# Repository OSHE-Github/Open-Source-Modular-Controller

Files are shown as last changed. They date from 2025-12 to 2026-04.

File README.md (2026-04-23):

# Open Source Modular Controller

Using a modular, reconfigurable hardware architecture to create a customizable USB HID game controller.

## Project Details

The Open Source Modular Controller project is a fully modular and customizable gaming input system. Users can freely rearrange joysticks, buttons, and future input modules on a set of interchangeable receiver boards to build a layout that fits their gameplay style, ergonomic needs, or accessibility requirements.

The controller connects over USB and is recognized as a standard Human Interface Device (HID) with no additional drivers required.

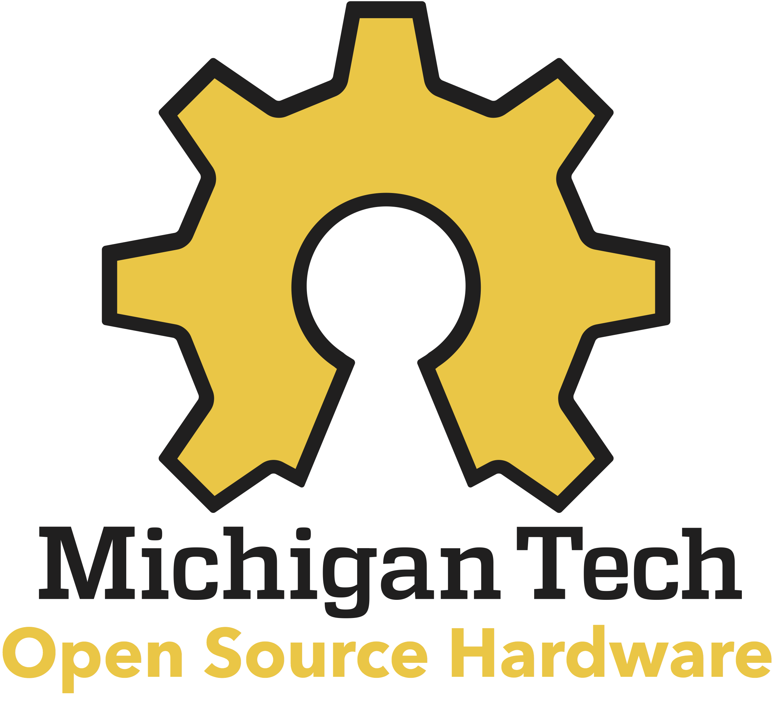
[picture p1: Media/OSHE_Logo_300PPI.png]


## Current State

The current prototype includes:
- A functional ESP32‑S3‑based main controller
- Hot-swappable joystick and button modules
- Receiver boards that can be placed anywhere in the 3D‑printed shell
- USB HID communication via TinyUSB

The system operates as a recognized USB gamepad on Windows. Some hardware issues were identified and corrected in updated revisions.

## Project Structure

The repository is organized as follows:
1. **Firmware** – ESP32‑S3 code handling HID communication and module input processing.  
   *Link: [Firmware](/Controller%20Code/Firmware.md)*
2. **Software** – PC‑side utilities or test scripts (coming soon).  
3. **Hardware** – KiCad project files, schematics, PCBs, and 3D‑printed shell models.  
   *Link: [Hardware](/Hardware/Hardware.md)*
4. **Documentation** – Assembly instructions, diagrams, semester report, and testing notes.  
   *Link: [Documentation](/Documents/Documents.md)*

## Features

- Modular input modules (buttons, joystick, future sensors)
- Repositionable input layout using multiple receiver boards
- ESP32‑S3 native USB HID support
- Open‑source hardware and firmware
- 3D‑printable ergonomic controller shell

## System Architecture

Core system components include:
- **Receiver boards** distributing power, signals, and micro-controller
- **Module boards** for inputs (joystick/button)
- **3D‑printed enclosure** with heat‑set inserts for secure mounting

USB HID enumeration and report handling are implemented using TinyUSB. Modules communicate through standardized connectors to the controller board.

## Bill of Materials
A full BOM including the ESP32‑S3 boards, connector sets, resistors, capacitors, PCBs, wire, and 3D‑printed components is provided in the documentation.  
*[BOM](/Documents/BOM.md)*

## Tools Used
### Software
- Arduino IDE
- KiCad
- OnShape (frame design)
- GitHub Desktop
- Cura slicer

### Hardware
- 3D printer
- Soldering iron
- Hot air station
- Multimeter
- Tweezers

## Assembly Overview
1. Gather materials (refer to BOM).  
2. Order PCBs (Gerber files included).  
3. 3D print shell and module housings.  
4. Clean and prepare boards.  
5. Solder components (headers, ESP32 module, connectors, buttons/joysticks).  
6. Upload firmware via Arduino IDE.  
7. Install modules into the shell.  
8. Test controller.  

[Full assembly guide](/Documents/Assembly%20guide.md)

## What the Project Could Use Next
1. On‑board processing for more advanced input mapping
2. PCB adjustment and testing
3. Wireless mode using Bluetooth HID
4. Additional module types (battery, gyroscope, sliders, touchpads)

## Semester End Report
For the Enterprise Program at Michigan Tech there is a end of semester and project report for the project to summarize the progress of the project. [Link](/Documents/Final%20Report%20Spring%202026.pdf)

## Acknowledgements
This project is supported by the Open Source Hardware Enterprise at Michigan Technological University.

## Helpful Links
- [TinyUSB](https://docs.tinyusb.org/en/latest/)
- [Gamepad tester](https://hardwaretester.com/gamepad)

## References

[GitHub Doc](https://docs.github.com/en/get-started/writing-on-github/getting-started-with-writing-and-formatting-on-github/basic-writing-and-formatting-syntax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)

[Alpakka conroller](https://inputlabs.io/alpakka)

[Proteus ControllerTM kit](https://byowave.com/products/proteus-controller )

[Thrustmaster](https://eshop.thrustmaster.com/en_us/gamepads/pc.html)

[Adafruit ADS1X15 Library](https://github.com/adafruit/Adafruit_ADS1X15)

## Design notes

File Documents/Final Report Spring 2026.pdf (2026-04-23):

# Project Report: Open Source Modular Controller

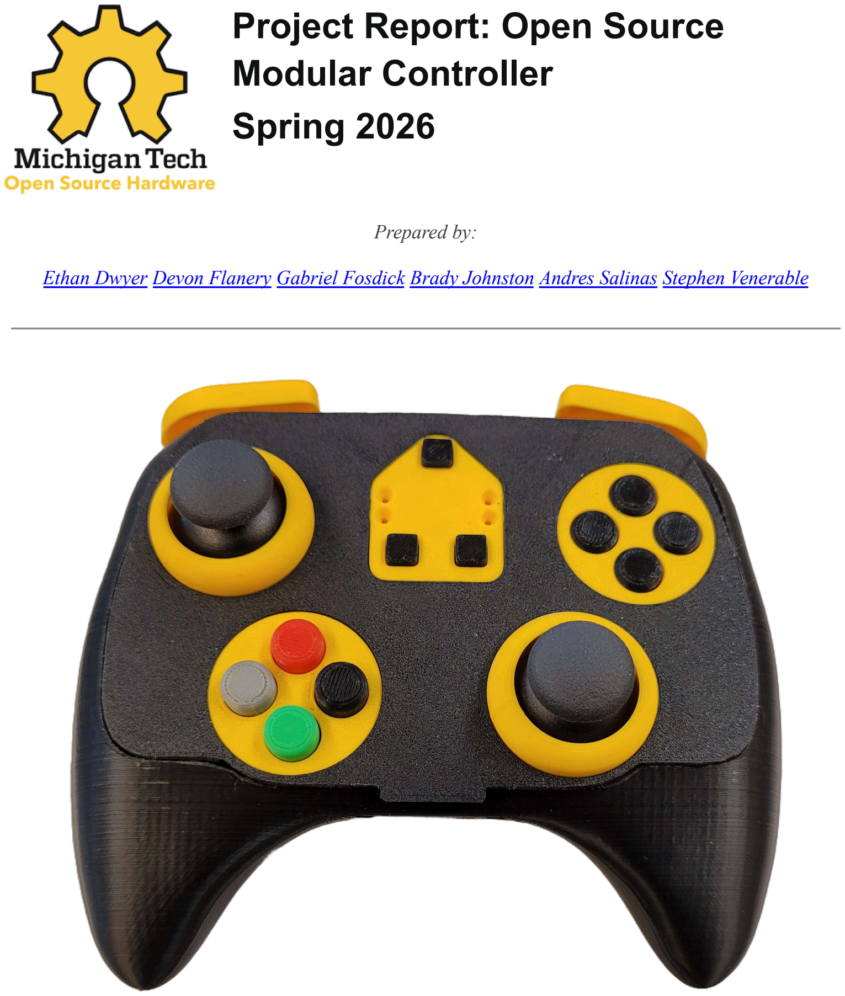
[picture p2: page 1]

# Spring 2026

Prepared by:

Ethan Dwyer Devon Flanery Gabriel Fosdick Brady Johnston Andres Salinas Stephen Venerable

## Table of Contents:

## Executive Summary:

The goal of this project is to design and develop an open-source modular game controller compatible with modern gaming and computing systems. The controller features interchangeable input modules that enable users to customize both the layout and physical placement of controls based on game genre, personal preference, or accessibility needs. By supporting a variety of input types and configurations, the system can be tailored for diverse users and applications, from video games to robotics control. Once assembled, the controller connects directly to standard devices using USB and is recognized as a Human Interface Device (HID) without additional drivers.

Core Technology

At the foundation of the system is the TinyUSB library, which allows communication within the USB HID framework. This approach eliminates the need for dedicated drivers and ensures compatibility across Windows, macOS, and Linux platforms, providing a plug-and-play experience for end users. On top of that is the i2c protocol that communicates between the modules and the Microcontroller, that handles the identification and input data streaming.

Innovation

The project’s defining innovation lies in its fully modular and spatially flexible architecture. Each controller consists of removable button and joystick modules that attach to detachable receiver boards. These receiver boards can be placed anywhere on a custom chassis, giving users the freedom to design their own controller shapes and ergonomics. This allows complete reconfiguration of both the electronic and physical layout, something not possible with commercial controllers. The system is designed to be approachable for those with little to no electronics experience while remaining highly extensible for makers and developers.

Development Highlights

Over the course of the semester, the team refined and developed the second-generation receiver boards and the two modules: a button input and a joystick, with the addition of a bumper/trigger module. The base system successfully interfaced with a Windows PC and functioned in real-world gaming scenarios. Future work will expand on this foundation by adding module identification and refining the communication protocol to support more features.

Impact

This project represents a meaningful advancement in customizable controller design. Its modular and repositionable hardware offers new possibilities for makers, competitive gamers, and individuals with physical disabilities, enabling truly personalized ergonomics and input arrangements. By combining open-source firmware with hardware flexibility, the system empowers users to create, share, and refine their own control interfaces, making high-performance and adaptive hardware accessible to everyone.

## Main Product Image:

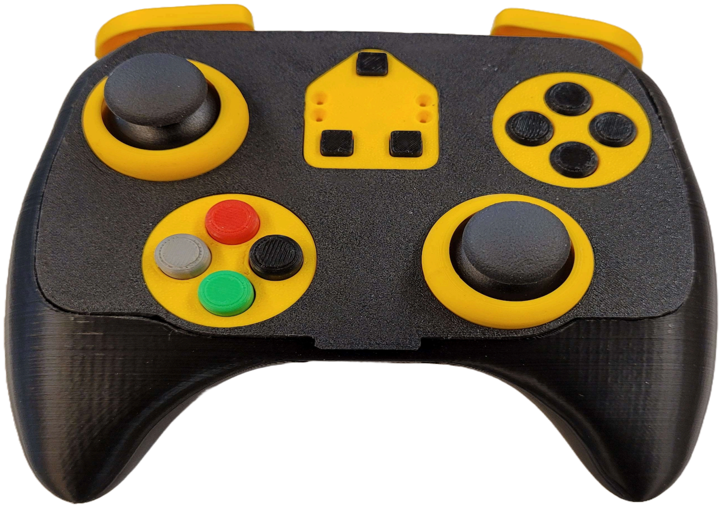
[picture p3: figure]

Figure 1: Main Controller Image

## Project Description:

The project was the design and implementation of a functional prototype for a modular, open-source game controller compatible with modern computing systems. The primary goal was to develop a controller system in which every major input—joysticks, buttons, and future modules—can be physically rearranged or replaced, giving users the freedom to build a controller layout that matches their play style or accessibility needs.

The first semester's development began with a breadboard-based proof of concept used to verify signal routing, input functionality, and USB communication. Once validated, the team progressed to designing custom printed circuit boards (PCBs) for the joystick and button modules, the receiver boards, and an ESP32-based carrier board serving as the main controller.

This second semester’s focused on the modularity and hot-swapability of the different modules and making the enclosure more comfortable for the users . This was done by switching the modules to integrated circuits that have i2c compatibility so all the modules can share the same communication bus.

A 3D-printed enclosure was then modeled and fabricated to house the assembled electronics. Each receiver board connects to the module boards through pogo header pins or JST connectors, allowing the modules to be placed anywhere within a custom chassis. This spatial flexibility is the defining feature of the system, enabling users to create their own controller shapes and layouts to suit personal or accessibility requirements.

The controller’s firmware utilizes the TinyUSB library to manage communication through the USB Human Interface Device (HID) framework, ensuring plug-and-play functionality without custom drivers. The current prototype successfully interfaces with Windows systems and is fully recognized as a standard game controller. Although additional inputs such as bumpers and triggers are planned for future iterations, the completed prototype establishes a robust hardware and software foundation for a fully modular and reconfigurable controller platform.

## Methodology:

System Architecture

The modular controller system was built around the ESP32-S3 microcontroller, chosen for its native support of both USB and Bluetooth HID (Human Interface Device) communication. This capability allows the controller to function as a USB peripheral without the need for custom drivers and provide wireless compatibility for future iterations of this project. The ESP32-S3 communicates the controller’s given inputs from each module to the host system. The transmission between the modules and microcontroller is done through a main receiver board.

The main receive board hosts the controller with standard connector pins and the modules with either pogo pins or JST connectors depending on the controller shell design. Using I2C the controller communicates with each module based on its type and position. Each module has a different I2C address based on which type of module it is (joystick, button, etc.) and an address translator placed at each slot provides a different position to the microcontroller.

USB HID Implementation

Communication between the controller and host system relies on the USB HID standard, which defines how input devices transmit data to computers and consoles. When a device is connected, the host begins a process called enumeration, during which it requests a series of descriptors from the device. These descriptors identify the device type, power requirements, and data structure:

- Device Descriptor: Specifies the vendor ID, product ID, and device class.
- Configuration and Interface Descriptors: Define endpoints, interfaces, and required power.

- HID and Report Descriptors: Describe the logical format of inputs such as buttons and joystick axes.
- String Descriptors (optional): Provide human-readable information, such as product name or manufacturer.

Once the enumeration sequence is complete, the device begins sending HID reports, which contain button states and analog axis values. These reports are continuously exchanged with the host to provide real-time input recognition. Using the TinyUSB library, the ESP32-S3 handles all enumeration, descriptor generation, and report formatting internally, allowing the controller to be recognized as a standard gamepad on Windows without additional drivers.

Component Selection and Design Considerations

Component selection emphasized functionality, modularity, and cost efficiency. The ESP32-S3 was selected for its integrated USB OTG interface, Bluetooth LE support, and sufficient processing resources for handling multiple modular inputs. Standard pin headers were chosen as the initial connection method between modules and receiver boards due to their availability, affordability, and mechanical stability. The current version transitions to magnetic pogo-pin connectors to simplify module swapping and improve durability.

All printed circuit boards (PCBs) were designed in-house and fabricated through a low-cost prototyping service. Careful attention was given to connector orientation, trace routing, and power distribution to ensure reliability and ease of assembly.

I2C Components

To further increase the modularity and functionality of the controller, we wanted to be able to automatically detect module changes while the controller was in use. We decided to implement this using I2C. Using SPI or adding small microcontrollers to each module were early ideas, but were quickly dismissed. We implemented this by adding I2C-capable IO expanders to each button module and I2C-capable ADCs to each joystick module. By scanning for I2C addresses, we were able to detect a module’s presence, as well as determine its type. The original plan was to store each module’s information data on an EEPROM, but we ran into some issues regarding this. Each module has an EEPROM soldered onto it, but our firmware does not utilize them. Input data from the buttons/joysticks is read by the IO Expander or ADC and then transmitted to the MCU through I2C.

Mechanical and Ergonomic Design

The physical design of the controller is built to house the main receiver board. The consistent shape and sizing enable the modularity of the controller. Each module, Joystick, Buttons, and Bumper, all have the same footprint for both ease of manufacturing and symmetry. The 3D-printed enclosure provides sufficient internal space for all modules. Extended side grips were added to improve handling during gameplay without compromising the modular placement of receivers.

Summary

This methodology established a repeatable framework for modular hardware development: from microcontroller selection and USB communication setup to enclosure design and fabrication. The resulting prototype demonstrates reliable USB HID communication, functional modular inputs, and a flexible architecture ready for continued expansion and refinement.

## Bill of Materials:

The current design uses a single, updated controller configuration built around the Seeed Studio XIAO ESP32-S3 Plus as the main microcontroller. This approach simplifies the overall system by standardizing the hardware across all modules and reducing assembly complexity. The design is divided into several functional boards including the receiver, button, joystick, bumper, and navigation boards each with its own supporting components such as EEPROMs, I/O expanders, resistors, and capacitors. Custom PCBs are used for each subsystem, along with pogo pin connections and JST connectors to enable modularity and easier assembly. This structure allows for a flexible and scalable controller design while keeping the total cost and component count manageable.

Table 1: Bill of materials

Part name | Desc | Qty. | Total | Link
Receiver Board | | Total
LTC4317 | Address Translator | 4 | $20.72 | Digikey.com (https://www.digikey.com/en/products/detail/analog-devices-inc/LTC4317CDHC-PBF/5297623)
24LC02BT-I/OT | 2 kbit EEPROM | 1 | $0.31 | Digikey.com (https://www.digikey.com/en/products/detail/microchip-technology/24LC02BT-I-OT/443519)
PCF8574DWR | 8 bit io expander | 1 | $1.99 | Digikey.com (https://www.digikey.com/en/products/detail/texas-instruments/PCF8574DWR/484579)
603_1208 metric | 10 uF capacitor | 3 | $0.03 | Digikey.com (https://www.digikey.com/en/products/detail/samsung-electro-mechanics/CL21A106KOQNNNE/3886754)
603_1208 metric | .1 uF capacitor | 4 | $0.24 | Digikey.com (https://www.digikey.com/en/products/detail/yageo/CC0603KRX7R7BB104/302822)
603_1208 metric | 10 kΩ resistors | 27 | $0.24 | Digikey.com (https://www.digikey.com/en/products/detail/yageo/RC0603FR-0710KL/726880)
XIAO ESP32-S3 Plus | Seeed Studio XIAO ESP32-S3 Plus | 1 | $7.90 | Seeedstudio.com (https://www.seeedstudio.com/Seeed-Studio-XIAO-ESP32S3-Plus-p-6361.html)
PCB | Main Receiver Board | 1 | $29.00
603_1208 metric | 0 kΩ resistors | 1 | $0.10 | Digikey.com (https://www.digikey.com/en/products/detail/yageo/RC0603JR-070RL/726675)
603_1208 metric | 102 kΩ resistors | 1 | $0.10 | Digikey.com (https://www.digikey.com/en/products/detail/yageo/RC0603FR-07102KL/726891)
603_1208 metric | 182 kΩ resistors | 1 | $0.10 | Digikey.com (https://www.digikey.com/en/products/detail/stackpole-electronics-inc/RMCF0603FT182K/1760990)
603_1208 metric | 280 kΩ resistors | 1 | $0.10 | Digikey.com (https://www.digikey.com/en/products/detail/yageo/RC0603FR-07280KL/727112)
603_1208 metric | 392 kΩ resistors | 1 | $0.10 | Digikey.com (https://www.digikey.com/en/products/detail/yageo/RC0603FR-07392KL/727201)
603_1208 metric | 523 kΩ resistors | 1 | $0.10 | Digikey.com (https://www.digikey.com/en/products/detail/yageo/RC0603FR-07523KL/727292)
603_1208 metric | 681 kΩ resistors | 1 | $0.10 | Digikey.com (https://www.digikey.com/en/products/detail/yageo/RT0603FRE07681KL/5929212)
603_1208 metric | 887 kΩ resistors | 1 | $0.10 | Digikey.com (https://www.digikey.com/en/products/detail/yageo/RC0603FR-07887KL/727417)
603_1208 metric | 976 kΩ resistors | 1 | $0.10 | Digikey.com (https://www.digikey.com/en/products/detail/yageo/RC0603FR-07976KL/727442)
603_1208 metric | 1 MΩ resistors | 5 | $0.40 | Digikey.com (https://www.digikey.com/en/products/detail/yageo/RC0603FR-071ML/726844)
1x8 smd pogo pins | Pogo pin connection | 8 | $42.48 | Digikey.com (https://www.digikey.com/en/products/detail/digikey-va/811-22-008-30-000101/682276)
JST SH 4-pin Connector | JST SH 4-pin Right Angle Connector (10-pack) - Qwiic Compatible | 1 | $3.95 | Adafruit.com (https://www.adafruit.com/product/4208)
Subtotal: | | 65 | $108.16

Part name | Desc | Qty. | Total | Link
Button Board
24LC02BT-I/OT | 2 kbit EEPROM | 1 | $0.31 | Digikey.com (https://www.digikey.com/en/products/detail/microchip-technology/24LC02BT-I-OT/443519)
PCF8574DWR | 8 bit io expander | 1 | $1.99 | Digikey.com (https://www.digikey.com/en/products/detail/texas-instruments/PCF8574DWR/484579)
SKQGABE010 | Button | 4 | $1.24 | Digikey.com (https://www.digikey.com/en/products/detail/alps-alpine/SKQGABE010/19529161)
PCB | Button Board | 1 | $7.00
Subtotal: | | 7 | $10.54
Joystick
24LC02BT-I/OT | 2 kbit EEPROM | 1 | $0.31 | Digikey.com (https://www.digikey.com/en/products/detail/microchip-technology/24LC02BT-I-OT/443519)
ADS1115IDGST | ADC | 1 | $6.29 | Digikey.com (https://www.digikey.com/en/products/detail/texas-instruments/ADS1115IDGST/2123298)
603_1208 metric | 10 kΩ resistors | 1 | $0.10 | Digikey.com (https://www.digikey.com/en/products/detail/yageo/RC0603FR-0710KL/726880)
9032 | Joysticks | 1 | $5.25 | Digikey.com (https://www.digikey.com/en/products/detail/sparkfun-electronics/09032/6823623)
PCB | Joysticks Board | 1 | $7.00
Subtotal: | | 5 | $18.95
Bumper Board
24LC02BT-I/OT | 2 kbit EEPROM | 1 | $0.31 | Digikey.com (https://www.digikey.com/en/products/detail/microchip-technology/24LC02BT-I-OT/443519)
PCF8574DWR | 8 bit io expander | 1 | $1.99 | Digikey.com (https://www.digikey.com/en/products/detail/texas-instruments/PCF8574DWR/484579)
PCB | Bumper Board | 1 | $7.00
Key switches | Switches for bumpers and triggers | 1 | $4.49 | Amazon.com (https://www.amazon.com/BlingKingdom-Replacement-Mechanical-Keyboard-Dustproof/dp/B0DSHTPSL3)
Subtotal: | | 4 | $13.79
Nav/master Board
24LC02BT-I/OT | 2 kbit EEPROM | 1 | $0.31 | Digikey.com (https://www.digikey.com/en/products/detail/microchip-technology/24LC02BT-I-OT/443519)
PCF8574DWR | 8 bit io expander | 1 | $1.99 | Digikey.com (https://www.digikey.com/en/products/detail/texas-instruments/PCF8574DWR/484579)
LTST-C193TBKT-5A | Blue LED | 4 | $0.72 | Digikey.com (https://www.digikey.com/en/products/detail/liteon/LTST-C193TBKT-5A/2053656)
B3F-1000 | Button | 4 | $0.96 | Digikey.com (https://www.digikey.com/en/products/detail/omron-electronics-inc-emc-div/B3F-1000/33150)
PCB | Nav Board | 1 | $7.00
319-10-104-00-006000 | pogo pin strikers | 3 | $8.94 | Digikey.com (https://www.digikey.com/en/products/detail/mill-max-manufacturing-corp/319-10-104-00-006000/5176105)
Subtotal: | | 14 | $19.92
Total: | | 95 | $171.36

## Tools Used:

Software

Table 2: Software used

Name | Description | Price | Link
GitHub Desktop | Used to share updates and
versions.
Free | GitHub.com (https://desktop.github.com/download/)
Arduino IDE | Used as the programming platform. | Free | Arduino.cc (https://docs.arduino.cc/software/ide/)
KiCAD | The program was used for creating
the PCB.
Free | KiCAD.com (https://www.kicad.org/)
OnShape | Used for the frame design. | Free | OnShape.com (https://www.onshape.com/en/)
Ultimaker Cura | Used as a slicer for the 3-D printed
glasses frame.
Free | Ultimaker.com (https://ultimaker.com/software/ultimaker-cura/)

Total Price

Hardware

Table 3: Hardware used

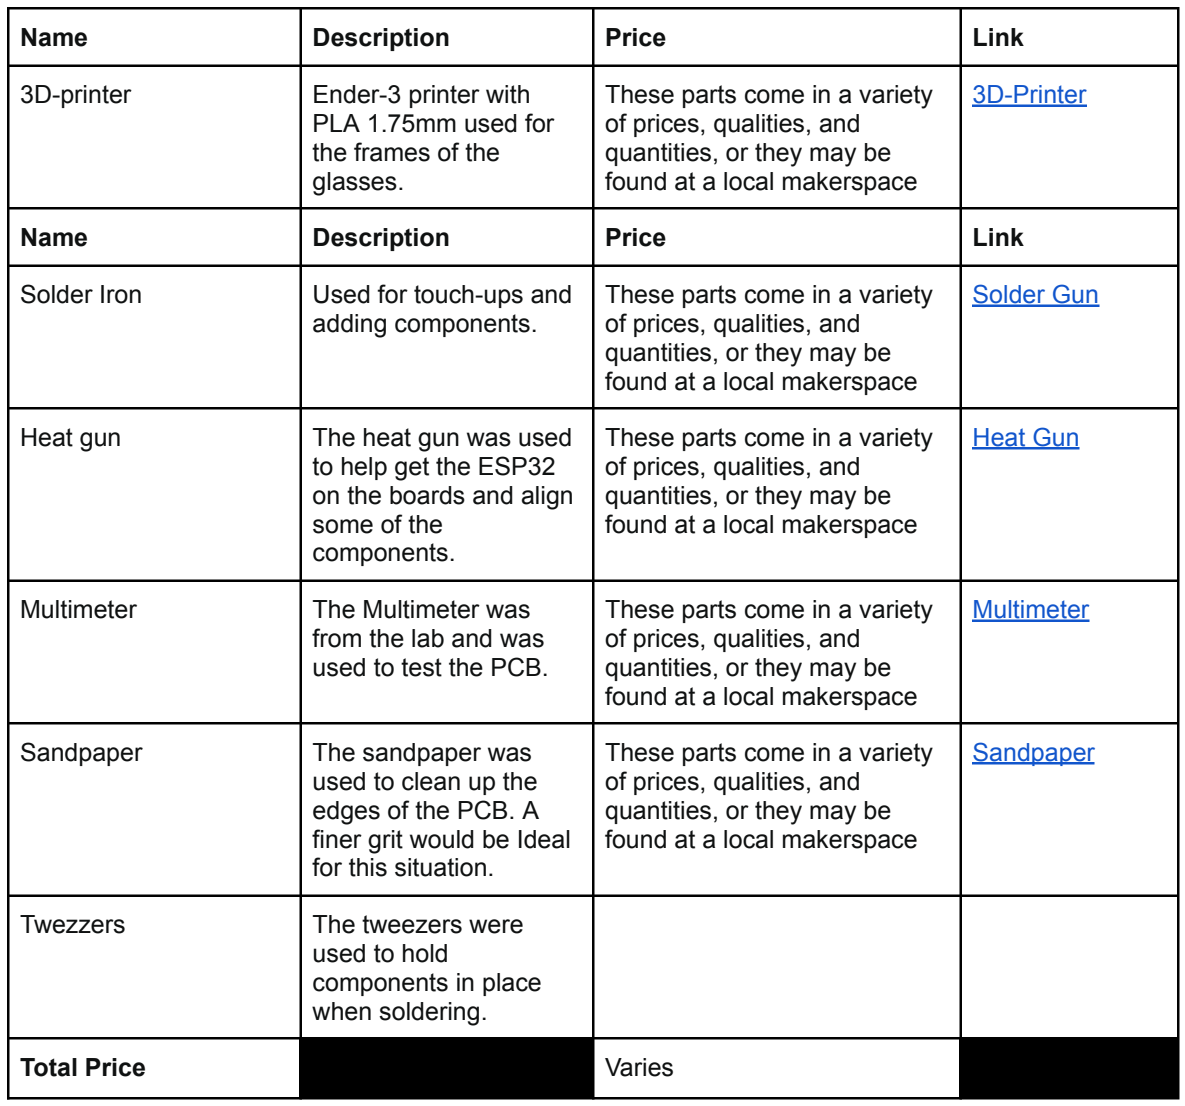
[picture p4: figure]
Name; Description; Price; Link; 3D-printer; Ender-3 printer with; PLA 1.75mm used for the frames of the glasses.; These parts come in a variety of prices, qualities, and quantities, or they may be found at a local makerspace; 3D-Printer; Solder Iron; Used for touch-ups and; adding components.; Solder Gun; Heat gun; The heat gun was used; to help get the ESP32 on the boards and align some of the components.; Heat Gun; Multimeter; The Multimeter was; from the lab and was used to test the PCB.; Sandpaper; The sandpaper was; used to clean up the edges of the PCB. A finer grit would be Ideal for this situation.; Twezzers; The tweezers were; used to hold components in place when soldering.; Total Price; Varies

## Assembly

### 1. Gather Materials

a. Refer to the BOM
b. Download the main GitHub repo branch (link) (https://github.com/OSHE-Github/Open-Source-Modular-Controller)

### 2. Order PCBs

a. Use our PCB manufacturer; the Gerber files are provided in the GitHub repository.

### 3. Print the Shells

a. The shells for the modules are located in the Github directory under Hardware/Module STLs
b. The standard configuration uses seven modules and each module requires the specified parts
i. 1 Master: 1 Master top casing, 1 Master bottom casing, 3 Master buttons
ii. | 2 Bumpers: 1 Joystick top casing, 1 Joystick bottom casing
iii. | 2 Joysticks: 1 Bumper body casing and 2 Bumper caps
iv. | 2 Buttons: 1 Button top casing, 1 Button Bottom casing, 4 non-Master buttons
c. The shell for the main body is located in the Github directory under
| Hardware/Shell/OSMC
i. The full casing can be printed from the .step file
ii. Individual parts can be printed from the .stl files

### 4. Prep the PCB

a. Lightly sand away any edge defects from manufacturing making sure not to
b. Lightly wipe with isopropyl alcohol

### 5. Solder Components

– In this production, blank boards were ordered, and most components were hand-soldered with a soldering iron, solder paste, and hot air soldering station.

a. Receiver Board
i. Start by soldering on all the SMD components such as the capacitors, resistors, and
| address translators. This is done easiest using a reflow oven or a hot pate.
ii. | Next, solder all of the pogo pins/pin headers and through hole components.
iii. | Finally, solder on the JST connectors if you want to have any off board modules.

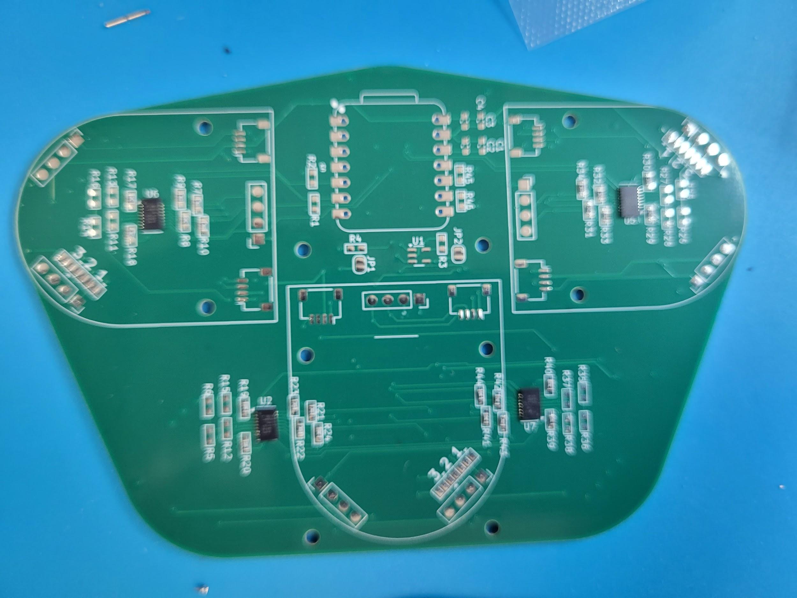
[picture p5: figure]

Figure 4: Receiver Board Module

b. Joystick Modules
i. Solder the joystick into the designated positions on the PCB, keeping each button flat against the board.
ii. | Inspect all joints to confirm solid solder connections and verify that the buttons click freely without obstruction.
iii. | Place the module in the joystick module shell, and mark the shell with where the up arrow is pointing.

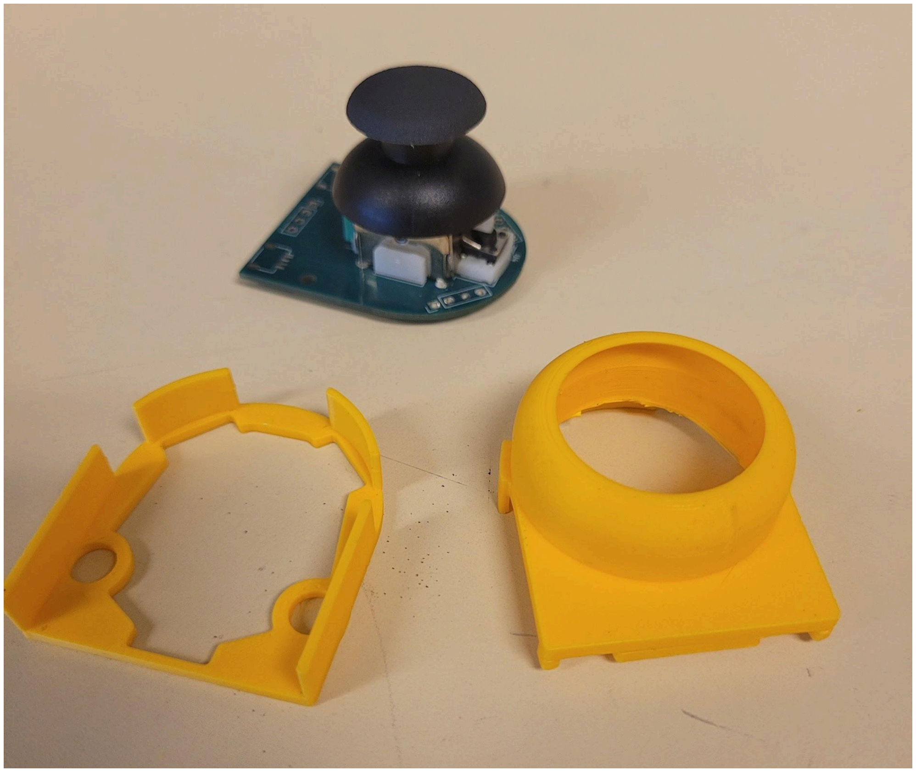
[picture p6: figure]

Figure 6: Joystick Module (soldered, apart)

c. Button Modules

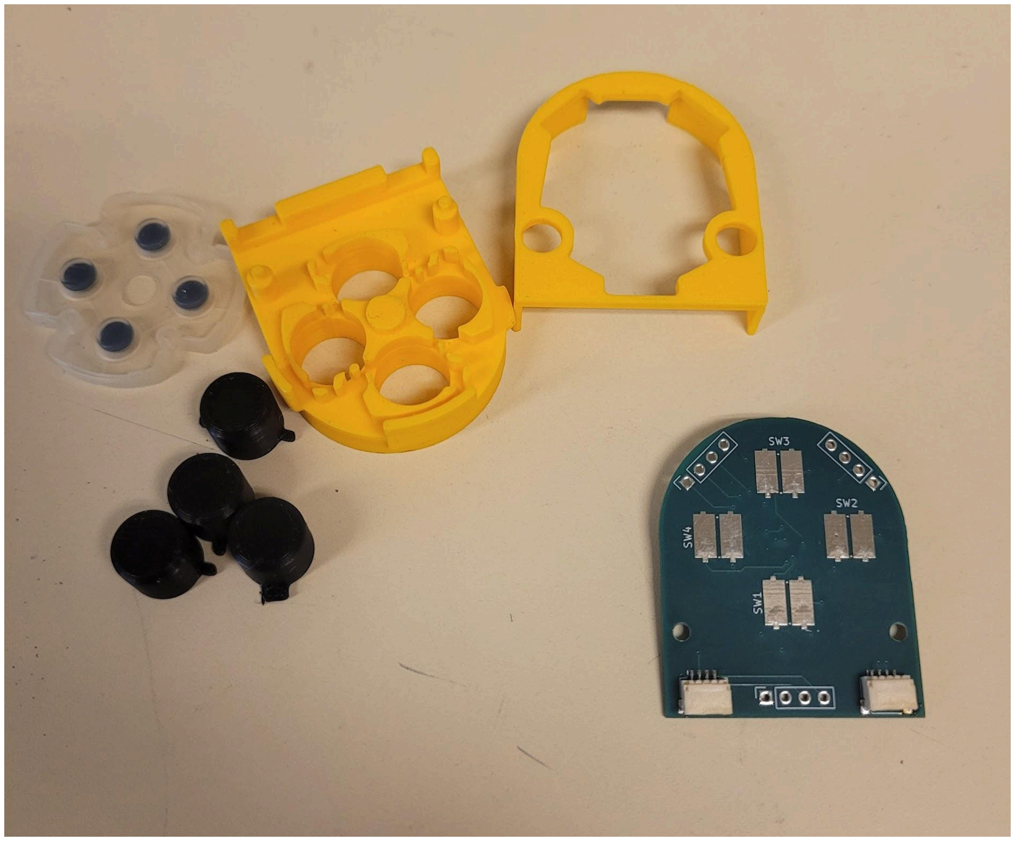
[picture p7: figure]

Figure 7: Button Module (membrance, apart)

– The button modules can be assembled in two different ways. This depends on if you want to use traditional membrane buttons or solder on mechanical buttons.

i. If you would like to use mechanical buttons, solder the four push buttons into their designated labeled positions on the PCB, keeping each button flat against the board.

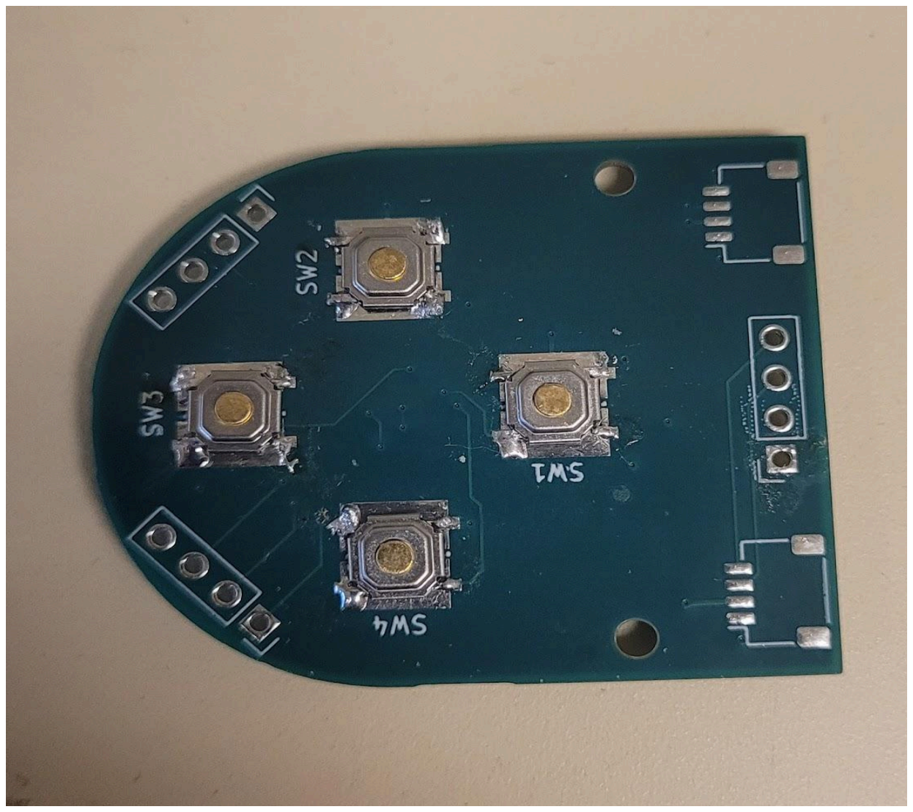
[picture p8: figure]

Figure 8: Button Module (mechanical, soldered)

ii. | Solder EEPROM and IO expanders to the back of the board. This is done easiest with a reflow oven or a hot plate.
iii. | If you don’t use conventional connector pins, you can solder in the JST connectors at this point.

iv. (Optional) Glue the top plate onto the module.

d. Master/Navigation module
i. Solder EEPROM and IO expanders to the back of the board. This is done easiest
| with a reflow oven or a hot plate.
ii. | Solder the mechanical buttons onto the board.
iii. | Solder on the spacer pogo striker headers.

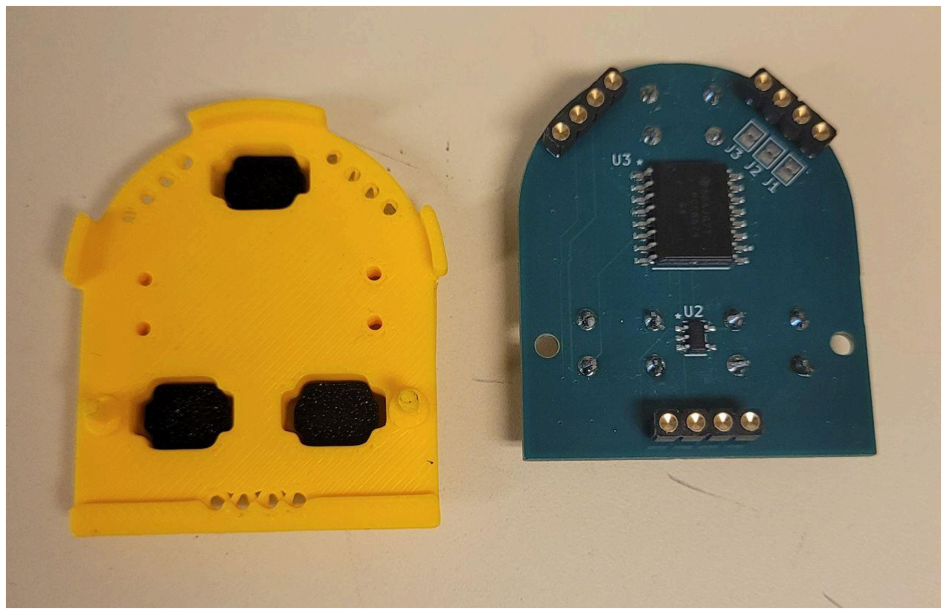
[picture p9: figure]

Figure 9: Master/Navigation Module (soldered, apart)

iv. (Optional) Glue the top plate onto the module.

e. Bumper/Trigger module
i. Solder EEPROM and IO expanders to the back of the board. This is done easiest
| with a reflow oven or a hot plate.
ii. | Solder the through hole key switches onto the board.

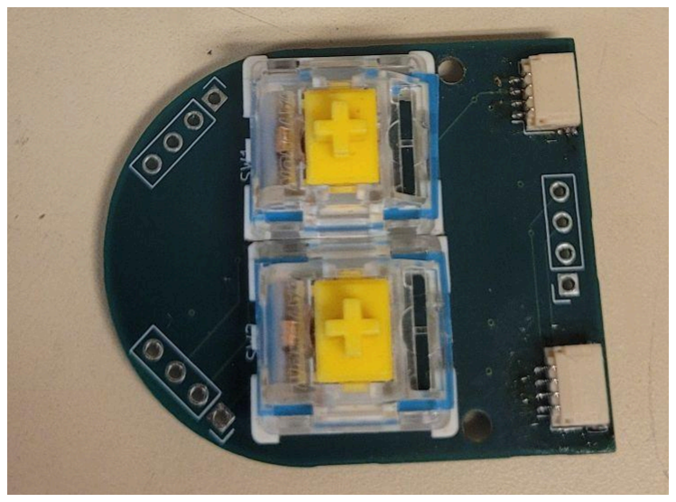
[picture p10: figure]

Figure 10: Bumper/Trigger Module(soldered)

iii. | Solder the JST connectors
iv. | Optional) Glue the top plate onto the module.

### 6. Uploading code

a. Install Arduino IDE.
b. Add ESP32 boards manager URL:
i. In Arduino IDE, select File -> Preferences. Paste this URL in the additional boards
| manager URL box: “https://espressif.github.io/arduino-esp32/package_esp32_index.json”.
c. Install the ESP32 board package.
i. Next, select “Tools” -> “Board: (whatever)” -> “Boards Manager”. Search for ESP32
| and install the board package from Espressif Systems.
d. Install the Adafruit ADS1115 library
i. Next, select “Tools” -> “Manage Libraries…”. Search Adafruit_ADS11X5 and install
| the library by Adafruit .
e. Import project files into Arduino IDE.
f. Connect via USB.

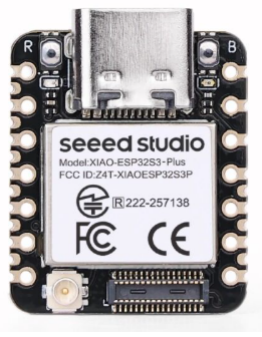
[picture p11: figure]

Figure 11: Seeed Studio XIAO ESP32-S3 Plus

g. Select the ESP32-S3 Dev Module and the correct COM port.
i. The COM port could be different depending on your computer.

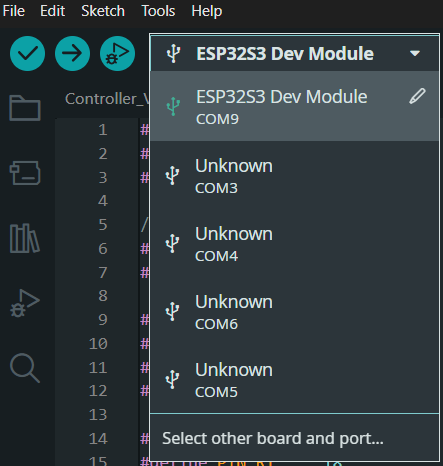
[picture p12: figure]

Figure 12: Arduino IDE COM Selection

h. Select “Tools”, then change to the match following settings.

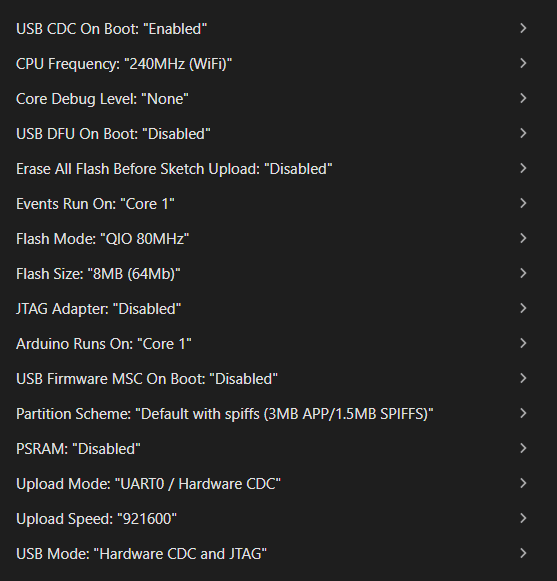
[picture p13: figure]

Figure 13: Board Configuration

i. Compile and upload the sketch onto the ESP32 via USB-C.

### 7. Assemble in-shell

a. Place receiver board in shell and mark screw hole locations
b. Remove the receiver board and embed the M3 heat set inserts where you just marked, making sure the inserts are level with the surface.
c. Repeat steps a and b for the two bumper/trigger modules
d. Wire the JST connectors from the bumper/trigger modules, through the slots, connecting to the JST connectors on the backside of the receiver board e. Screw the receiver board and bumper/trigger modules in their respective slots with M3 screws through the PCBs and into the placed heat set inserts
f. Place the master module resting on the center module pogo pins.
g. Place the joystick/button modules, in the configuration chosen, resting on the outer pogo pin sets.
h. Push the top plate into place, making sure all inputs align with their respective holes.
i. Push the bottom plate into the main shell
j. To move top modules, push up on the bottom tab of the top plate, and repeat steps g. - i. with the new configuration

### 8. Testing

a. Use a program such as Steam Input or gamepad-tester.
b. Verify that every button and joystick direction registers properly.

## Characterization Data:

Input Testing

Testing the inputs was straightforward. First was testing all the buttons and joysticks. This was tested within the gamepad tester website. The website shows a picture of a controller on the website and highlights the input that it thinks it is receiving from our controller. From this test, we found that the top left module on the controller face doesn’t work; this is explained more in the hardware continuity section.

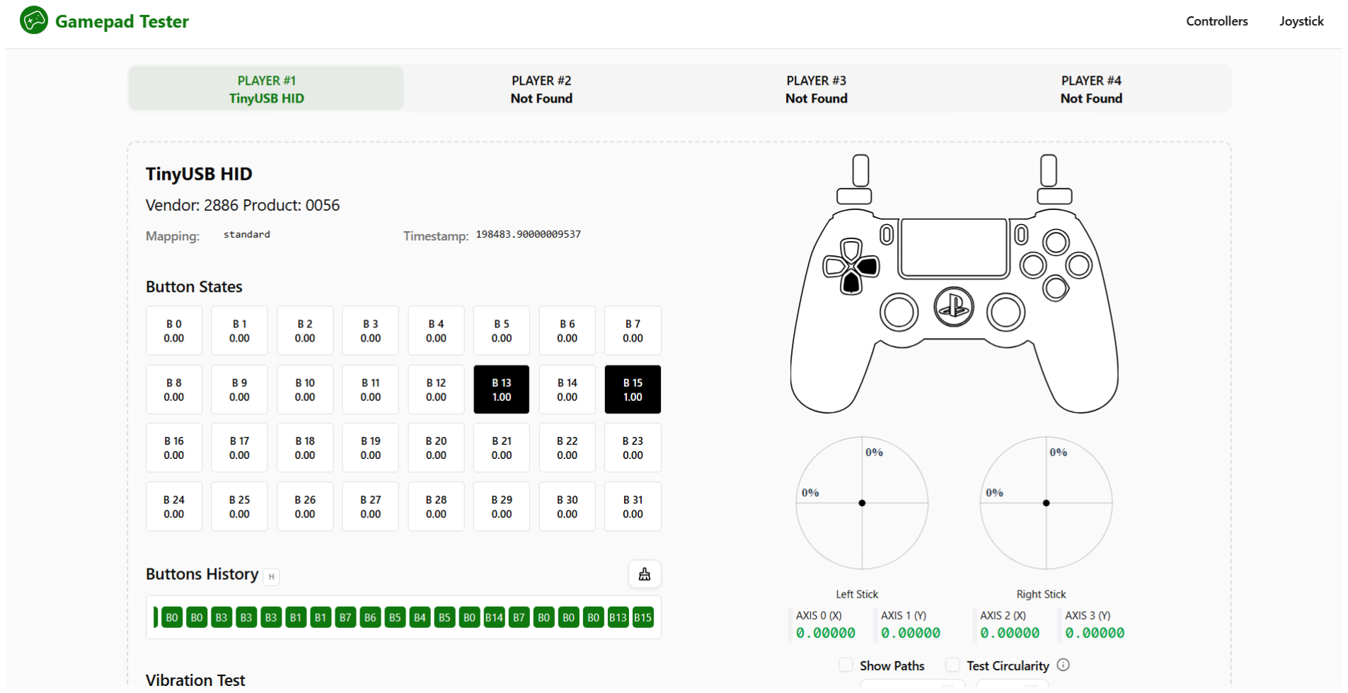
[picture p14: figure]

Figure 13: Gamepad Tester Example

Ergonomic Design

To see how the controller’s ergonomics felt to others, we asked random people at Michigan Tech to hold the controller and write down their thoughts. The responses were mostly positive, with the main comments being that the size was too big, specifically relating to the triggers.

Table 4: Ergonomics Feedback

Name of Reviewer | Comments
Matt | I like the modularity
Kyle | Cool idea!
Daniel | Fits my hand great, triggers are a bit big.
Kegan | Works fine, dislike the back and how my fingers fit on it
Gabriel | Joysticks are far from buttons
Brandan | Great fit!
Madison | A little big for smaller hands
Austin | No place to rest my fingers, would be accidentally pressing triggers.
Jonathan | Bolstering by middle + ring finger is a bit thin
Patrick | Top controllers too far.

Hardware Continuity

When designing the board, there was a misplace on the i2c lines on the left module slots. This stopped the communication with the two modules on that side that prevented the addressing of the modules. To fix this problem wires were routed from the i2c lines off the microcontroller to reach over to that side to the i2c lines and the address translator of that side was removed. In the current pcb revision, this has been fixed by reducing the number of components that the signal passes by to get to the address translator.

The other problem was that the data and clock line of the module upper left module were swapped. This caused the module to not be detected and go down the rabbit hole of why that module does not work. This module slot was not able to get working but was fixed on the pcb revision.

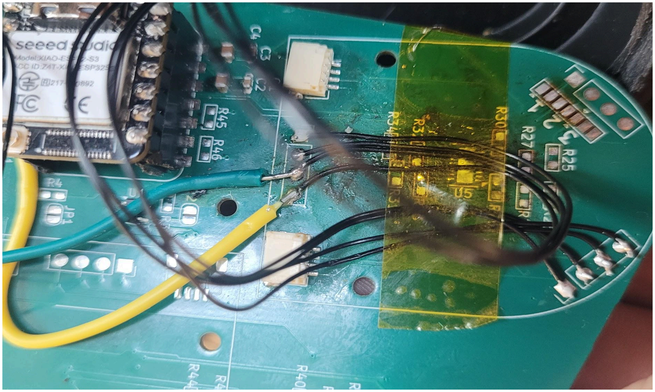
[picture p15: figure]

Figure 15: I2C fix

## Standards:

Open Source Hardware Standards [1]:

1. Documentation
2. Scope
3. Necessary Software
4. Derived Works
5. Free Redistribution
6. Attribution
7. No Discrimination Against Persons or Groups
8. No Discrimination Against Fields of Endeavor
9. Distribution of License
10. License Must Not Be Specific to a Product
11. License Must Not Restrict Other Hardware or Software
12. License Must Be Technology-Neutral

## Recommendations for Future Work:

Some recommendations for future additions to this project should focus on improving both manufacturability and functionality of the system. One key area is the use of more hand-solderable components, which would simplify assembly, reduce reliance on specialized equipment, and make iterative prototyping more accessible. Changing the IC on the joystick modules to use a larger chip would allow more addresses without the use of the address translators and be more hand solderable. Expanding the code to enable more advanced input mapping, allowing the device to support customizable controls and more complex interaction schemes without external computation. Further PCB refinement and testing will be important to enhance reliability, signal integrity, and overall performance. Integrating a wireless mode using Bluetooth HID would significantly increase usability and portability by removing the need for physical connections. Finally, exploring additional module types—such as battery integration, gyroscopes, sliders, and touchpads—would broaden the system’s versatility and open up new application possibilities.

# Sponsors/Acknowledgements:

This project was self-sponsored by the Open Source Hardware Enterprise at Michigan Technological University.

# References:

[1] “OSHW - Definition of Free Cultural Works,” Freedomdefined.org, 2023. https://freedomdefined.org/OSHW
[2] “Alpakka Controller,” Input Labs, https://inputlabs.io/alpakka (accessed Dec. 5, 2025).
[3] “ESWAP x 2 pro controller,” ESWAP X2 PRO CONTROLLER | Thrustmaster USA,
https://eshop.thrustmaster.com/en_us/eswap-x2-pro-controller.html (accessed Dec. 5, 2025).
[4] “Gamepad Tester,” Hardware Tester, https://hardwaretester.com/gamepad (accessed Dec. 5, 2025).
[5] “HID Usage Tables FOR Universal Serial Bus (USB).” Available: https://usb.org/sites/default/files/hut1_6.pdf (accessed Sep. 20 2025)
[6] “Proteus ControllerTM kit,” ByoWave Proteus Controller, https://byowave.com/products/proteus-controller (accessed Dec. 5, 2025).
[7] “TinyUSB Library,” GitHub, https://github.com/chegewara/EspTinyUSB (accessed Dec. 5, 2025).

# Appendix:

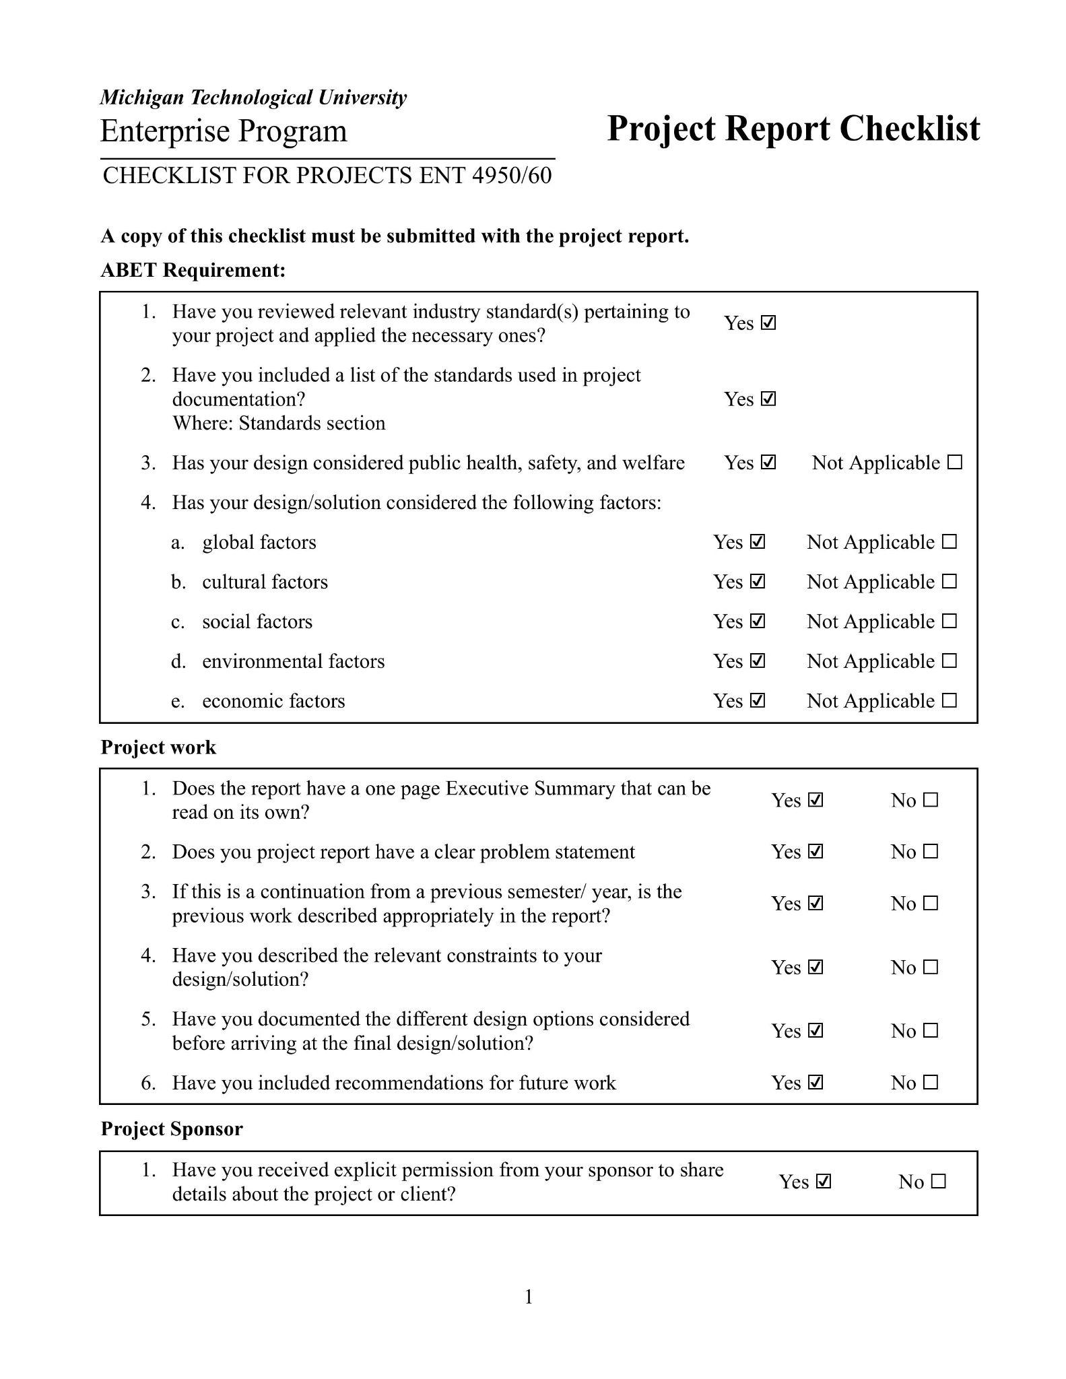
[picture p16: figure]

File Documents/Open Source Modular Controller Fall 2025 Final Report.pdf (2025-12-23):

# Project Report: Open Source Modular Controller

## Fall 2025

Prepared by:

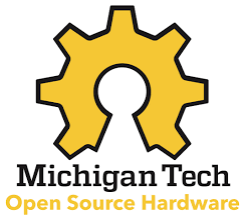
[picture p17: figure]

Ethan Dwyer Devon Flanery Gabriel Fosdick Brady Johnston Andres Salinas Stephen Venerable

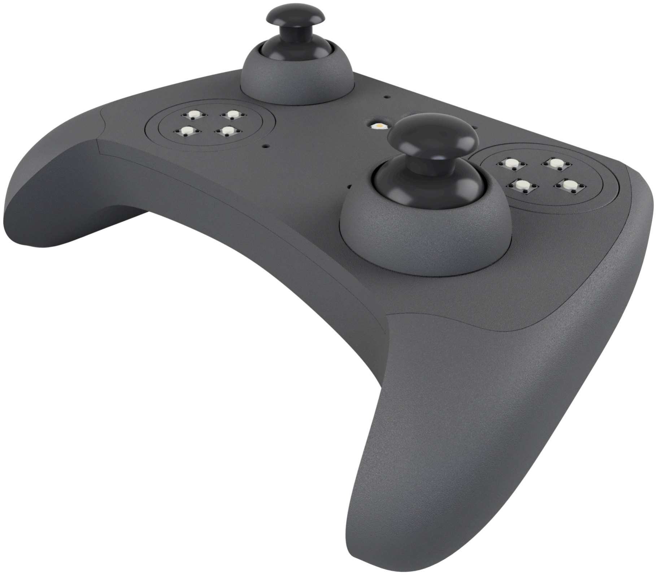
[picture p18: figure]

## Table of Contents:

## Executive Summary:

The goal of this project is to design and develop an open-source modular game controller compatible with modern gaming and computing systems. The controller features interchangeable input modules that enable users to customize both the layout and physical placement of controls based on game genre, personal preference, or accessibility needs. By supporting a variety of input types and configurations, the system can be tailored for diverse users and applications, from video games to robotics control. Once assembled, the controller connects directly to standard devices using USB and is recognized as a Human Interface Device (HID) without additional drivers.

Core Technology
At the foundation of the system is the TinyUSB library, which allows communication within the USB HID framework. This approach eliminates the need for dedicated drivers and ensures compatibility across Windows, macOS, and Linux platforms, providing a plug-and-play experience for end users.

Innovation
The project’s defining innovation lies in its fully modular and spatially flexible architecture. Each controller consists of removable button and joystick modules that attach to detachable receiver boards. These receiver boards can be placed anywhere on a custom chassis, giving users the freedom to design their own controller shapes and ergonomics. This allows complete reconfiguration of both the electronic and physical layout, something not possible with commercial controllers. The system is designed to be approachable for those with little to no electronics experience while remaining highly extensible for makers and developers.

Development Highlights
Over the course of the semester, the team developed the first-generation receiver boards and two initial modules: a button input and a joystick. The base system successfully interfaced with a Windows PC and functioned in real-world gaming scenarios. Future work will expand on this foundation by adding module identification, improving the mechanical design, and refining the inter-module communication protocol to support more advanced features.

Impact
This project represents a meaningful advancement in customizable controller design. Its modular and repositionable hardware offers new possibilities for makers, competitive gamers, and individuals with physical disabilities, enabling truly personalized ergonomics and input arrangements. By combining open-source firmware with hardware flexibility, the system empowers users to create, share, and refine their own control interfaces, making high-performance and adaptive hardware accessible to everyone.

## Main Product Image:

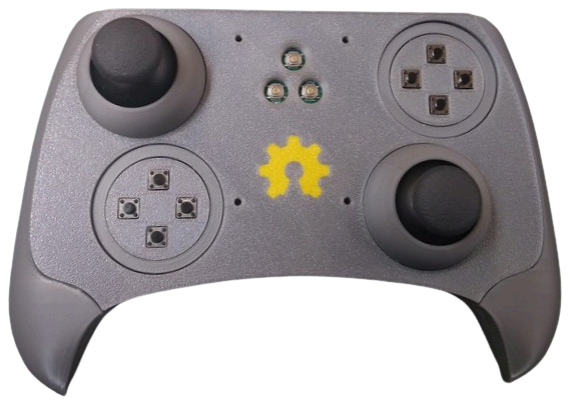
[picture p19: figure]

Figure 1: Main Controller Image

## Project Description:

This semester’s focus was the design and implementation of a functional prototype for a modular, open-source game controller compatible with modern computing systems. The primary goal was to develop a controller system in which every major input—joysticks, buttons, and future modules—can be physically rearranged or replaced, giving users the freedom to build a controller layout that matches their play style or accessibility needs.

Development began with a breadboard-based proof of concept used to verify signal routing, input functionality, and USB communication. Once validated, the team progressed to designing custom printed circuit boards (PCBs) for the joystick and button modules, the receiver boards, and an ESP32-based carrier board serving as the main controller.

A 3D-printed enclosure was then modeled and fabricated to house the assembled electronics. Each receiver board connects to the module boards through standardized headers, allowing the modules to be placed anywhere within a custom chassis. This spatial flexibility is the defining feature of the system, enabling users to create their own controller shapes and layouts to suit personal or accessibility requirements.

The controller’s firmware utilizes the TinyUSB library to manage communication through the USB Human Interface Device (HID) framework, ensuring plug-and-play functionality without custom drivers. The current prototype successfully interfaces with Windows systems and is fully recognized as a standard game controller. Although additional inputs such as bumpers and triggers are planned for future iterations, the completed prototype establishes a robust hardware and software foundation for a fully modular and reconfigurable controller platform.

## Methodology:

System Architecture

The modular controller system was built around the ESP32-S3 microcontroller, chosen for its native support of both USB and Bluetooth HID (Human Interface Device) communication. This capability allows the controller to function as a USB peripheral without requiring custom drivers while also providing wireless compatibility for future iterations.

The system consists of a main controller board, several receiver boards, and interchangeable input modules such as joysticks and buttons. Each receiver board connects to the controller board via standardized pin headers that carry both power and data. Because the receivers can be placed anywhere within a custom chassis, users can define their own controller layout and ergonomics. This modular, spatially flexible design is the foundation of the project’s innovation and enables complete customization of control configurations.

USB HID Implementation

Communication between the controller and host system relies on the USB HID standard, which defines how input devices transmit data to computers and consoles. When a device is connected, the host begins a process called enumeration, during which it requests a series of descriptors from the device. These descriptors identify the device type, power requirements, and data structure:

- Device Descriptor: Specifies the vendor ID, product ID, and device class.
- Configuration and Interface Descriptors: Define endpoints, interfaces, and required power.
- HID and Report Descriptors: Describe the logical format of inputs such as buttons and joystick axes.
- String Descriptors (optional): Provide human-readable information, such as product name or manufacturer.

Once the enumeration sequence is complete, the device begins sending HID reports, which contain button states and analog axis values. These reports are continuously exchanged with the host to provide real-time input recognition. Using the TinyUSB library, the ESP32-S3 handles all enumeration, descriptor generation, and report formatting internally, allowing the controller to be recognized as a standard gamepad on Windows without additional drivers.

Component Selection and Design Considerations

Component selection emphasized functionality, modularity, and cost efficiency. The ESP32-S3 was selected for its integrated USB OTG interface, Bluetooth LE support, and sufficient processing resources for handling multiple modular inputs. Standard pin headers were chosen as the initial connection method between modules and receiver boards due to their availability, affordability, and mechanical stability. Future versions may transition to magnetic pogo-pin connectors to simplify module swapping and improve durability.

All printed circuit boards (PCBs) were designed in-house and fabricated through a low-cost prototyping service. Careful attention was given to connector orientation, trace routing, and power distribution to ensure reliability and ease of assembly.

Mechanical and Ergonomic Design

The physical design was driven by a goal of consistent module sizing and ergonomic balance. The joystick module established the baseline diameter, which the button module matched for symmetry and ease of manufacturing. The 3D-printed enclosure was designed to house the main carrier board and four input modules, providing sufficient internal space for wiring while maintaining a compact, comfortable form factor. Extended side grips were added to improve handling during gameplay without compromising the modular placement of receivers.

Summary

This methodology established a repeatable framework for modular hardware development: from microcontroller selection and USB communication setup to enclosure design and fabrication. The resulting prototype demonstrates reliable USB HID communication, functional modular inputs, and a flexible architecture ready for continued expansion and refinement.

## Bill of Materials:

Currently, there are a few different controllers that can be made. The main difference is the amount and difficulty of soldering you have to do. The first is a custom ESP32 carrier board for the ESP32-S3-WROOM-1U module with a custom mounting method. The second is the one using the ESP32-S3-DevKitC-1, which was used for the shell design. This reduces the complex soldering down to only headers, buttons, capacitors, and resistors.

Table 1: Bill of materials
Part name | Desc | Qty. | Total | Link
MCU Carrier Board
ESP32-S3-WROOM-1U-N4 | ESP32-S3 module | 1 | $5.06 | Digikey.com (https://www.digikey.com/en/products/detail/espressif-systems/ESP32-S3-WROOM-1U-N4/16162640)
1N5819WS | Reverse-current protection diode | 1 | $0.10 | Digikey.com (https://www.digikey.com/en/products/detail/shenzhen-slkormicro-semicon-co-ltd/1N5819WS/26112850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)
AZ1117CH-3.3TRG1 | LDO regulator | 1 | $0.16 | Digikey.com (https://www.digikey.com/en/products/detail/diodes-incorporated/AZ1117CH-3-3TRG1/4470985)
PRTR5V0U2X,215 | ESD protection | 1 | $0.47 | Digikey.com (https://www.digikey.com/en/products/detail/nexperia-usa-inc/prtr5v0u2x-215/1163690)
USB-CB16HTBTR | USB connector | 1 | $1.05 | Digikey.com (https://www.digikey.com/en/products/detail/on-shore-technology-inc/USB-CB16HTBTR/18649611)
603_1208 metric | 10 uF capacitor | 3 | $0.30 | Digikey.com (https://www.digikey.com/en/products/detail/samsung-electro-mechanics/CL21A106KOQNNNE/3886754)
603_1208 metric | .1 uF capacitor | 4 | $0.32 | Digikey.com (https://www.digikey.com/en/products/detail/yageo/CC0603KRX7R7BB104/302822)
SML-D12U1WT86 | Red LED | 1 | $0.12 | Digikey.com (https://www.digikey.com/en/products/detail/rohm-semiconductor/SML-D12U1WT86/5843853)
SKQGABE010 | Button | 1 | $0.31 | Digikey.com (https://www.digikey.com/en/products/detail/alps-alpine/SKQGABE010/19529161)
603_1208 metric | 5.1 kΩ resistors | 2 | $0.32 | Digikey.com (https://www.digikey.com/en/products/detail/panasonic-electronic-components/ERJ-PB3B5101V/6212835)
603_1208 metric | 1 kΩ resistors | 1 | $0.10 | Digikey.com (https://www.digikey.com/en/products/detail/yageo/RC0603JR-7W1KL/12698826)
603_1208 metric | 10 kΩ resistors | 1 | $0.10 | Digikey.com (https://www.digikey.com/en/products/detail/yageo/RC0603FR-0710KL/726880)
DF40C-20DP-0.4V(51) | Plug | 2 | $1.38 | Digikey.com (https://www.digikey.com/en/products/detail/hirose-electric-co-ltd/DF40C-20DP-0-4V-51/1969479)
| Subtotal: | 20 | $9.79
MCU interposer
DF40C-20DS-0.4V(51) | Receptical | 2 | $1.16 | Digikey.com (https://www.digikey.com/en/products/detail/hirose-electric-co-ltd/DF40C-20DS-0-4V-51/1969480)
603_1208 metric | 10 uF capacitors | 2 | $0.20 | Digikey.com (https://www.digikey.com/en/products/detail/samsung-electro-mechanics/CL21A106KOQNNNE/3886754)
603_1208 metric | .1 uF capacitors | 2 | $0.16 | Digikey.com (https://www.digikey.com/en/products/detail/yageo/CC0603KRX7R7BB104/302822)
SKQGABE010 | Button | 3 | $0.93 | Digikey.com (https://www.digikey.com/en/products/detail/alps-alpine/SKQGABE010/19529161)
LTST-C193TBKT-5A | Blue LED | 4 | $0.72 | Digikey.com (https://www.digikey.com/en/products/detail/liteon/LTST-C193TBKT-5A/2053656)
603_1208 metric | 1 kΩ resistors | 4 | $0.40 | Digikey.com (https://www.digikey.com/en/products/detail/yageo/RC0603JR-7W1KL/12698826)
| Subtotal: | 17 | $3.57
Dev board interposer
ESP32-S3-DevKitC-1-N8R 8 Development Board | ESP32-S3 dev board | 1 | $15.00 | Amazon.com (https://www.amazon.com/Espressif-ESP32-S3-DevKitC-1-N8R8-Development-Board/dp/B09MHP42LY)

Part name | Desc | Qty. | Total | Link
603_1208 metric | 10 uF capacitors | 2 | $0.20 | Digikey.com (https://www.digikey.com/en/products/detail/samsung-electro-mechanics/CL21A106KOQNNNE/3886754)
603_1208 metric | .1 uF capacitors | 2 | $0.16 | Digikey.com (https://www.digikey.com/en/products/detail/yageo/CC0603KRX7R7BB104/302822)
SKQGABE010 | Button | 3 | $0.93 | Digikey.com (https://www.digikey.com/en/products/detail/alps-alpine/SKQGABE010/19529161)
LTST-C193TBKT-5A | Blue LED | 4 | $0.72 | Digikey.com (https://www.digikey.com/en/products/detail/liteon/LTST-C193TBKT-5A/2053656)
603_1208 metric | 1 kΩ resistors | 4 | $0.40 | Digikey.com (https://www.digikey.com/en/products/detail/yageo/RC0603JR-7W1KL/12698826)
PPTC221LFBN-RC | 01x22 female pin headers | 2 | $2.40 | Digikey.com (https://www.digikey.com/en/products/detail/sullins-connector-solutions/PPTC221LFBN-RC/810160)
| Subtotal: | 18 | $19.81
Input Boards
CC0603KRX5R8BB105 | 1 uF capacitors | 4 | $0.40 | Digikey.com (https://www.digikey.com/en/products/detail/yageo/CC0603KRX5R8BB105/2833610)
9032 | Joysticks | 2 | $10.50 | Digikey.com (https://www.digikey.com/en/products/detail/sparkfun-electronics/09032/6823623)
B3F-1000 | Button | 12 | $2.88 | Digikey.com (https://www.digikey.com/en/products/detail/omron-electronics-inc-emc-div/B3F-1000/33150)
PRPC040SACN-RC | header pins 1x40 pin set | 2 | $1.68 | Digikey.com (https://www.digikey.com/en/products/detail/sullins-connector-solutions/PRPC040SACN-RC/2776066)
| Subtotal: | 20 | $15.46
Receiver Boards
PPPC041LFBN-RC | 1x4 pin header sockets | 16 | $6.08 | Digikey.com (https://www.digikey.com/en/products/detail/sullins-connector-solutions/PPPC041LFBN-RC/810176)
PRPC040SBAN-M71RC | header pin right angle 1x40 pins | 0 | $0.00 | Digikey.com (https://www.digikey.com/en/products/detail/sullins-connector-solutions/PRPC040SBAN-M71RC/2775294)
26 AWG Wire,26 AWG Silicone Electrical Wire -SCHDRA 26 Gauge Tinned Copper Wires | 26 AWG stranded wire | 1 | $9.99 | Amazon.com (https://www.amazon.com/Electrical-SCHDRA-UL1007-26Gauge-Tinned/dp/B0C9MB4DTY)
| Subtotal: | 17 | $16.07
PCBs
Custom MC Board | JLC makes 5 # in qty. is # used | 1 | $5.00 | Link to Gerber files (https://github.com/Koalaven/Open-Source-Modular-Controller/blob/Semester_1/Hardware/gerber%20files/Custom%20MC%20Board.zip)
MC carrier board | JLC makes 5 # in qty. is # used | 1 | $5.00 | Link to Gerber files (https://github.com/Koalaven/Open-Source-Modular-Controller/blob/Semester_1/Hardware/gerber%20files/Dev%20Board%20Interposer.zip)
MC dev board carrier | JLC makes 5 # in qty. is # used | 1 | $5.00 | Link to Gerber files (https://github.com/Koalaven/Open-Source-Modular-Controller/blob/Semester_1/Hardware/gerber%20files/MCU_interposer_V1.1.zip)
Button Board | JLC makes 5 # in qty. is # used | 2 | $5.00 | Link to Gerber files (https://github.com/Koalaven/Open-Source-Modular-Controller/blob/Semester_1/Hardware/gerber%20files/OSMC_Module_Buttons.zip)
Joystick Board | JLC makes 5 # in qty. is # used | 2 | $5.00 | Link to Gerber files (https://github.com/Koalaven/Open-Source-Modular-Controller/blob/Semester_1/Hardware/gerber%20files/OSMC_Module_Joystick.zip)
Receiver Board | JLC makes 5 # in qty. is # used | 4 | $5.00 | Link to Gerber files (https://github.com/Koalaven/Open-Source-Modular-Controller/blob/Semester_1/Hardware/gerber%20files/OSMC_Module_Receiver.zip)
| Sutotal: | 11 | $30.00

Part name | Desc | Qty. | Total | Link
Shell
3D Printer Filament | PLA | 1 | $2.50 | link to step file (https://github.com/Koalaven/Open-Source-Modular-Controller/blob/V1/Hardware/Shell/OSMC%20Assembly.step)
Heat-set inserts | 150 PCS M3 Brass Inserts | 12 | $5.69 | amazon.com (https://www.amazon.com/Threaded-Inserts-Soldering-Printing-Components/dp/B0FJ1T989N?s=hi)
M3 skews | Taiss 620 PCS M3 Screw Kit | 12 | $6.99 | amazon.com (https://www.amazon.com/Taiss-620PCS-Assortment-Washers-Printing/dp/B0CWXRG6VL?s=hi)
| Subtotal: | 25 | $15.18
Total | 103 | $109.88

## Tools Used:

Software
Table 2: Software used
Name | Description | Price | Link
GitHub Desktop | Used to share updates and versions. | Free | GitHub.com (https://desktop.github.com/download/)
Arduino IDE | Used as the programming platform. | Free | Arduino.cc (https://docs.arduino.cc/software/ide/)
KiCAD | The program was used for creating the PCB. | Free | KiCAD.com (https://www.kicad.org/)
OnShape | Used for the frame design. | Free | OnShape.com (https://www.onshape.com/en/)
Ultimaker Cura | Used as a slicer for the 3-D printed glasses frame. | Free | Ultimaker.com (https://ultimaker.com/software/ultimaker-cura/)

Total Price

Hardware
Table 3: Hardware used
Name | Description | Price | Link
3D-printer | Ender-3 printer with PLA 1.75mm used for the frames of the glasses. | These parts come in a variety of prices, qualities, and quantities, or they may be found at a local makerspace | 3D-Printer (https://store.creality.com/products/ender-3-v3-se-3d-printer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)

Name | Description | Price | Link
Solder Iron | Used for touch-ups and adding components. | These parts come in a variety of prices, qualities, and quantities, or they may be found at a local makerspace | Solder Gun (https://www.google.com/search?q=solder+gun&oq=solder+gu&sourceid=chrome)
Heat gun | The heat gun was used to help get the ESP32 on the boards and align some of the components. | These parts come in a variety of prices, qualities, and quantities, or they may be found at a local makerspace | Heat Gun (https://www.homedepot.com/p/Genesis-12-5-Amp-Dual-Temperature-Heat-Gun-with-High-Low-Settings-and-Air-Reduction-Reflector-and-2-Deflector-Nozzles-GHG1500A/203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)
Multimeter | The Multimeter was from the lab and was used to test the PCB. | These parts come in a variety of prices, qualities, and quantities, or they may be found at a local makerspace | Multimeter (https://www.amazon.com/Fluke-Applications-Measurements-Capacitance-Capabilities/dp/B01IH41CUW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)
Sandpaper | The sandpaper was used to clean up the edges of the PCB. A finer grit would be Ideal for this situation. | These parts come in a variety of prices, qualities, and quantities, or they may be found at a local makerspace | Sandpaper (https://www.amazon.com/3M-9005NA-Aluminum-Sandpaper-Assorted/dp/B00004Z48U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)
Twezzers | The tweezers were used to hold components in place when soldering.
Total Price | | Varies

## Assembly:

1. Gather Materials
a. Refer to the BOM
b. Download the main GitHub repo branch (link) (https://github.com/OSHE-Github/Open-Source-Modular-Controller)
2. Order PCBs
a. Use our PCB manufacturer; the Gerber files are provided in the GitHub repository.
b. You can get the board preassembled in this iteration. There are two different board sets available for order.
This version uses the version that uses the DevKitC module, not the custom ESP32 board.
3. 3D Print the shell and module pieces.
4. Prep the PCB
a. Sand edges
b. Clean with isopropyl alcohol
5. Solder components (if necessary)
In this production, blank boards were ordered, and most components were hand-soldered with only a soldering iron.
a. Custom ESP board

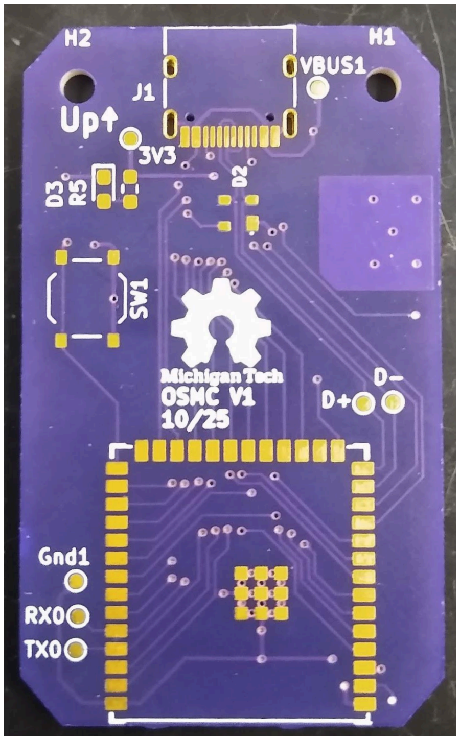
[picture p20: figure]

Figure 2: Custom ESP32-S3 Board

i. Solder the headers to the bottom of the board
Take your time; use flux and solder wick.
ii. | Solder on the rest of the components on the bottom of the board, working
| up from the smallest/lowest profile component up. This will give you room
| to work on the various components.
iii. | Solder on the USB port with the same method as the headers

iv. Solder the ESP32-S3 module
1. Pre-tin the module pads and PCB pads by placing a little solder on
| the pads.
2. Heat using hot air above and below until the module self-aligns
| and settles. May need to hold the module down with tweezers
| while it aligns.
b. Receiver modules
i. Solder the female header pins into areas J1-4 with the opening and
| boards facing up.
ii. | Solder the 26 AWG stranded wire into area J5 following the color pattern
| Black-Red-Blue-Green-White-Yellow, bottom to top. Repeat for all
| receiver boards.

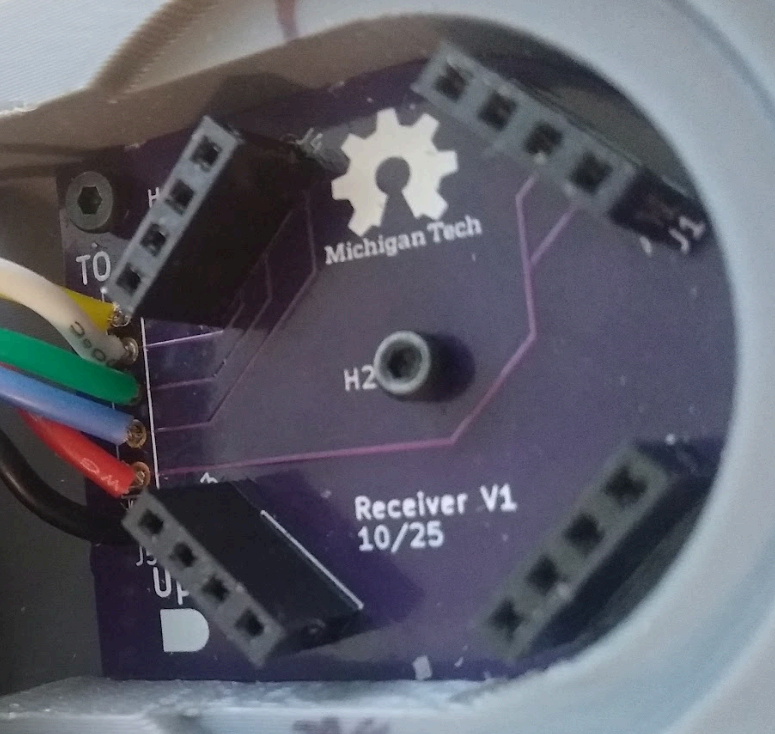
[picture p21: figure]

Figure 3: Receiver Module
iii. Repeat for all receiver boards.
c. Dev board carrier
i. Insert headers onto the ESP32 DevKit, place the carrier board on top, and
| solder.
ii. | Solder on the buttons.
iii. | Solder on the wires. If the wires were attached to the reserves above, the
| order is top (where the buttons are) -> bottom
| red->blue->yellow->white->green->black

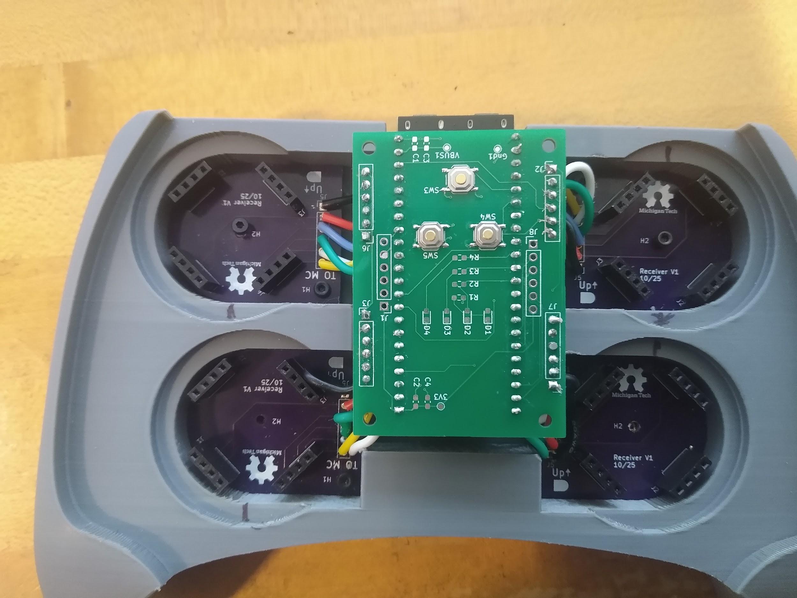
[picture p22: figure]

Figure 4: Dev Board Receiver Module

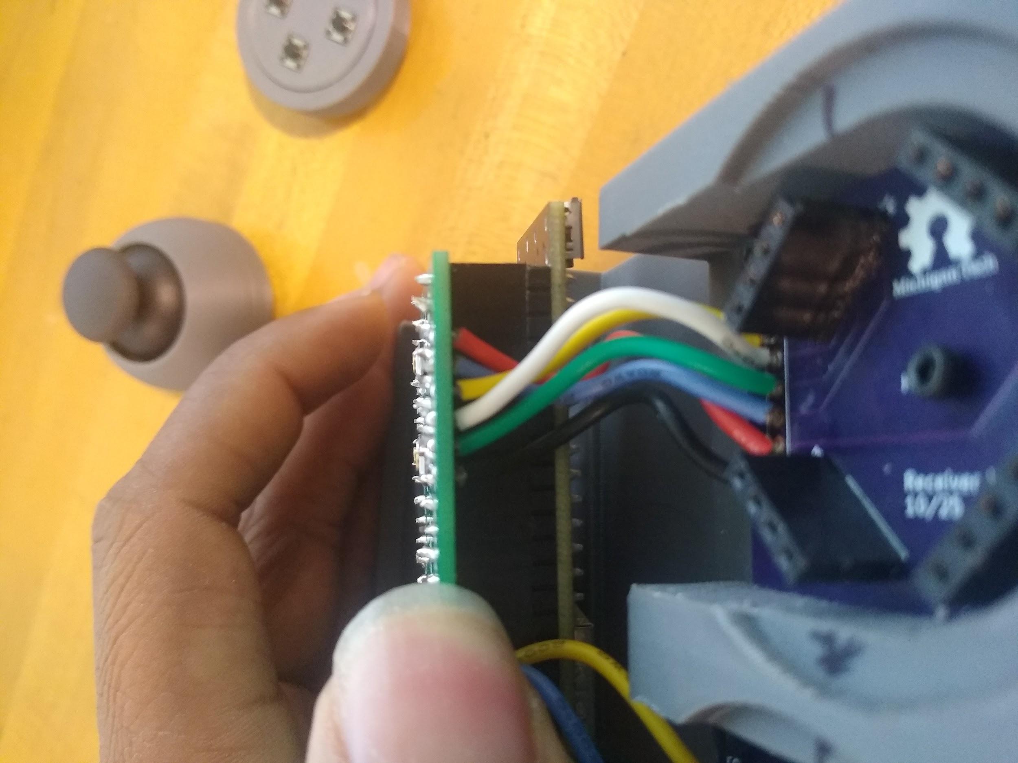
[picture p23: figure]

Figure 5: Connection Between Receiver Modules

d. Custom ESP interposer
i. Solder the header socket to the board.
ii. Solder the rest of the components on the board. The LED and accompaniment resistors are optional in this version and have no function in the code.

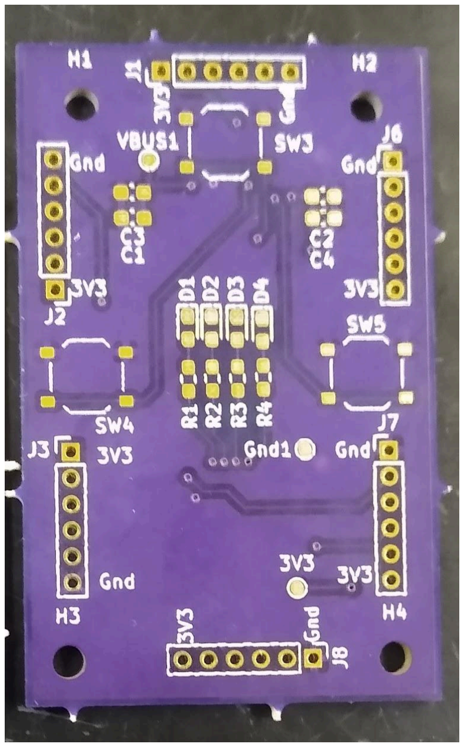
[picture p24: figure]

Figure 6: Receiver Module for Custom ESP32 Board

e. Joystick modules
i. Solder the joystick into the designated positions on the PCB, keeping each button flat against the board.

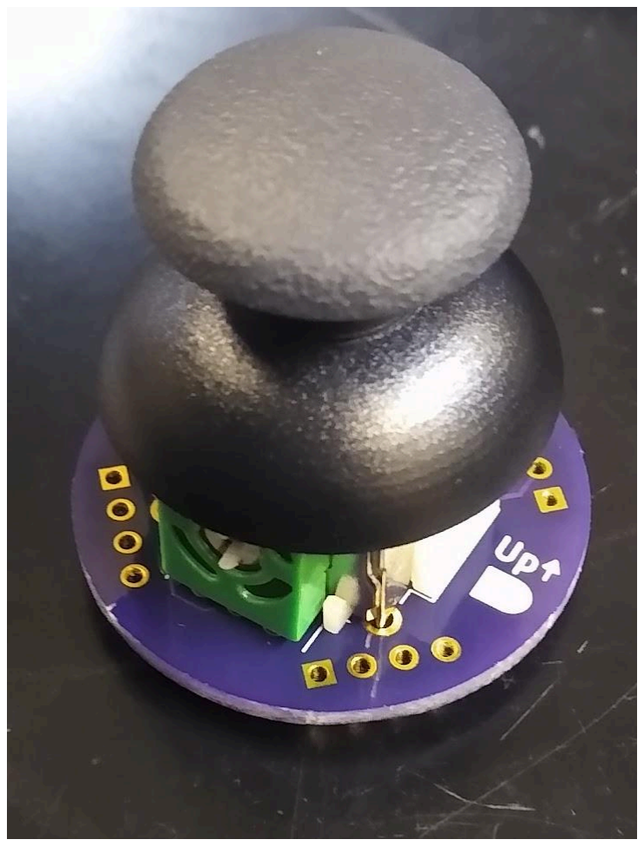
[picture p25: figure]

Figure 7: Joystick Module (No Shell)

ii. | Insert and solder the male pin headers so that the long ends extend from
| the side opposite the buttons, ensuring the headers stay straight and
| perpendicular to the PCB.
iii. | Inspect all joints to confirm solid solder connections and verify that the
| buttons click freely without obstruction.
iv. | Place the module in the joystick module shell, and mark the shell with
| where the up arrow is pointing.
v. Glue the top cover onto the bottom shell.


Figure 8: Joystick Module (Shell)

f. Button modules
i. Solder the four push buttons into their designated labeled positions on the PCB, keeping each button flat against the board.


Figure 9: Button Module (No Shell)

ii. | Insert and solder the male pin headers so that the long ends extend from
| the side opposite the buttons, ensuring the headers stay straight and
| perpendicular to the PCB.
iii. | Inspect all joints to confirm solid solder connections and verify that the
| buttons click freely without obstruction.
iv. | Place the module in the button module shell, mark the shell with where
| the up arrow is pointing.

v. Glue the top plate onto the module.


Figure 10: Button Module (Shell)

6. Uploading code
a. Install Arduino IDE.
b. Add ESP32 boards manager URL: In Arduino IDE, select File -> Preferences. Paste this URL in the additional boards manager URL box: “https://espressif.github.io/arduino-esp32/package_esp32_index.json”.
c. Install the ESP32 board package.
Next, select “Tools” -> “Board: (whatever)” -> “Boards Manager”. Search for ESP32 and install the board package from Espressif Systems.
d. Install the ESP32TinyUSB library by Dariusz. Next, select “Tools” -> “Manage Libraries…”. Search ESP32TinyUSB and install the library by Dariusz.
e. Import project files into Arduino IDE.
f. Connect via USB (UART port).


Figure 11: ESP32-S3 Dev Board

g. Select the ESP32-S3 Dev Module and the correct COM port. The COM port could be different depending on your computer.


Figure 12: Arduino IDE COM Selection

h. Select “Tools”, then change to the match following settings.


Figure 13: Board Configuration

i. Compile and upload the sketch onto the ESP32.
i. Use the UART for programming.
ii. Use the USB port for controller operation
7. Assemble in-shell
a. Place receiver boards and mark screw holes on the bottom shell.
b. Remove the receiver boards and embed the M3 heat set inserts where you marked the bottom shell, making sure they are level with the top surface.
c. Replace the receiver boards and secure them with M3 screws.
d. Place the joystick/button modules onto the receiver boards.
e. Place the carrier board in the center of the bottom shell.

f. Push the top cover into place, making sure all inputs align with their respective holes.
8. Testing
a. Use a program such as Steam Input or gamepad-tester.
b. Verify that every button and joystick direction registers properly.

## Characterization Data:

Input Testing
Testing the inputs was straightforward. First was testing all the buttons. This was tested within the gamepad tester website, where the buttons were B0-B10 and the d-pad was axis9. The joysticks were tested in the same manner and were axes 0, 1, 3, and 5. From this test, the buttons were found to be shorted together and explained more in the hardware continuity section. This test also has a continuity error between the assembled controller and the code that defines which pins are to which buttons.


Figure 14: Gamepad Tester Example

Ergonomic Design
To see how the controller’s ergonomics felt to others, we asked members of the Open Source Hardware Enterprise at Michigan Tech to hold the controller and write down their thoughts. The responses were mostly positive, with the main comment being that the size was a little large and wide for some of the button configurations. Some of the other comments were about the finish, but this will vary depending on the 3D printer and the settings used.

Table 4: Ergonomics Feedback

Name of Reviewer | Rating from (1 low-10 high) | Comments
Evan | 7 | A little wide.
Ian | 10 | Good for big hands.
Riley | 4 | Too big, for small hands but hands. Holds are really nice :)
Owen | 7 | Really nice, maybe too big for my hands.
Garrett | 7 | Slightly big, otherwise very nice and comfortable
Alycia | 8 | Really big for my hands. But it feels nice to hold.
Joshua | 8 | Comfortable if not a bit big.
Emily | 10 | Comfortable
Katelyn | 10 | Comfortable, nice feel and cool design. (Maybe big but not a problem)
James | 8 | Comfortable. Move the lower stick buttons in.
Anonymous | 6 | My hands small, I like a smaller controller because I play claw

Hardware Continuity

During hardware testing, a previously undetected short was discovered on the custom ESP interposer board. The fault occurred between the 3.3 V rail and ground, creating a low-resistance path that prevented the ESP32 from booting. The short was subtle enough that most laptops’ internal current protection systems did not trigger, making the issue less obvious during early debugging.


Figure 15: Custom Board Short

The problem was identified, corrected in the updated board revision, and manually repaired on the already manufactured boards. However, due to additional issues and time constraints with the custom interposer design, these original boards were ultimately scrapped for this assembly cycle. The corrected design ensures proper power isolation and restores full functionality for future revisions.

A second issue identified during continuity testing involved accidental bridging caused by stray strands in the wiring. Some of the stranded wires used during assembly had individual filaments that separated and made unintended contact with adjacent pads or traces. This was partially a workmanship issue, but was also influenced by the selected wire gauge.

To reduce the likelihood of frayed strands causing shorts, the Bill of Materials (BOM) was updated to replace the original 24 AWG wire with 26 AWG stranded wire. The smaller gauge provides better flexibility and is easier to manage during soldering, significantly lowering the risk of strand bridging in future builds.

Lastly, there is a small possibility of the joystick module shorting the 3v3 and ground rail. This was mitigated by having circular indents in the shell that prevented the module from being plugged in with this offset. But testing without the shell, this possibility was discovered.

# Sponsors/Acknowledgements:

This project was currently self-sponsored by the Open Source Hardware Enterprise at Michigan Technological University.

# References:

“TinyUSB Library,” GitHub, https://github.com/chegewara/EspTinyUSB (accessed Dec. 5, 2025). “Alpakka Controller,” Input Labs, https://inputlabs.io/alpakka (accessed Dec. 5, 2025).
“Gamepad Tester,” Hardware Tester, https://hardwaretester.com/gamepad (accessed Dec. 5, 2025).

“Proteus ControllerTM kit,” ByoWave Proteus Controller, https://byowave.com/products/proteus-controller (accessed Dec. 5, 2025).
“ESWAP x 2 pro controller,” ESWAP X2 PRO CONTROLLER | Thrustmaster USA,
https://eshop.thrustmaster.com/en_us/eswap-x2-pro-controller.html (accessed Dec. 5, 2025).

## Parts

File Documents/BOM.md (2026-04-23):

# Bill of Materials (BOM)

This Bill of Materials summarizes all components required to assemble the Open Source Modular Controller V2.

--

## Receiver Board

| Part Name | Desc | Qty. | Total | Link |
|---|---|---|---|---|
| LTC4317 | Address Translator | 4 | $20.72 | [Digikey.com](https://www.digikey.com/en/products/detail/analog-devices-inc/LTC4317CDHC-PBF/5297623) |
| 24LC02BT-I/OT | 2 kbit EEPROM | 1 | $0.31 | [Digikey.com](https://www.digikey.com/en/products/detail/microchip-technology/24LC02BT-I-OT/443519) |
| PCF8574DWR | 8 bit io expander | 1 | $1.99 | [Digikey.com](https://www.digikey.com/en/products/detail/texas-instruments/PCF8574DWR/484579) |
| 603_1208 metric | 10 µF capacitor | 3 | $0.03 | [Digikey.com](https://www.digikey.com/en/products/detail/samsung-electro-mechanics/CL21A106KOQNNNE/3886754) |
| 603_1208 metric | 0.1 µF capacitor | 4 | $0.24 | [Digikey.com](https://www.digikey.com/en/products/detail/yageo/CC0603KRX7R7BB104/302822) |
| 603_1208 metric | 10 kΩ resistors | 27 | $0.24 | [Digikey.com](https://www.digikey.com/en/products/detail/yageo/RC0603FR-0710KL/726880) |
| XIAO ESP32-S3 Plus | Seeed Studio XIAO ESP32-S3 Plus | 1 | $7.90 | [Seeedstudio.com](https://www.seeedstudio.com/Seeed-Studio-XIAO-ESP32S3-Plus-p-6361.html) |
| PCB | Main Receiver Board | 1 | $29.00 | — |
| 603_1208 metric | 0 kΩ resistors | 1 | $0.10 | [Digikey.com](https://www.digikey.com/en/products/detail/yageo/RC0603JR-070RL/726675) |
| 603_1208 metric | 102 kΩ resistors | 1 | $0.10 | [Digikey.com](https://www.digikey.com/en/products/detail/yageo/RC0603FR-07102KL/726891) |
| 603_1208 metric | 182 kΩ resistors | 1 | $0.10 | [Digikey.com](https://www.digikey.com/en/products/detail/stackpole-electronics-inc/RMCF0603FT182K/1760990) |
| 603_1208 metric | 280 kΩ resistors | 1 | $0.10 | [Digikey.com](https://www.digikey.com/en/products/detail/yageo/RC0603FR-07280KL/727112) |
| 603_1208 metric | 392 kΩ resistors | 1 | $0.10 | [Digikey.com](https://www.digikey.com/en/products/detail/yageo/RC0603FR-07392KL/727201) |
| 603_1208 metric | 523 kΩ resistors | 1 | $0.10 | [Digikey.com](https://www.digikey.com/en/products/detail/yageo/RC0603FR-07523KL/727292) |
| 603_1208 metric | 681 kΩ resistors | 1 | $0.10 | [Digikey.com](https://www.digikey.com/en/products/detail/yageo/RT0603FRE07681KL/5929212) |
| 603_1208 metric | 887 kΩ resistors | 1 | $0.10 | [Digikey.com](https://www.digikey.com/en/products/detail/yageo/RC0603FR-07887KL/727417) |
| 603_1208 metric | 976 kΩ resistors | 1 | $0.10 | [Digikey.com](https://www.digikey.com/en/products/detail/yageo/RC0603FR-07976KL/727442) |
| 603_1208 metric | 1 MΩ resistors | 5 | $0.40 | [Digikey.com](https://www.digikey.com/en/products/detail/yageo/RC0603FR-071ML/726844) |
| 1x8 smd pogo pins | Pogo pin connection | 8 | $42.48 | [Digikey.com](https://www.digikey.com/en/products/detail/digikey-va/811-22-008-30-000101/682276) |
| JST SH 4-pin Connector | Qwiic compatible connector | 1 | $3.95 | [Adafruit.com](https://www.adafruit.com/product/4208) |

**Subtotal:** 65 parts — **$108.16**

---
### Module Boards
 Following is the Module boards. These boards are parted out into each with the components cost for 1 of that type. most of the cost cna go down by ordering in larger qualities and the pcb do not need to be ordered multiple times as they come in packs of 5.

---

## Button Board

| Part Name | Desc | Qty. | Total | Link |
|---|---|---|---|---|
| 24LC02BT-I/OT | 2 kbit EEPROM | 1 | $0.31 | [Digikey.com](https://www.digikey.com/en/products/detail/microchip-technology/24LC02BT-I-OT/443519) |
| PCF8574DWR | 8 bit io expander | 1 | $1.99 | [Digikey.com](https://www.digikey.com/en/products/detail/texas-instruments/PCF8574DWR/484579) |
| SKQGABE010 | Button | 4 | $1.24 | [Digikey.com](https://www.digikey.com/en/products/detail/alps-alpine/SKQGABE010/19529161) |
| PCB | Button Board | 1 | $7.00 | — |

**Subtotal:** 7 parts — **$10.54**

---

## Joystick Board

| Part Name | Desc | Qty. | Total | Link |
|---|---|---|---|---|
| 24LC02BT-I/OT | 2 kbit EEPROM | 1 | $0.31 | [Digikey.com](https://www.digikey.com/en/products/detail/microchip-technology/24LC02BT-I-OT/443519) |
| ADS1115IDGST | ADC | 1 | $6.29 | [Digikey.com](https://www.digikey.com/en/products/detail/texas-instruments/ADS1115IDGST/2123298) |
| 603_1208 metric | 10 kΩ resistors | 1 | $0.10 | [Digikey.com](https://www.digikey.com/en/products/detail/yageo/RC0603FR-0710KL/726880) |
| 9032 | Joysticks | 1 | $5.25 | [Digikey.com](https://www.digikey.com/en/products/detail/sparkfun-electronics/09032/6823623) |
| PCB | Joysticks Board | 1 | $7.00 | — |

**Subtotal:** 5 parts — **$18.95**

---

## Bumper Board

| Part Name | Desc | Qty. | Total | Link |
|---|---|---|---|---|
| 24LC02BT-I/OT | 2 kbit EEPROM | 1 | $0.31 | [Digikey.com](https://www.digikey.com/en/products/detail/microchip-technology/24LC02BT-I-OT/443519) |
| PCF8574DWR | 8 bit io expander | 1 | $1.99 | [Digikey.com](https://www.digikey.com/en/products/detail/texas-instruments/PCF8574DWR/484579) |
| PCB | Bumper Board | 1 | $7.00 | — |
| Key switches | Switches for bumpers and triggers | 1 | $4.49 | [Amazon.com](https://www.amazon.com/BlingKingdom-Replacement-Mechanical-Keyboard-Dustproof/dp/B0DSHTPSL3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) |

**Subtotal:** 4 parts — **$13.79**

---

## Nav / Master Board

| Part Name | Desc | Qty. | Total | Link |
|---|---|---|---|---|
| 24LC02BT-I/OT | 2 kbit EEPROM | 1 | $0.31 | [Digikey.com](https://www.digikey.com/en/products/detail/microchip-technology/24LC02BT-I-OT/443519) |
| PCF8574DWR | 8 bit io expander | 1 | $1.99 | [Digikey.com](https://www.digikey.com/en/products/detail/texas-instruments/PCF8574DWR/484579) |
| LTST-C193TBKT-5A | Blue LED | 4 | $0.72 | [Digikey.com](https://www.digikey.com/en/products/detail/liteon/LTST-C193TBKT-5A/2053656) |
| B3F-1000 | Button | 4 | $0.96 | [Digikey.com](https://www.digikey.com/en/products/detail/omron-electronics-inc-emc-div/B3F-1000/33150) |
| PCB | Nav Board | 1 | $7.00 | — |
| 319-10-104-00-006000 | Pogo pin strikers | 3 | $8.94 | [Digikey.com](https://www.digikey.com/en/products/detail/mill-max-manufacturing-corp/319-10-104-00-006000/5176105) |

**Subtotal:** 14 parts — **$19.92**

---

## Overall Total

- **Total Parts:** 95  
- **Total Cost:** **$171.36**

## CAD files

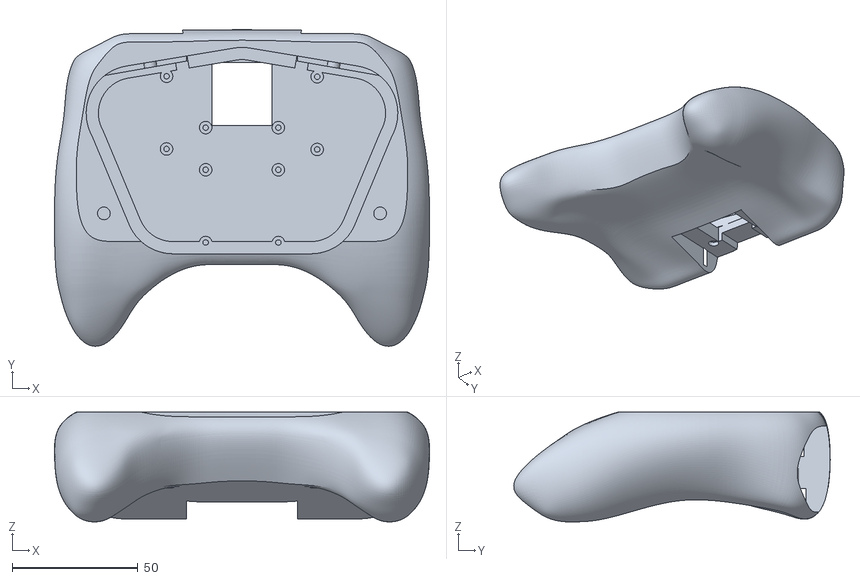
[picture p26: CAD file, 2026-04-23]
Hardware/Shell/OSMC/OSMC_Body_MainBody.stl
149.3 x 126.0 x 43.7

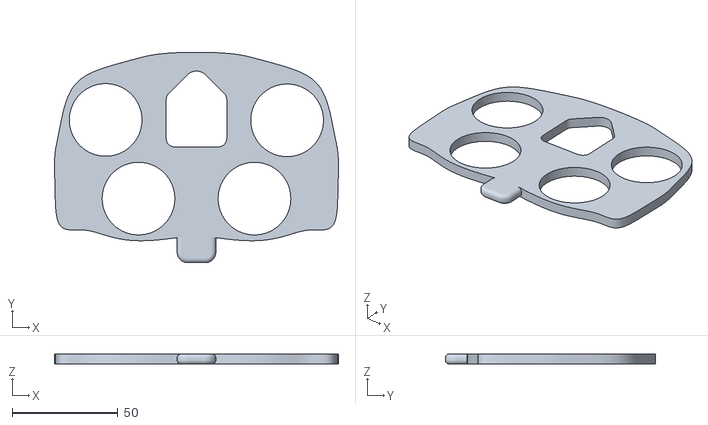
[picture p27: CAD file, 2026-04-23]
Hardware/Alternate Shell STLs/OSMC_Lid.stl
134.5 x 99.7 x 4.90

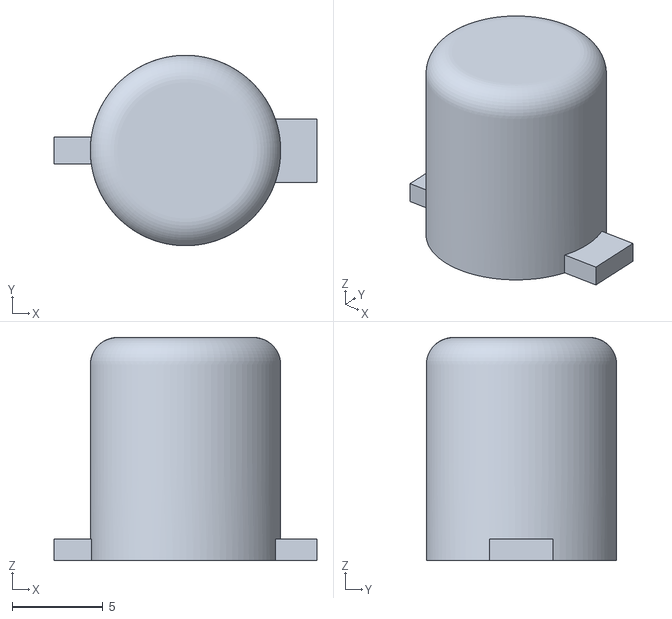
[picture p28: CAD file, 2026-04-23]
Hardware/Module STLs/Button Cap Taller.stl
14.5 x 10.5 x 12.3

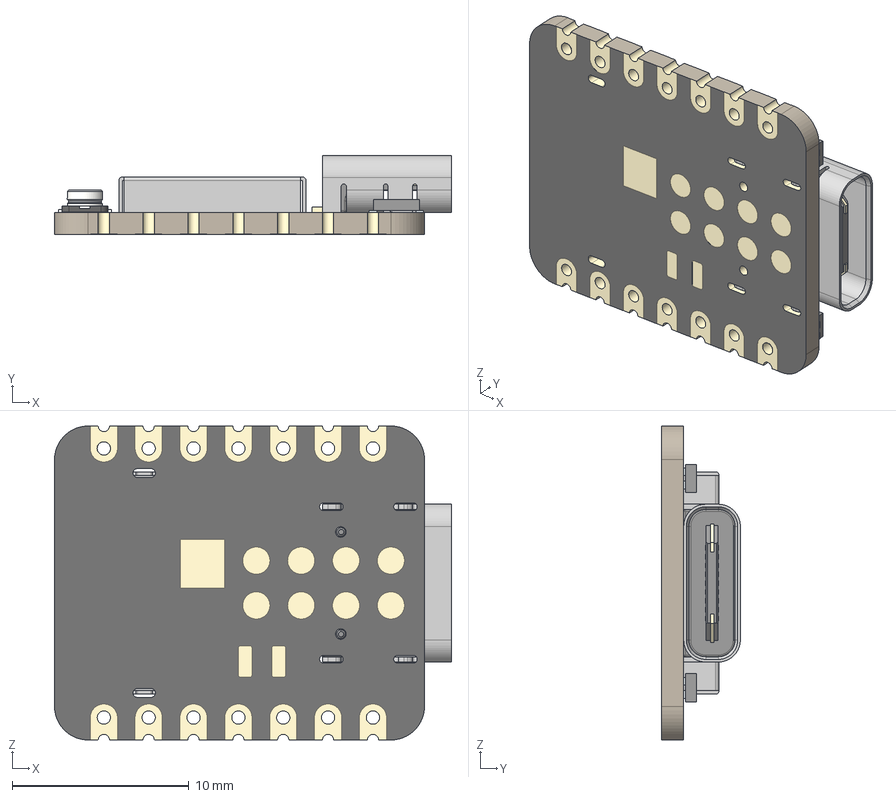
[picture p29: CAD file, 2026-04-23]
Hardware/PCBs/module/OSMC_Module_Lib/Xiao boards/XIAO-ESP32S3 v2.step
22.5 x 4.46 x 17.8 mm
BOSS-EXTRUDE14_8_
BOSS-EXTRUDE7_4_
BOSS-EXTRUDE7_3_
BOSS-EXTRUDE14_4_
BOSS-EXTRUDE14_2_
BOSS-EXTRUDE14_11_
BOSS-EXTRUDE7_7_
BOSS-EXTRUDE14_9_
BOSS-EXTRUDE14_3_
BOSS-EXTRUDE14_7_
MIRROR2
BOSS-EXTRUDE14_5_
BOSS-EXTRUDE14_12_
BOSS-EXTRUDE7_8_
BOSS-EXTRUDE7_1_
BOSS-EXTRUDE14_10_
BOSS-EXTRUDE7_9_
BOSS-EXTRUDE14_6_
BOSS-EXTRUDE14_1_
BOSS-EXTRUDE7_6_
BOSS-EXTRUDE7_2_
CUT-EXTRUDE5
BOSS-EXTRUDE7_5_
Shield
Pins x 2
U.FL-R-SMT-1_10_ v1

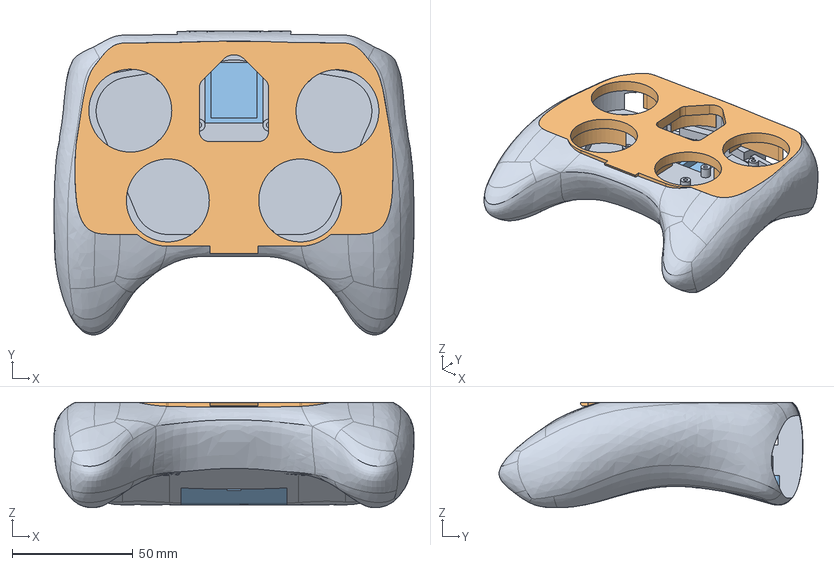
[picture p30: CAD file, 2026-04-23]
Hardware/Shell/OSMC/OSMC_Body.step
149.3 x 126.0 x 43.7 mm

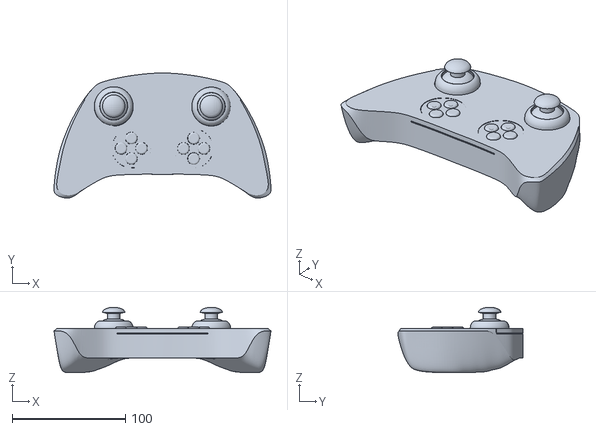
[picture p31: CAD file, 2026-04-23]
Hardware/Shell/OSMC_Shell2.stl
191.3 x 110.3 x 57.7

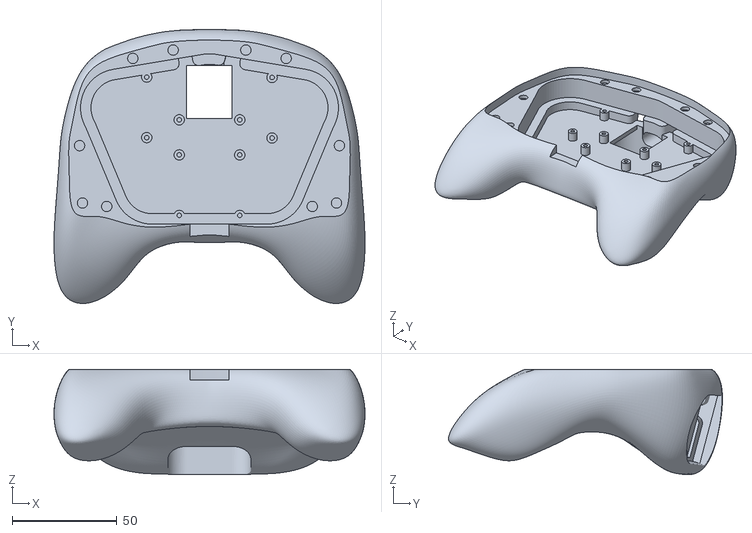
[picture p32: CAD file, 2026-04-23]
Hardware/Alternate Shell STLs/OSMC_Body.stl
148.7 x 131.0 x 50.4

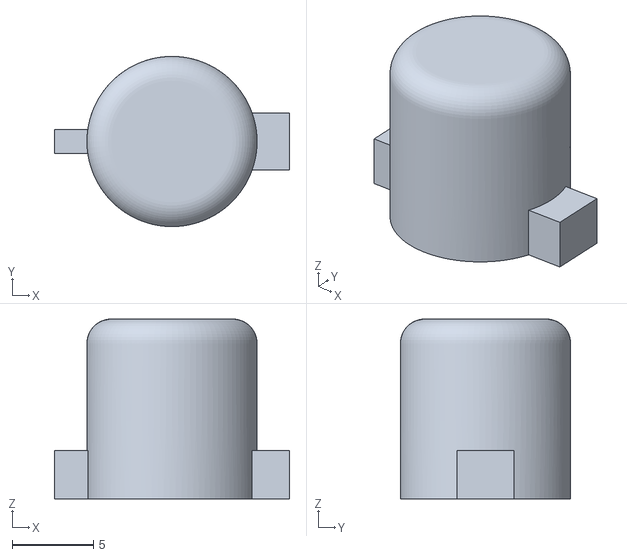
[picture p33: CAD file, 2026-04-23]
Hardware/Module STLs/Button Cap SMD.stl
14.5 x 10.5 x 11.1

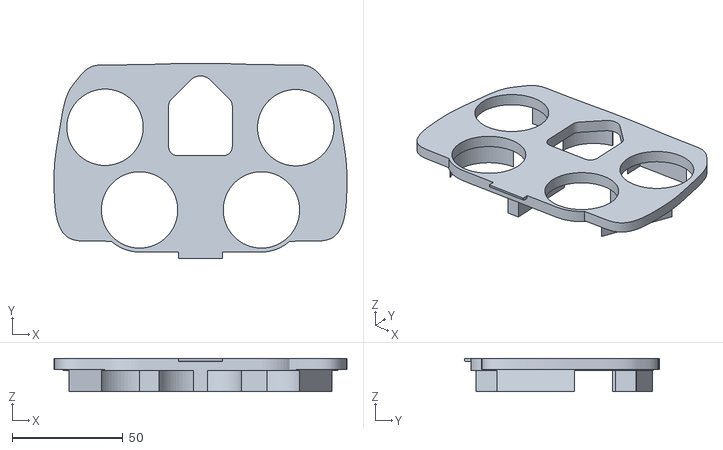
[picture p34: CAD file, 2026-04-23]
Hardware/Shell/OSMC/OSMC_Shell_TopPlate.stl
132.0 x 88.0 x 15.0

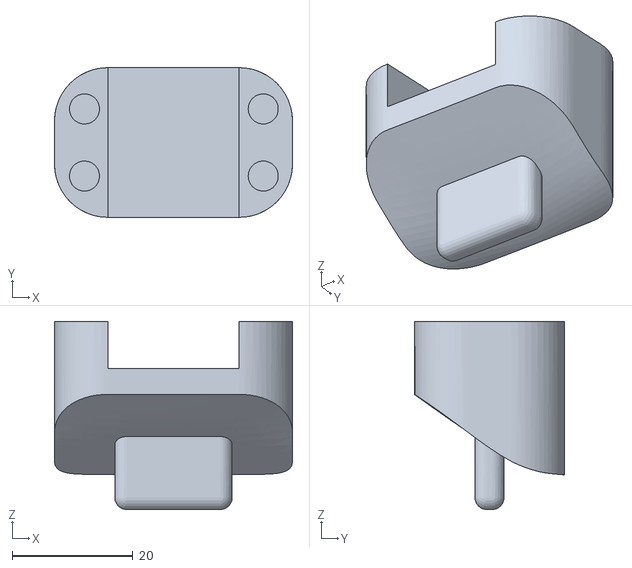
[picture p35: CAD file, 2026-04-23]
Hardware/Alternate Shell STLs/OSMC_MSU_Lid.stl
39.5 x 24.8 x 31.2

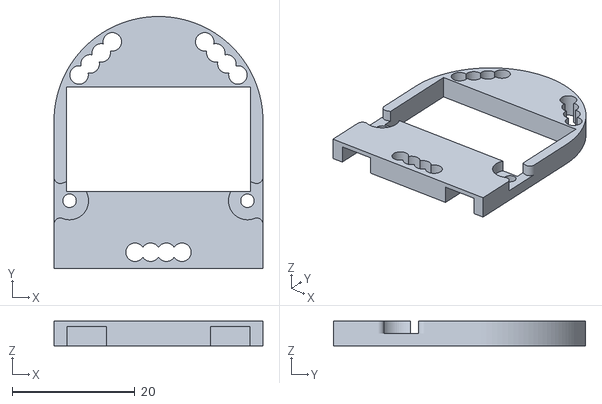
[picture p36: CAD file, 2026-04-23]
Hardware/Module STLs/OSMC_Module_Bumpers_Body.stl
34.0 x 41.0 x 3.99

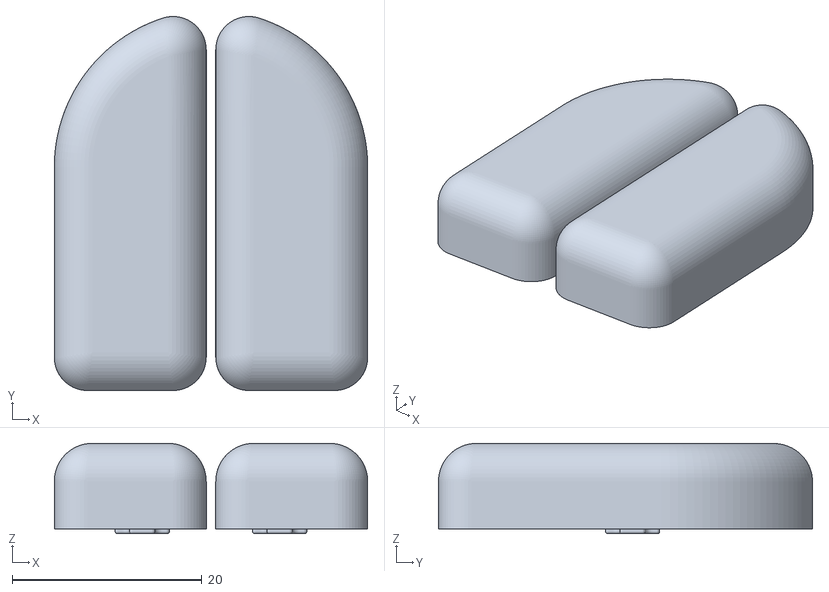
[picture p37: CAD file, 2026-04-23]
Hardware/Module STLs/OSMC_Module_Bumpers_Caps.stl
33.0 x 39.4 x 9.50

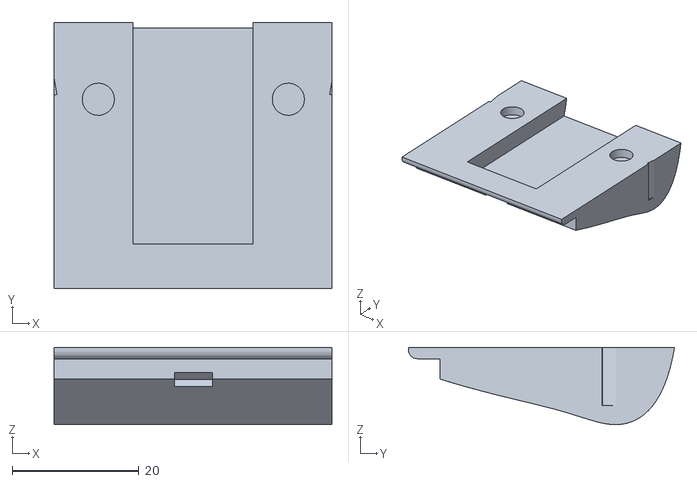
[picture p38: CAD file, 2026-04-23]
Hardware/Shell/OSMC/OSMC_Body_BottomPlate.stl
43.9 x 42.0 x 12.2

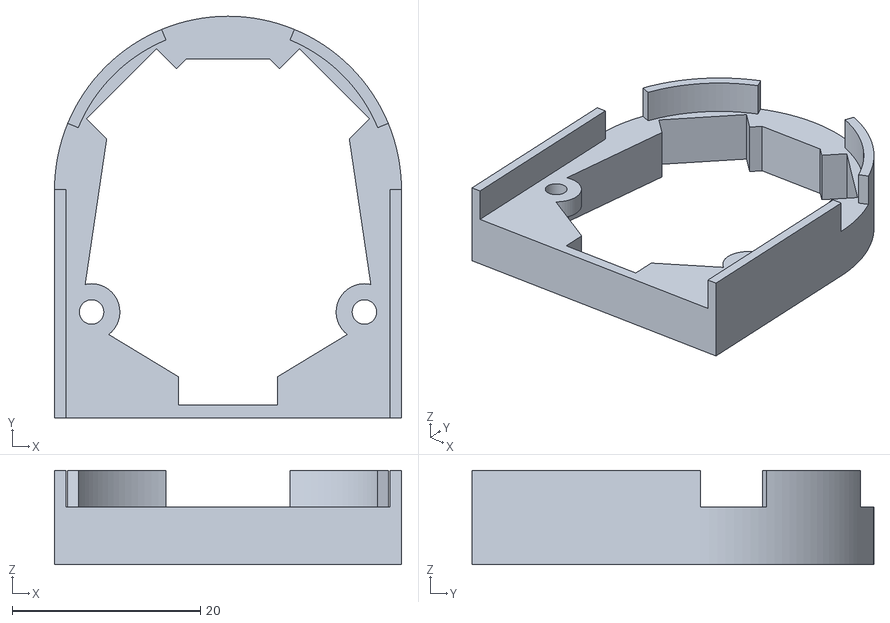
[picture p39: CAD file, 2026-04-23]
Hardware/Module STLs/OSMC_Module_Master_Bottom.stl
36.8 x 42.6 x 10.00

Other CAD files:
Hardware/Module STLs/OSMC_Module_Joystick_Bottom.stl
Hardware/Module STLs/OSMC_Module_Buttons_Top.stl
Hardware/Module STLs/OSMC_Module_Buttons_ Bottom.stl
Hardware/Module STLs/OSMC_Module_Master_Button.stl
Hardware/Module STLs/OSMC_Module_Buttons_Button.stl
Hardware/Module STLs/OSMC_Module_Joystick_Top.stl
Hardware/Module STLs/OSMC_Module_Master_Top.stl

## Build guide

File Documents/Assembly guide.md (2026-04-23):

# Assembly Instructions

## 1. Gather Materials

* Refer to the **Bill of Materials (BOM)**.
* Download the main GitHub repository branch: [link](https://github.com/OSHE-Github/Open-Source-Modular-Controller/tree/main).

---

## 2. Order PCBs

1. Use a PCB manufacturer of your choice.
2. Gerber files are provided in the GitHub repository: [link](/Hardware/PCBs/gerber%20files/).
3. Boards can be ordered fully assembled or as bare PCBs.
4. Two versions exist:

   * **Custom ESP32 carrier board**
   * **ESP32-S3 DevKitC-based interposer board** (used in the shell design)

---

## 3. 3D Print the Shell

For Our Shells:
1. Body shells: [link](/Hardware/Shell/OSMC)
    - The full casing can be printed from the .step file
    - Individual case sections can be printed from the .stl files
2. Module shells: [link](/Hardware/Module%STLs)
    - Standard configurations require **7** modules: 1 Master, 2 Bumpers, 2 Joysticks, 2 Buttons
    - Each **Master** modules requires: 1 Master top casing, 1 Master bottom casing, 3 Master buttons
    - Each **Joystick** module requires: 1 Joystick top casing, 1 Joystick bottom casing
    - Each **Bumper** module requires 1 Bumper body casing and 2 Bumper caps
    - Each **Button** module requires: 1 Button top casing, 1 Button Bottom casing, 4 non-Master buttons
        - For push buttons, options include the normal button caps (**OSMC_Module_Buttons_Button.stl**) and the taller button caps (**Button Cap Taller.stl**)
        - For membrane buttons, print the SMD caps (**Button Cap SMD.stl**)
    
For **Custom** shell designs we recommend following this design process: [link](/Documents/Custom%Shell%Recommendations.md)

---

## 4. Prep the PCBs

1. **Sand** the edges to clean rough PCB cuts.
2. **Clean** with isopropyl alcohol to remove oils and residue.

---

## 5. Solder Components

Most boards in this build were hand-soldered.

### 5a. Custom ESP32-S3 Board

1. Solder **headers** on the bottom side.
2. Add remaining bottom-side components from lowest profile upward.
3. Solder the **USB port** using flux and wick.
4. Attach the **ESP32-S3 module**:

   * Pre-tin both board pads and module pads.
   * Heat with hot air until alignment occurs.
   * Hold lightly with tweezers if needed.

---

### 5b. Receiver Modules

1. Solder **female headers** at J1–J4.
2. Solder **26 AWG stranded wires** at J5 in this order (bottom → top):
   **Black – Red – Blue – Green – White – Yellow**.
3. Repeat wiring for all receiver boards.

---

### 5c. Dev Board Carrier

1. Insert headers into the ESP32 DevKit board and solder the carrier board on top.
2. Add push **buttons**.
3. Solder module wires in this order (top → bottom):
   **Red – Blue – Yellow – White – Green – Black**.

---

### 5d. Custom ESP Interposer

1. Solder header sockets.
2. Add remaining components.
   *(LEDs and their resistors are optional in this version.)*

---

### 5e. Joystick Modules

1. Solder joystick into labeled pads.
2. Insert and solder **male pin headers** on the opposite side.
3. Verify solder joints and joystick button clearance.
4. Place PCB into joystick shell and mark **up direction**.
5. Glue the top cover to the shell.

---

### 5f. Button Modules

1. Solder four push-buttons into labeled positions.
2. Insert and solder **male pin headers** on the opposite side.
3. Confirm button movement is unobstructed.
4. Place module in shell and mark **up direction**.
5. Glue the top plate onto the shell.

---

## 6. Upload Firmware

1. Install **Arduino IDE**.
2. Add ESP32 board manager URL in Preferences:
   `https://espressif.github.io/arduino-esp32/package_esp32_index.json`
3. Install the **ESP32 board package**.
4. Install **ESP32TinyUSB** library.
5. Import project files.
6. Connect via USB (UART port).
7. Select:
   * **ESP32-S3 Dev Module**
   * Proper **COM port**
8. Adjust other board settings as documented.
9. Compile and upload firmware.
10. Use **UART** for programming and **USB** for HID operation.

---

## 7. Assemble the Controller Shell

1. Place Receiver boards in the main shell.
2. Mark screw hole locations.
4. Install **M3 heat-set inserts** at marked points.
5. Repeat steps **1-3** instead with the Bumper modules
6. Connect the Bumper modules to the back of the Receiver board using the **JST** connectors
7. Screw Receiver board and Bumper modules into place.
8. Insert the **ESP-32** into the pin connectors on the bottom of the Receiver board
9. Set Button, Joystick, and Master modules on their respective pogo pins following the screenprint's outline
10. Place the shell's top plate over the modules, while verifying their alignment
11. Slide the shell's bottom plate into place

Note: To rearrange the top modules, carefully push up on the tab of the top plate, and repeat steps 8-9 with the new configuration

---

## 8. Testing

1. Plug the controller with the USB port
2. Use an online tester such as [Gamepad tester](https://hardwaretester.com/gamepad).
3. Verify:

   * All buttons register
   * Joystick axes update smoothly
   * No shorts or missed inputs

If issues occur, check soldering, wiring order, and continuity.

---

**Your controller is now fully assembled and ready for use!**

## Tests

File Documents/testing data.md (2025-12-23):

## Characterization & Testing
### Input Testing
Buttons and joysticks were tested using online gamepad testing tools. Several wiring issues and continuity problems were identified, including:
- Short on custom interposer board (corrected in revision)
- Stray wire strands causing unintended bridging → mitigated by moving to **26 AWG** wire

### Ergonomics
Feedback from Open Source Hardware Enterprise members indicated the controller is comfortable but slightly large for smaller hands.

### Hardware Continuity
Minor shorting issues were corrected and accounted for in later board versions. Shell design includes alignment features preventing mis‑insertion of modules.

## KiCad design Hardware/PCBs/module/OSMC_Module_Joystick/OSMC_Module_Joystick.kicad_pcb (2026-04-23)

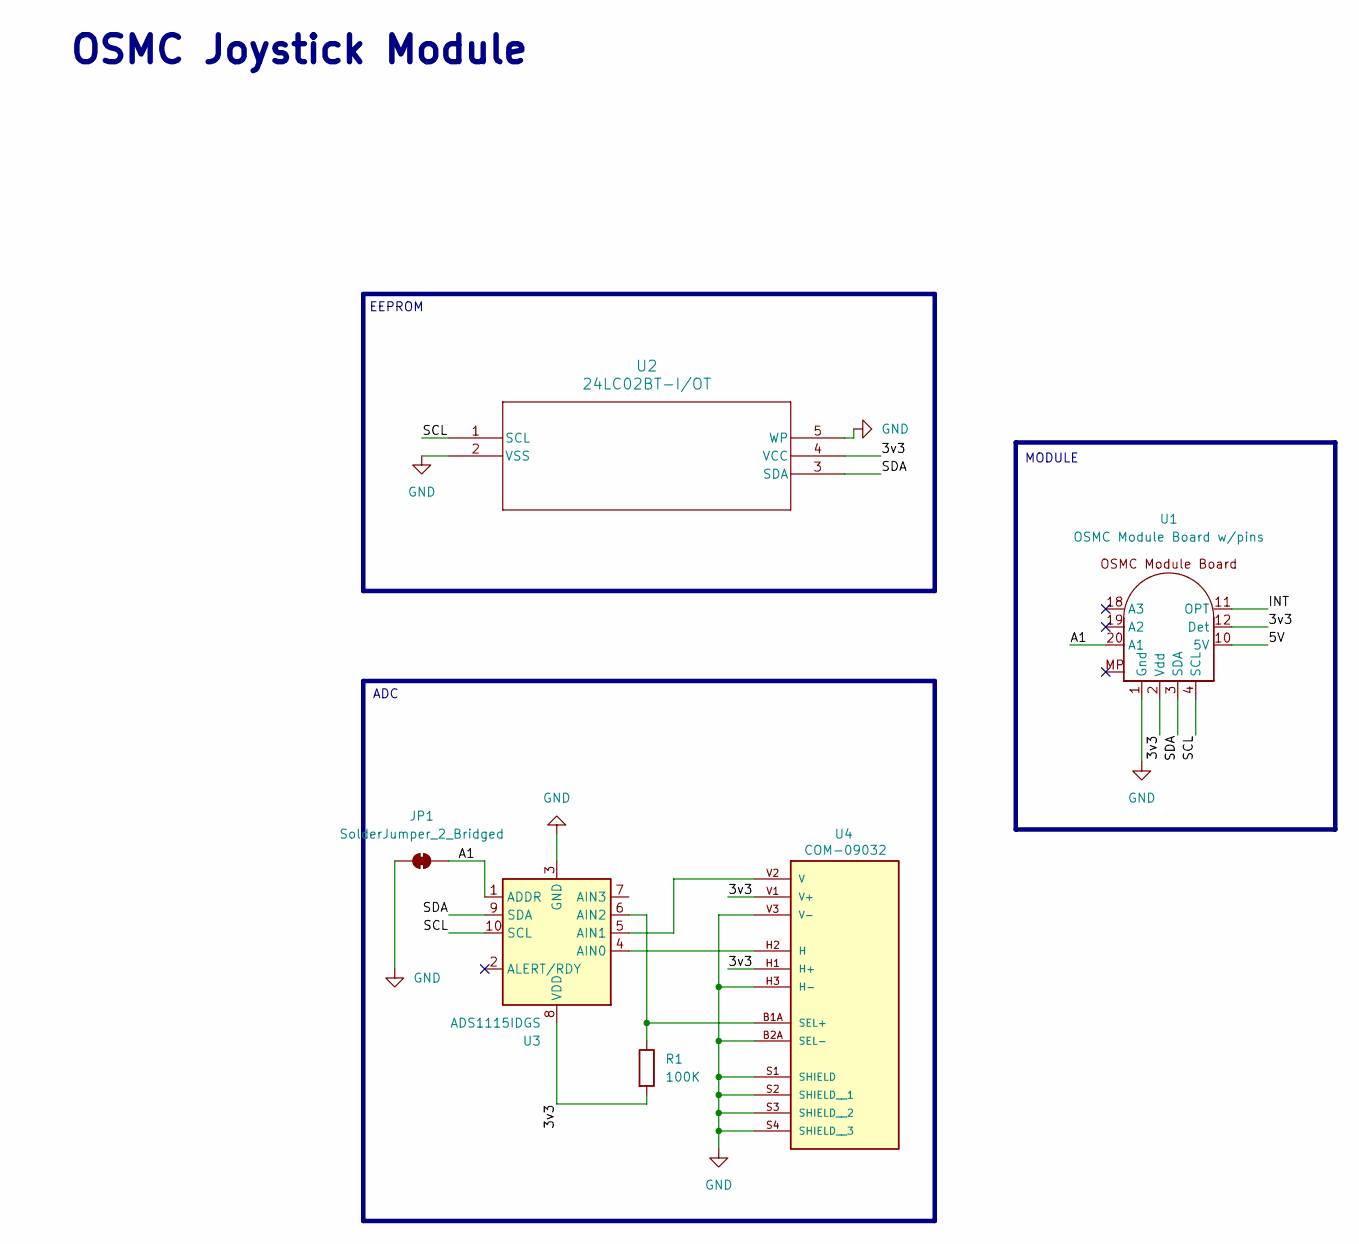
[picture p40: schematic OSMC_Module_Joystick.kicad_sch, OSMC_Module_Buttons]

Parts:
JP1: SolderJumper_2_Bridged; SolderJumper-2_P1.3mm_Bridged2Bar_RoundedPad1.0x1.5mm
R1: 100K; R_0603_1608Metric_Pad0.98x0.95mm_HandSolder
U1: OSMC Module Board w/pins; Module standard pin large
U2: 24LC02BT-I/OT; SOT-23-5_MC_MCH
U3: ADS1115IDGS; TSSOP-10_3x3mm_P0.5mm
U4: COM-09032; XDCR_COM-09032; PARTREV N/A

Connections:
/3v3: R1.2, U1.2 (Vdd), U1.6 (Vdd), U1.12 (Det), U1.13 (Int), U2.4 (VCC), U3.8 (VDD), U4.H1 (H+), U4.V1 (V+)
/5V: U1.10 (5V), U1.15 (5V)
/A1: JP1.2 (B), U1.20 (A1), U3.1 (ADDR)
/INT: U1.11 (OPT), U1.14 (OPT)
/SCL: U1.4 (SCL), U1.8 (SCL), U2.1 (SCL), U3.10 (SCL)
/SDA: U1.3 (SDA), U1.7 (SDA), U2.3 (SDA), U3.9 (SDA)
GND: JP1.1 (A), U1.1 (Gnd), U1.5 (Gnd), U1.9 (Gnd), U1.16 (GND), U2.2 (VSS), U2.5 (WP), U3.3 (GND), U4.B2A (SEL-), U4.B2B (SEL-), U4.H3 (H-), U4.S1 (SHIELD), U4.S2 (SHIELD__1), U4.S3 (SHIELD__2), U4.S4 (SHIELD__3), U4.V3 (V-)
unnamed: U3.4 (AIN0), U4.H2 (H)
unnamed: U3.5 (AIN1), U4.V2 (V)
unnamed: R1.1, U3.6 (AIN2), U4.B1A (SEL+), U4.B1B (SEL+)

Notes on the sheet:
EEPROM
ADC
OSMC Joystick Module
MODULE

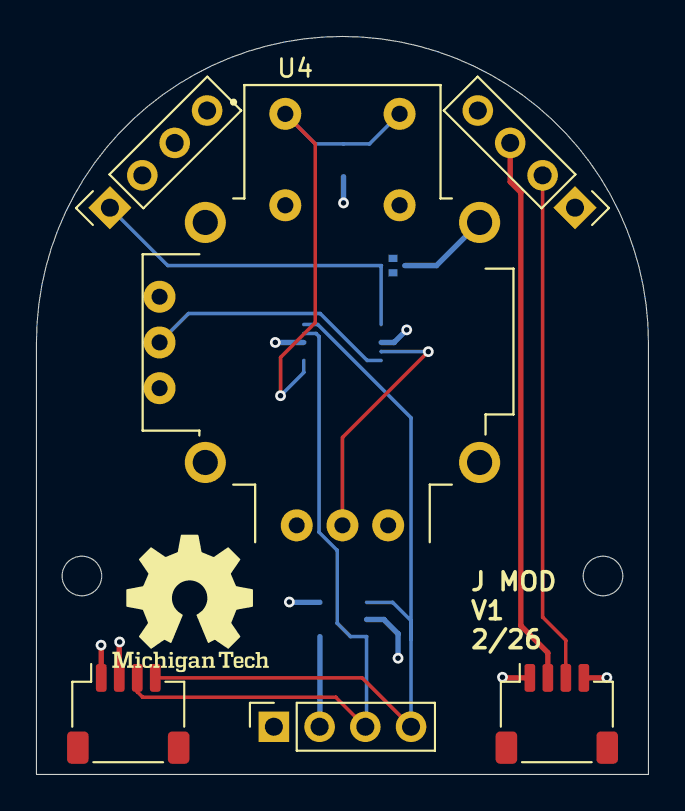
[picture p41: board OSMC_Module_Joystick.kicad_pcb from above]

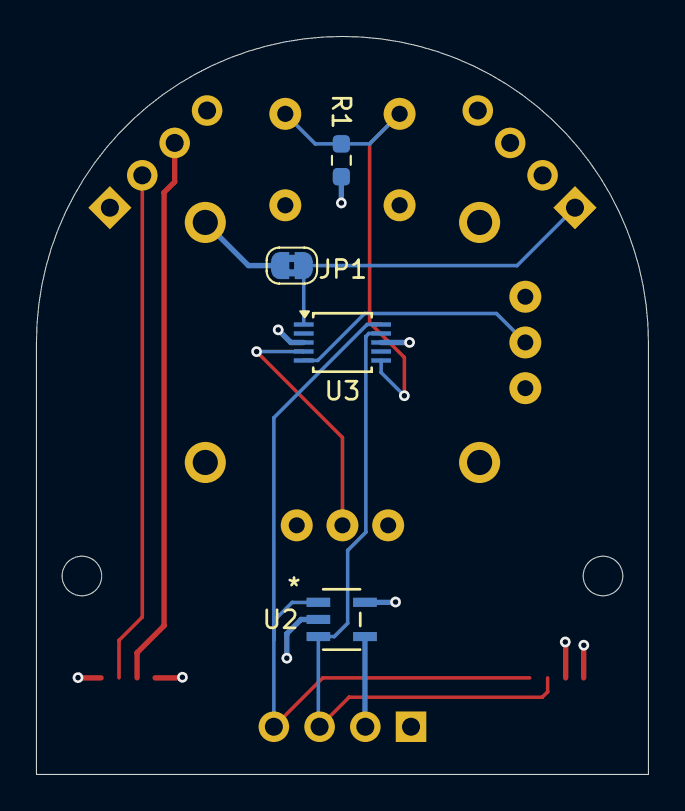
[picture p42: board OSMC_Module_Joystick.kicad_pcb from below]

Board: 4 copper layers, 34.0 x 41.0 mm, 6 parts (4 on the bottom side), 10 nets.

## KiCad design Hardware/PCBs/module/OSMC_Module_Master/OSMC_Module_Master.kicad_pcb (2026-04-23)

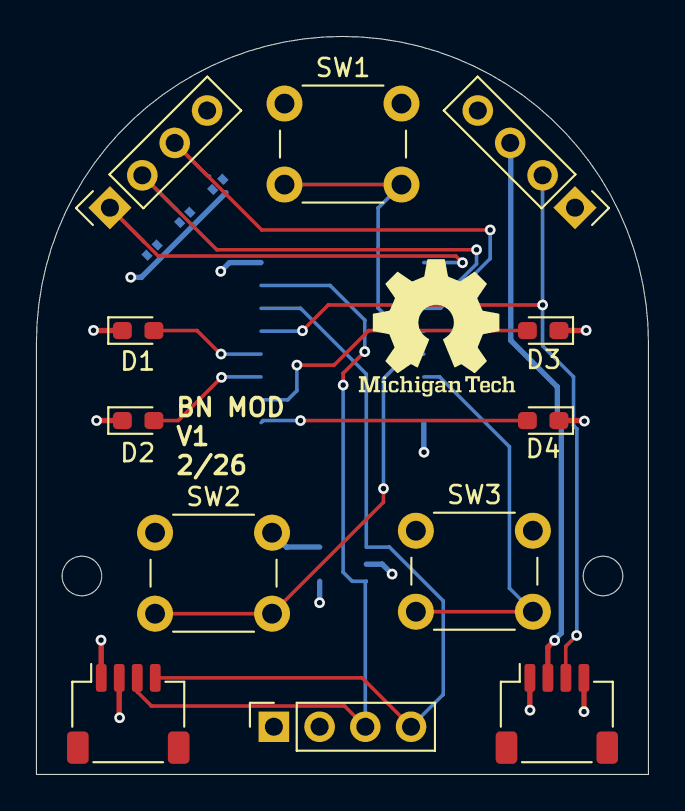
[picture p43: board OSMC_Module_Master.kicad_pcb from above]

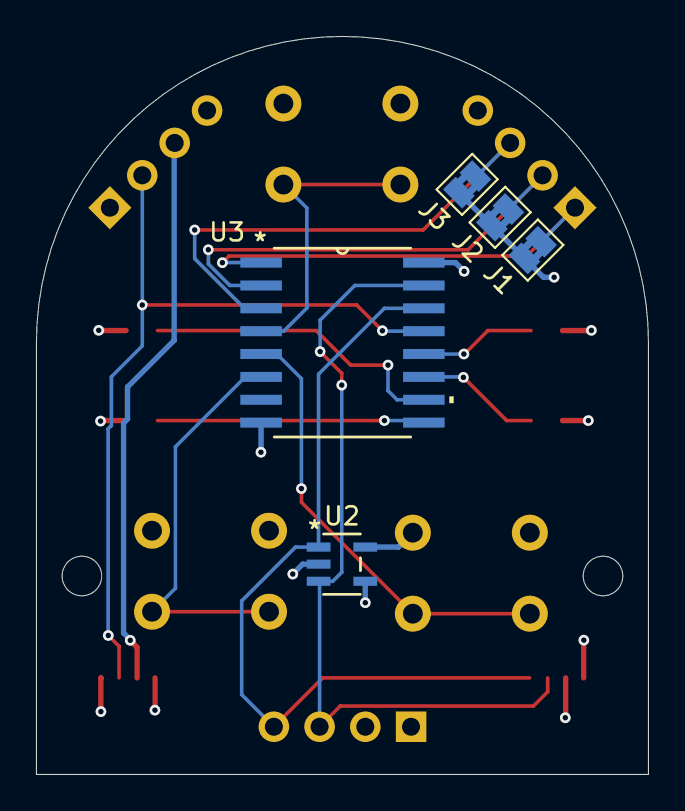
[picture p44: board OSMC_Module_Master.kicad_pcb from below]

Board: 4 copper layers, 34.0 x 41.0 mm, 13 parts (5 on the bottom side), 16 nets.

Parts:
D1, D2, D3, D4: LED; LED_0603_1608Metric_Pad1.05x0.95mm_HandSolder
J1, J2, J3: SolderJumper_2_Bridged; SolderJumper-2_P1.3mm_Bridged2Bar_Pad1.0x1.5mm
SW1, SW2, SW3: SW_Push; SW_PUSH_6mm
U1: OSMC Module Board w/pins; Module standard pin large
U2: 24LC02BT-I/OT; SOT-23-5_MC_MCH
U3: PCF8574DWR; DW16

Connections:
/3v3: D1.1 (K), D2.1 (K), D3.1 (K), D4.1 (K), U1.2 (Vdd), U1.6 (Vdd), U1.12 (Det), U1.13 (Int), U2.4 (VCC), U3.16 (VCC)
/5V: U1.10 (5V), U1.15 (5V)
/A0: J1.1 (A), U1.20 (A1), U3.1 (A0)
/A1: J2.1 (A), U1.19 (A2), U3.2 (A1)
/A2: J3.1 (A), U1.18 (A3), U3.3 (A2)
/B1: SW1.2, U3.4 (P0)
/B2: SW2.2, U3.5 (P1)
/B3: SW3.2, U3.6 (P2)
/D1: D1.2 (A), U3.12 (P7)
/D2: D2.2 (A), U3.11 (P6)
/D3: D3.2 (A), U3.10 (P5)
/D4: D4.2 (A), U3.9 (P4)
/INT: U1.11 (OPT), U1.14 (OPT), U3.13 (*INT)
/SCL: U1.4 (SCL), U1.8 (SCL), U2.1 (SCL), U3.14 (SCL)
/SDA: U1.3 (SDA), U1.7 (SDA), U2.3 (SDA), U3.15 (SDA)
GND: J1.2 (B), J2.2 (B), J3.2 (B), SW1.1, SW2.1, SW3.1, U1.1 (Gnd), U1.5 (Gnd), U1.9 (Gnd), U1.16 (GND), U2.2 (VSS), U2.5 (WP), U3.8 (GND)

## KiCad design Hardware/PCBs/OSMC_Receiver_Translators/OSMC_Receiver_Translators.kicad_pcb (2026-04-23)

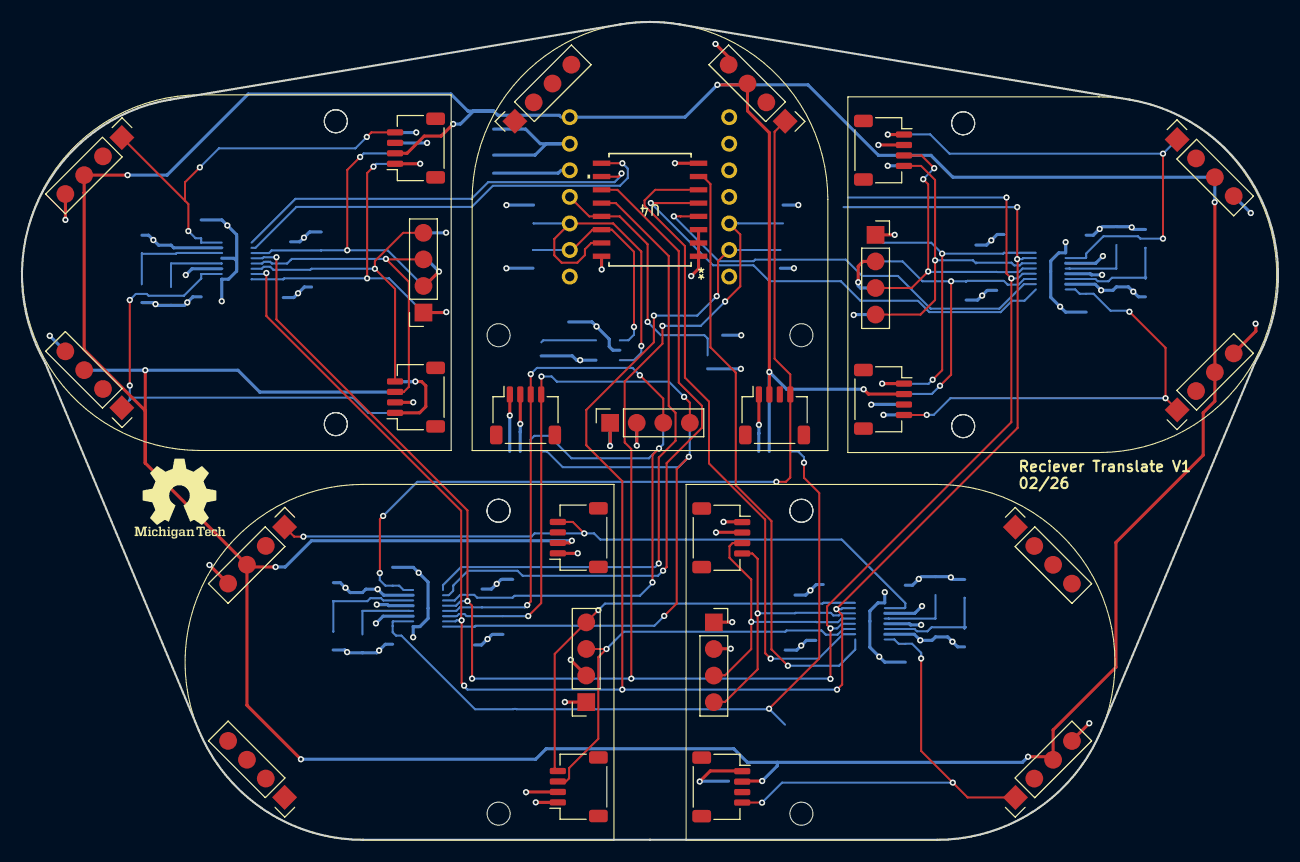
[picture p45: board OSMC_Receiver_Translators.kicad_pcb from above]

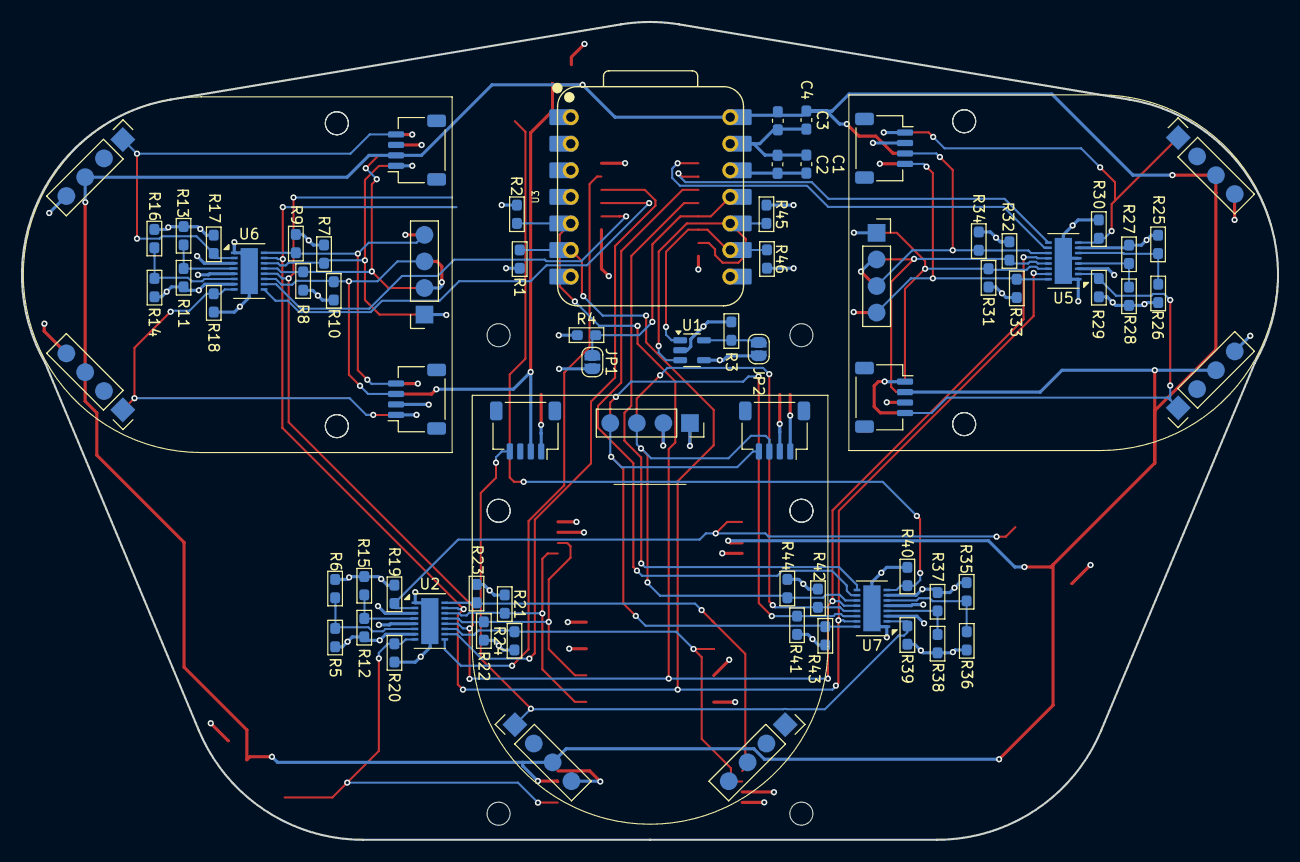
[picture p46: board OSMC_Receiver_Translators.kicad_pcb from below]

Board: 4 copper layers, 120.1 x 78.2 mm, 67 parts (61 on the bottom side), 49 nets.

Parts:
C1, C2: .1 u; C_0603_1608Metric_Pad1.08x0.95mm_HandSolder
C3, C4: C; C_0603_1608Metric_Pad1.08x0.95mm_HandSolder
JP1: int; SolderJumper-2_P1.3mm_Open_RoundedPad1.0x1.5mm
JP2: WP; SolderJumper-2_P1.3mm_Open_RoundedPad1.0x1.5mm
R1, R2, R7, R8, R9, R10, R17, R18, R19, R20, R21, R22, R23, R24, R29, R30, R31, R32, R33, R34, R39, R40, R41, R42, R43, R44, R45, R46: 10k; R_0603_1608Metric_Pad1.05x0.95mm_HandSolder
R3, R4: 100k; R_0603_1608Metric_Pad1.05x0.95mm_HandSolder
R5, R11: 976k; R_0603_1608Metric_Pad1.05x0.95mm_HandSolder
R6, R12: 182k; R_0603_1608Metric_Pad1.05x0.95mm_HandSolder
R13: 102k; R_0603_1608Metric_Pad1.05x0.95mm_HandSolder
R14: R; R_0603_1608Metric_Pad1.05x0.95mm_HandSolder
R15: 280k; R_0603_1608Metric_Pad1.05x0.95mm_HandSolder
R16: 0; R_0603_1608Metric_Pad1.05x0.95mm_HandSolder
R25, R27, R35, R37: 1000k; R_0603_1608Metric_Pad1.05x0.95mm_HandSolder
R26: 392k; R_0603_1608Metric_Pad1.05x0.95mm_HandSolder
R28: 523k; R_0603_1608Metric_Pad1.05x0.95mm_HandSolder
R36: 681k; R_0603_1608Metric_Pad1.05x0.95mm_HandSolder
R38: 887k; R_0603_1608Metric_Pad1.05x0.95mm_HandSolder
U1: 24AA02-OT; SOT-23-5
U2, U5, U6, U7: LTC4317; DFN-16-1EP_3x5mm_P0.5mm_EP1.66x4.4mm
U3: XIAO-ESP32-S3-DIP
U4: PCF8574DWR; DW16-L
U13, U14, U15, U16, U17, U18, U19, U20: OSMC Module Board; Module standard pin large outline

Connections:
+5V: C3.1, C4.1, U3.14 (5V), U13.10 (5V), U13.15 (5V), U14.10 (5V), U14.15 (5V), U15.10 (5V), U15.15 (5V), U16.10 (5V), U16.15 (5V), U17.10 (5V), U17.15 (5V), U18.10 (5V), U18.15 (5V), U19.10 (5V), U19.15 (5V), U20.10 (5V), U20.15 (5V)
/INT: JP1.1 (A), R4.2, U3.11 (PA6_A10_D10_MOSI), U4.13 (~INT)
/Modules/EN0: R18.2, U6.8 (ENABLE1), U13.12 (Det), U13.13 (Det)
/Modules/EN1: R17.2, U6.2 (ENABLE2), U15.12 (Det), U15.13 (Det)
/Modules/EN2: R20.2, U2.8 (ENABLE1), U16.12 (Det), U16.13 (Det)
/Modules/EN3: R19.2, U2.2 (ENABLE2), U18.12 (Det), U18.13 (Det)
/Modules/EN4: R30.2, U5.8 (ENABLE1), U17.12 (Det), U17.13 (Det)
/Modules/EN5: R29.2, U5.2 (ENABLE2), U20.12 (Det), U20.13 (Det)
/Modules/EN6: R40.2, U7.8 (ENABLE1), U14.12 (Det), U14.13 (Det)
/Modules/EN7: R39.2, U7.2 (ENABLE2), U19.12 (Det), U19.13 (Det)
/Modules/P0: U4.4 (P0), U6.10 (READY1)
/Modules/P1: U4.5 (P1), U6.9 (READY2)
/Modules/P2: U2.10 (READY1), U4.6 (P2)
/Modules/P3: U2.9 (READY2), U4.7 (P3)
/Modules/P4: U4.9 (P4), U5.10 (READY1)
/Modules/P5: U4.10 (P5), U5.9 (READY2)
/Modules/P6: U4.11 (P6), U7.10 (READY1)
/Modules/P7: U4.12 (P7), U7.9 (READY2)
/Modules/SCL0: R7.2, U6.14 (SCLOUT1), U13.4 (SCL), U13.8 (SCL)
/Modules/SCL1: R9.2, U6.16 (SCLOUT2), U15.4 (SCL), U15.8 (SCL)
/Modules/SCL2: R21.2, U2.14 (SCLOUT1), U16.4 (SCL), U16.8 (SCL)
/Modules/SCL3: R23.2, U2.16 (SCLOUT2), U18.4 (SCL), U18.8 (SCL)
/Modules/SCL4: R31.2, U5.14 (SCLOUT1), U17.4 (SCL), U17.8 (SCL)
/Modules/SCL5: R33.2, U5.16 (SCLOUT2), U20.4 (SCL), U20.8 (SCL)
/Modules/SCL6: R41.2, U7.14 (SCLOUT1), U14.4 (SCL), U14.8 (SCL)
/Modules/SCL7: R43.2, U7.16 (SCLOUT2), U19.4 (SCL), U19.8 (SCL)
/Modules/SDA0: R8.2, U6.13 (SDAOUT1), U13.3 (SDA), U13.7 (SDA)
/Modules/SDA1: R10.2, U6.11 (SDAOUT2), U15.3 (SDA), U15.7 (SDA)
/Modules/SDA2: R22.2, U2.13 (SDAOUT1), U16.3 (SDA), U16.7 (SDA)
/Modules/SDA3: R24.2, U2.11 (SDAOUT2), U18.3 (SDA), U18.7 (SDA)
/Modules/SDA4: R32.2, U5.13 (SDAOUT1), U17.3 (SDA), U17.7 (SDA)
/Modules/SDA5: R34.2, U5.11 (SDAOUT2), U20.3 (SDA), U20.7 (SDA)
/Modules/SDA6: R42.2, U7.13 (SDAOUT1), U14.3 (SDA), U14.7 (SDA)
/Modules/SDA7: R44.2, U7.11 (SDAOUT2), U19.3 (SDA), U19.7 (SDA)
/SCL: R1.2, U2.15 (SCLIN), U3.6 (PA9_A5_D5_SCL), U5.15 (SCLIN), U6.15 (SCLIN), U7.15 (SCLIN)
/SCL1: R46.2, U1.1 (SCL), U3.9 (PA7_A8_D8_SCK), U4.14 (SCL)
/SDA: R2.2, U2.12 (SDAIN), U3.5 (PA8_A4_D4_SDA), U5.12 (SDAIN), U6.12 (SDAIN), U7.12 (SDAIN)
/SDA1: R45.2, U1.3 (SDA), U3.10 (PA5_A9_D9_MISO), U4.15 (SDA)
/wp: JP2.1 (A), R3.2, U1.5 (WP)
GND: C1.2, C2.2, C3.2, C4.2, R3.1, R4.1, R6.2, R13.2, R15.2, R16.2, R17.1, R18.1, R19.1, R20.1, R26.2, R28.2, R29.1, R30.1, R36.2, R38.2, R39.1, R40.1, U1.2 (V_{SS}), U2.1 (GND), U2.3 (XORH2), U2.5 (XORH1), U2.17 (EP), U3.13 (GND), U4.1 (A0), U4.2 (A1), U4.3 (A2), U4.8 (GND), U5.1 (GND), U5.3 (XORH2), U5.5 (XORH1), U5.17 (EP), U6.1 (GND), U6.3 (XORH2), U6.5 (XORH1), U6.17 (EP), U7.1 (GND), U7.3 (XORH2), U7.5 (XORH1), U7.17 (EP), U13.1 (Gnd), U13.5 (Gnd), U13.9 (Gnd), U13.16 (GND), U14.1 (Gnd), U14.5 (Gnd), U14.9 (Gnd), U14.16 (GND), U15.1 (Gnd), U15.5 (Gnd), U15.9 (Gnd), U15.16 (GND), U16.1 (Gnd), U16.5 (Gnd), U16.9 (Gnd), U16.16 (GND), U17.1 (Gnd), U17.5 (Gnd), U17.9 (Gnd), U17.16 (GND), U18.1 (Gnd), U18.5 (Gnd), U18.9 (Gnd), U18.16 (GND), U19.1 (Gnd), U19.5 (Gnd), U19.9 (Gnd), U19.16 (GND), U20.1 (Gnd), U20.5 (Gnd), U20.9 (Gnd), U20.16 (GND)
unnamed: R5.2, R6.1, U2.6 (XORL1)
unnamed: R12.2, R15.1, U2.4 (XORL2)
unnamed: R25.2, R26.1, U5.6 (XORL1)
unnamed: R27.2, R28.1, U5.4 (XORL2)
unnamed: R14.2, R16.1, U6.6 (XORL1)
unnamed: R11.2, R13.1, U6.4 (XORL2)
unnamed: R35.2, R36.1, U7.6 (XORL1)
unnamed: R37.2, R38.1, U7.4 (XORL2)
VDD: C1.1, C2.1, JP1.2 (B), JP2.2 (B), R1.1, R2.1, R5.1, R7.1, R8.1, R9.1, R10.1, R11.1, R12.1, R14.1, R21.1, R22.1, R23.1, R24.1, R25.1, R27.1, R31.1, R32.1, R33.1, R34.1, R35.1, R37.1, R41.1, R42.1, R43.1, R44.1, R45.1, R46.1, U1.4 (V_{CC}), U2.7 (VCC), U3.12 (3V3), U4.16 (VDD), U5.7 (VCC), U6.7 (VCC), U7.7 (VCC), U13.2 (Vdd), U13.6 (Vdd), U14.2 (Vdd), U14.6 (Vdd), U15.2 (Vdd), U15.6 (Vdd), U16.2 (Vdd), U16.6 (Vdd), U17.2 (Vdd), U17.6 (Vdd), U18.2 (Vdd), U18.6 (Vdd), U19.2 (Vdd), U19.6 (Vdd), U20.2 (Vdd), U20.6 (Vdd)

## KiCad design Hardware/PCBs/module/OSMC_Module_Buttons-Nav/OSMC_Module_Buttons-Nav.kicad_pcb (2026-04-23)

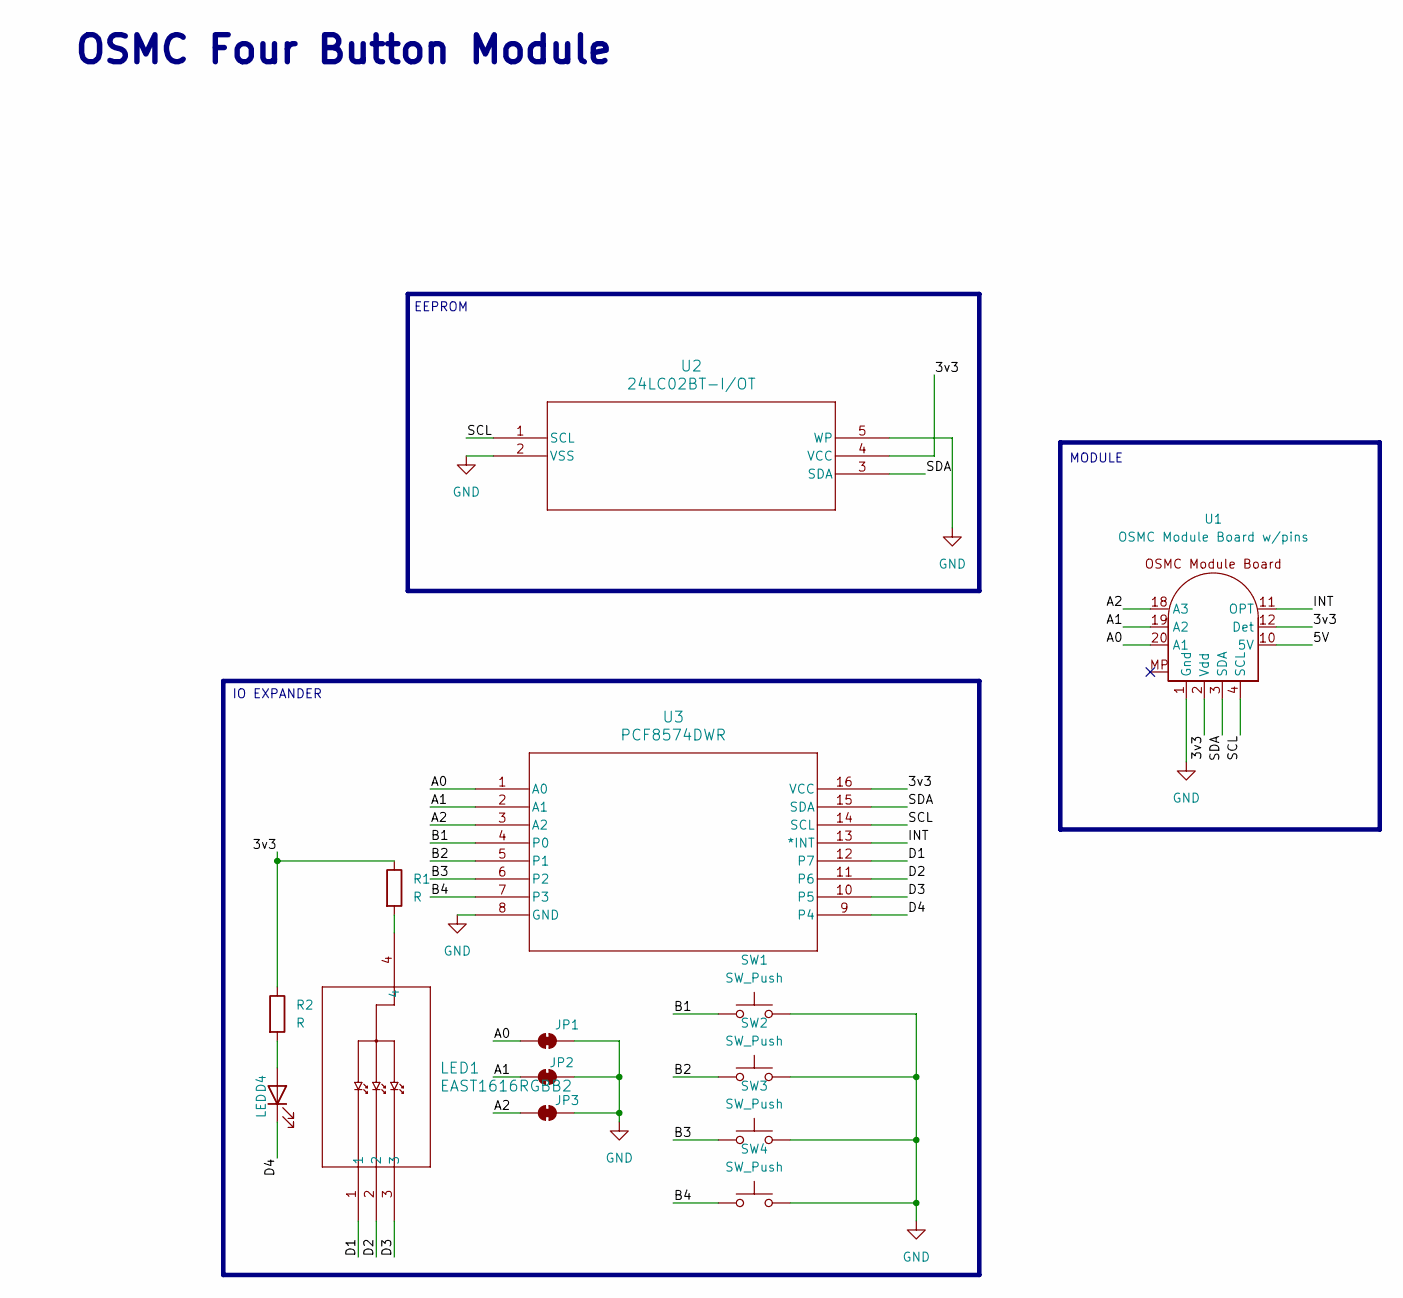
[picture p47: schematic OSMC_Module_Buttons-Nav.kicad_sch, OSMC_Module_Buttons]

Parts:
D4: LED; LED_0603_1608Metric_Pad1.05x0.95mm_HandSolder
JP1, JP2, JP3: SolderJumper_2_Bridged; SolderJumper-2_P1.3mm_Bridged2Bar_Pad1.0x1.5mm
LED1: EAST1616RGBB2; EAST1616RGBB2_EVE
R1, R2: R; R_0603_1608Metric_Pad0.98x0.95mm
SW1, SW2, SW3, SW4: SW_Push; SW_Push_1P1T_XKB_TS-1187A
U1: OSMC Module Board w/pins; Module standard pin large
U2: 24LC02BT-I/OT; SOT-23-5_MC_MCH
U3: PCF8574DWR; DW16

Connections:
/3v3: R1.1, R2.1, U1.2 (Vdd), U1.6 (Vdd), U1.12 (Det), U1.13 (Int), U2.4 (VCC), U3.16 (VCC)
/5V: U1.10 (5V), U1.15 (5V)
/A0: JP1.1 (A), U1.20 (A1), U3.1 (A0)
/A1: JP2.1 (A), U1.19 (A2), U3.2 (A1)
/A2: JP3.1 (A), U1.18 (A3), U3.3 (A2)
/B1: SW1.1, U3.4 (P0); also elsewhere on the board
/B2: SW2.1, U3.5 (P1); also elsewhere on the board
/B3: SW3.1, U3.6 (P2); also elsewhere on the board
/B4: SW4.1, U3.7 (P3); also elsewhere on the board
/D1: LED1.1, U3.12 (P7)
/D2: LED1.2, U3.11 (P6)
/D3: LED1.3, U3.10 (P5)
/D4: D4.1 (K), U3.9 (P4)
/INT: U1.11 (OPT), U1.14 (OPT), U3.13 (*INT)
/SCL: U1.4 (SCL), U1.8 (SCL), U2.1 (SCL), U3.14 (SCL)
/SDA: U1.3 (SDA), U1.7 (SDA), U2.3 (SDA), U3.15 (SDA)
GND: JP1.2 (B), JP2.2 (B), JP3.2 (B), SW1.2, SW2.2, SW3.2, SW4.2, U1.1 (Gnd), U1.5 (Gnd), U1.9 (Gnd), U1.16 (GND), U2.2 (VSS), U2.5 (WP), U3.8 (GND); also elsewhere on the board
unnamed: D4.2 (A), R2.2
unnamed: LED1.4, R1.2

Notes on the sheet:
EEPROM
IO EXPANDER
OSMC Four Button Module
MODULE

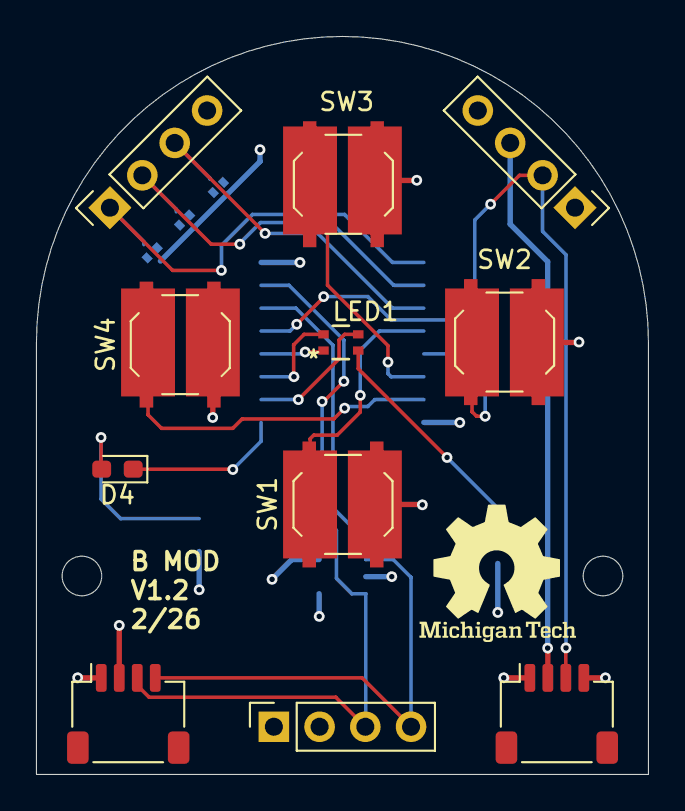
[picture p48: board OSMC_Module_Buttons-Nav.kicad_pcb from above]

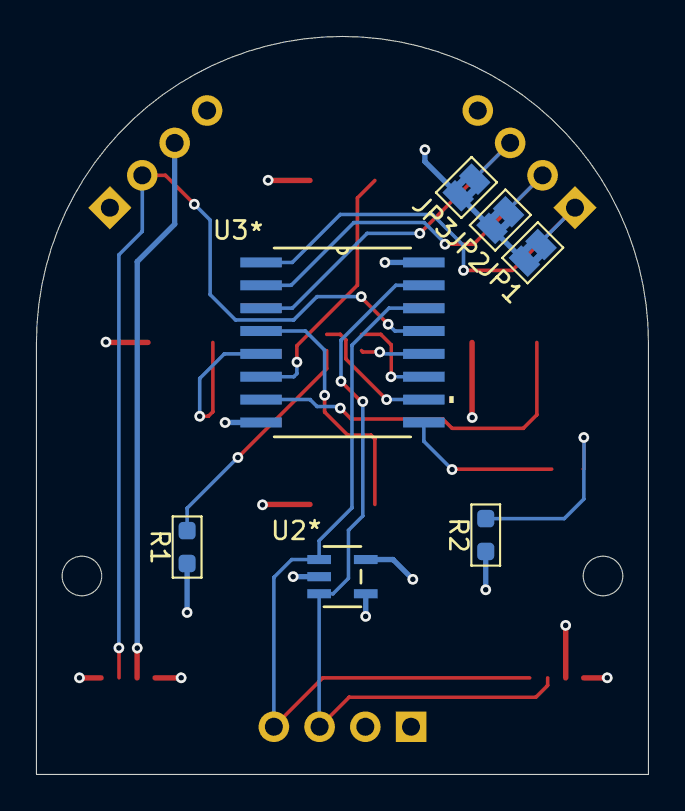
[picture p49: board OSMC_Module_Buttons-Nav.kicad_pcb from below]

Board: 4 copper layers, 34.0 x 41.0 mm, 15 parts (7 on the bottom side), 19 nets.

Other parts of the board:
J1: Conn_01x08_Socket; OSMC_Button_Membrane

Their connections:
/B1: J1.1; also elsewhere on the board
/B2: J1.3; also elsewhere on the board
/B3: J1.5; also elsewhere on the board
/B4: J1.7; also elsewhere on the board
GND: J1.2, J1.4, J1.6, J1.8; also elsewhere on the board

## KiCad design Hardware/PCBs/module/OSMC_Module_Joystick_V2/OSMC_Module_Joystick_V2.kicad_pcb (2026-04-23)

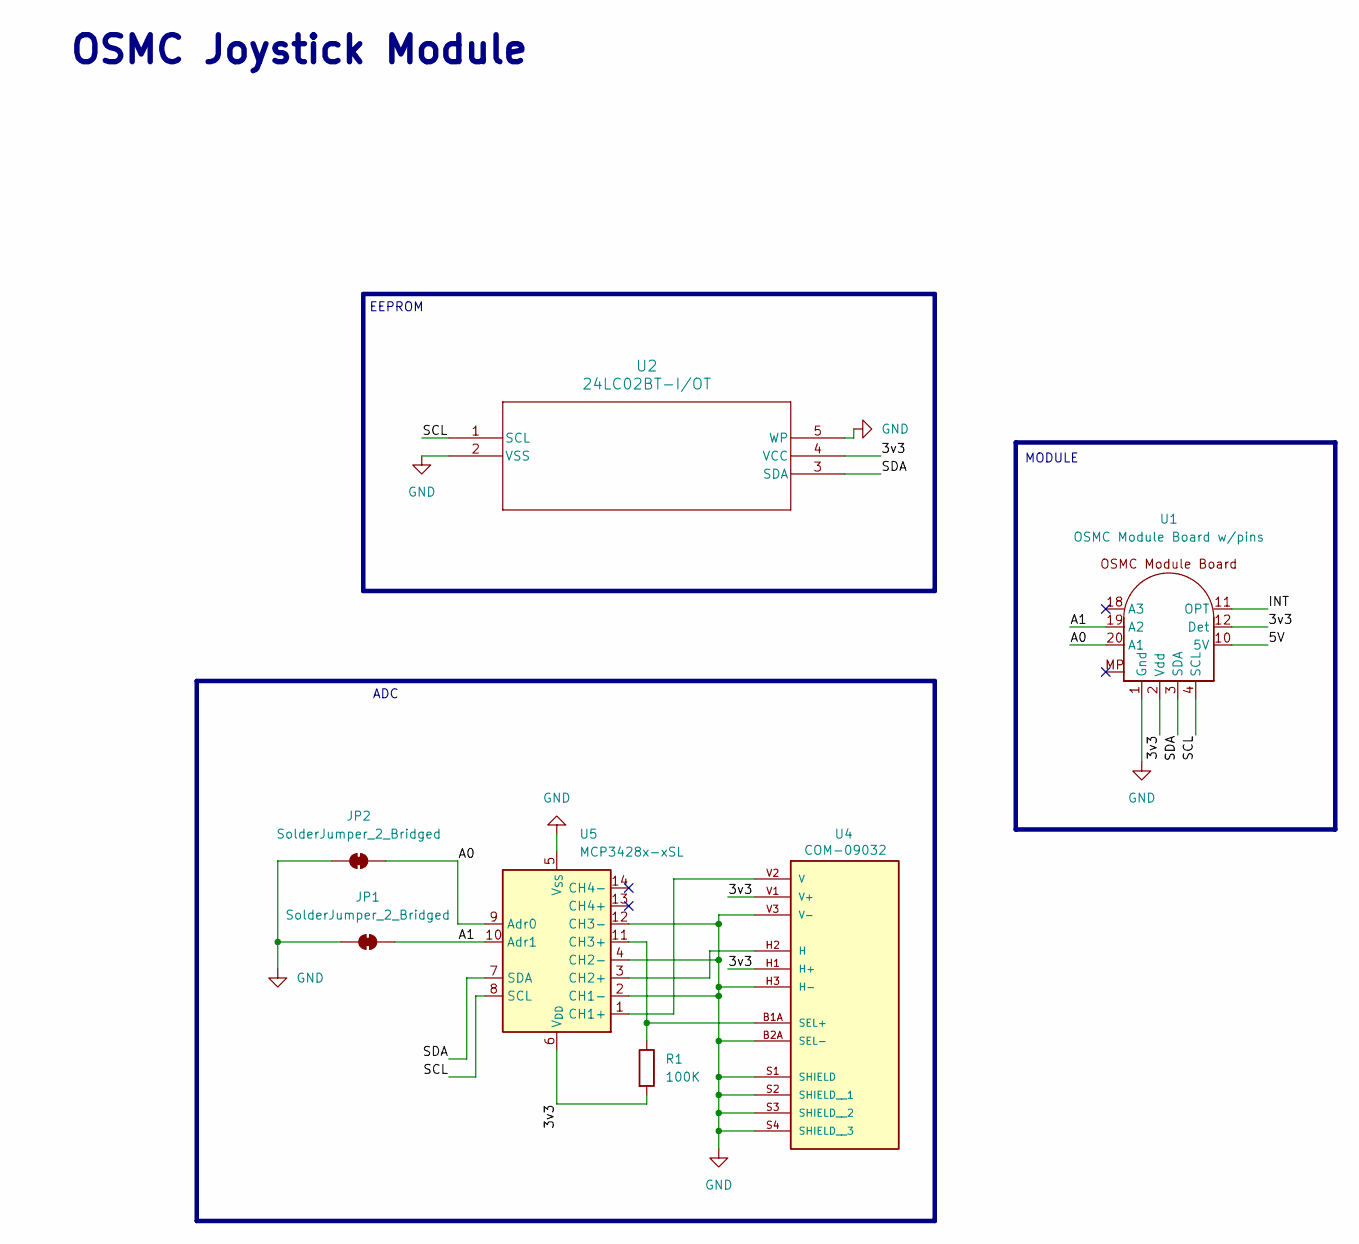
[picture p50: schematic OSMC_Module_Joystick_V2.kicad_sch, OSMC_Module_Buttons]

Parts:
JP1, JP2: SolderJumper_2_Bridged; SolderJumper-2_P1.3mm_Bridged2Bar_RoundedPad1.0x1.5mm
R1: 100K; R_0603_1608Metric_Pad0.98x0.95mm_HandSolder
U1: OSMC Module Board w/pins; Module standard pin large
U2: 24LC02BT-I/OT; SOT-23-5_MC_MCH
U4: COM-09032; XDCR_COM-09032; PARTREV N/A
U5: MCP3428x-xSL; SOIC-14_3.9x8.7mm_P1.27mm

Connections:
/3v3: R1.2, U1.2 (Vdd), U1.6 (Vdd), U1.12 (Det), U1.13 (Int), U2.4 (VCC), U4.H1 (H+), U4.V1 (V+), U5.6 (V_{DD})
/5V: U1.10 (5V), U1.15 (5V)
/A0: JP2.2 (B), U1.20 (A1), U5.9 (Adr0)
/A1: JP1.2 (B), U1.19 (A2), U5.10 (Adr1)
/INT: U1.11 (OPT), U1.14 (OPT)
/SCL: U1.4 (SCL), U1.8 (SCL), U2.1 (SCL), U5.8 (SCL)
/SDA: U1.3 (SDA), U1.7 (SDA), U2.3 (SDA), U5.7 (SDA)
GND: JP1.1 (A), JP2.1 (A), U1.1 (Gnd), U1.5 (Gnd), U1.9 (Gnd), U1.16 (GND), U2.2 (VSS), U2.5 (WP), U4.B2A (SEL-), U4.B2B (SEL-), U4.H3 (H-), U4.S1 (SHIELD), U4.S2 (SHIELD__1), U4.S3 (SHIELD__2), U4.S4 (SHIELD__3), U4.V3 (V-), U5.2 (CH1-), U5.4 (CH2-), U5.5 (V_{SS}), U5.12 (CH3-)
unnamed: U4.H2 (H), U5.3 (CH2+)
unnamed: U4.V2 (V), U5.1 (CH1+)
unnamed: R1.1, U4.B1A (SEL+), U4.B1B (SEL+), U5.11 (CH3+)

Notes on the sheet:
EEPROM
ADC
OSMC Joystick Module
MODULE

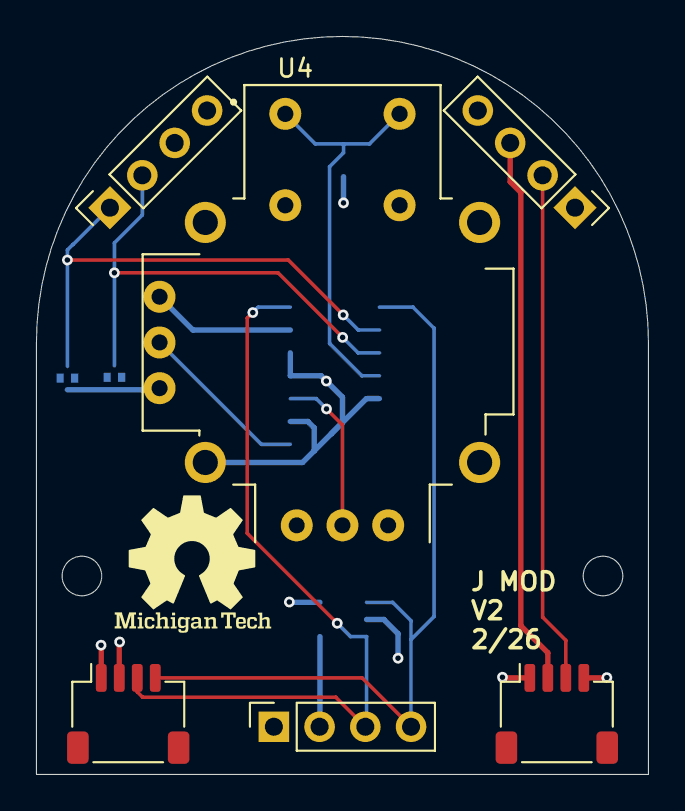
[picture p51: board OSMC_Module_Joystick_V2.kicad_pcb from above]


Board: 4 copper layers, 34.0 x 41.0 mm, 7 parts (5 on the bottom side), 11 nets.

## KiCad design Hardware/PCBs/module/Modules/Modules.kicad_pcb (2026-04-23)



Board: 2 copper layers, 50 parts (5 on the bottom side), 32 nets, no tracks yet.

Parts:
C1, C2: .1 u; C_0603_1608Metric_Pad1.08x0.95mm_HandSolder
C3, C4: C; C_0603_1608Metric_Pad1.08x0.95mm_HandSolder
J1, J5, J6, J10: JST SH; JST_SH_SM04B-SRSS-TB_1x04-1MP_P1.00mm_Horizontal
J2, J3, J4, J7, J8, J9: Conn_01x04; JST_SH_BM04B-SRSS-TB_1x04-1MP_P1.00mm_Vertical
J11: JST SH; PinSocket_1x04_P2.54mm_Vertical
J12: Conn_01x08_Socket; Button Spacing
JP1: WP; SolderJumper-2_P1.3mm_Open_RoundedPad1.0x1.5mm
JP2: Det; SolderJumper-2_P1.3mm_Open_RoundedPad1.0x1.5mm
R1, R2, R3, R4, R5, R6: 100k; R_0805_2012Metric_Pad1.15x1.40mm_HandSolder
R7, R8, R9, R10, R11, R12, R13, R14, R15, R16, R17, R18, R19, R20: 10k; R_0805_2012Metric_Pad1.15x1.40mm_HandSolder
SW1: SW_Push; Membrane Button semi 4 mm
U1: COM-09032; XDCR_COM-09032
U2: OSMC Module Board w/pins; Module standard pin small
U4: OSMC Module Board; DFN-16-1EP_3x5mm_P0.5mm_EP1.66x4.4mm
U5: OSMC Module Board w/pins; Module standard large
U6: OSMC Module Board; Module standard pin large
U7: 24AA02-OT; SOT-23-5
U8: PCF8574DWR; DW16-L
U9: ADS1115IDGS; TSSOP-10_3x3mm_P0.5mm
U10: LTC4317; TSSOP-10_3x3mm_P0.5mm
U11: XIAO-ESP32-S3-DIP
U12: MCP3428x-xSL; SOIC-14_3.9x8.7mm_P1.27mm

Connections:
/5V: C3.1, C4.1, J4.2, J5.2, J9.2, J10.2, U11.14 (5V)
/B0: R2.2, U8.4 (P0)
/B1: R4.2, U8.5 (P1)
/B2: R5.2, U8.6 (P2)
/B3: R6.2, U8.7 (P3)
/Det: J4.4, J9.4, JP2.1 (A), R1.2
/Gnd: C1.2, C2.2, C3.2, C4.2, J1.1, J2.4, J3.2, J3.3, J3.4, J4.1, J5.1, J6.1, J7.2, J7.3, J7.4, J8.4, J9.1, J10.1, J11.1, R1.1, R3.1, U1.B2A (SEL-), U1.H3 (H-), U1.S1 (SHIELD), U1.S2 (SHIELD__1), U1.S3 (SHIELD__2), U1.S4 (SHIELD__3), U1.V3 (V-), U7.2 (V_{SS}), U8.1 (A0), U8.2 (A1), U8.3 (A2), U8.8 (GND), U9.1 (ADDR), U9.3 (GND), U11.13 (GND)
/Opt: J4.3, J9.3
/SCL: J1.4, J2.1, J6.4, J8.1, J11.4, R12.2, U7.1 (SCL), U8.14 (SCL), U9.10 (SCL), U11.6 (PA9_A5_D5_SCL)
/SCL0: R7.2, R8.2
/SCL1: R9.2, R10.2, R20.2, U11.9 (PA7_A8_D8_SCK)
/SDA: J1.3, J2.2, J6.3, J8.2, J11.3, R15.2, U7.3 (SDA), U8.15 (SDA), U9.9 (SDA), U11.5 (PA8_A4_D4_SDA)
/SDA1: R19.2, U11.10 (PA5_A9_D9_MISO)
/Vdd: C1.1, C2.1, J1.2, J2.3, J6.2, J8.3, J11.2, JP1.2 (B), JP2.2 (B), R2.1, R4.1, R5.1, R6.1, R12.1, R15.1, R19.1, R20.1, U1.H1 (H+), U1.V1 (V+), U7.4 (V_{CC}), U8.16 (VDD), U9.8 (VDD), U11.12 (3V3)
/X1: U1.H2 (H), U9.5 (AIN1)
/Y1: U1.V2 (V), U9.4 (AIN0)
/Z1: U1.B1A (SEL+), U9.7 (AIN3)
/int: J5.4, J10.4, U8.13 (~INT), U9.2 (ALERT/RDY)
/wp: JP1.1 (A), R3.2, U7.5 (WP)
GND: R13.2, R16.2, U10.1 (GND), U10.3 (XORH2), U10.4 (XORL2)
unnamed: U2.10 (5V), U2.15 (5V)
unnamed: U2.12 (Det), U2.13 (Det)
unnamed: U2.1 (Gnd), U2.5 (Gnd), U2.9 (Gnd), U2.16 (GND)
unnamed: U2.11 (OPT), U2.14 (OPT)
unnamed: U2.4 (SCL), U2.8 (SCL)
unnamed: U2.3 (SDA), U2.7 (SDA)
unnamed: U2.2 (Vdd), U2.6 (Vdd)
unnamed: R18.2, U10.8 (ENABLE1)
unnamed: R17.2, U10.2 (ENABLE2)
unnamed: R11.2, R13.1, U10.5 (XORH1)
unnamed: R14.2, R16.1, U10.6 (XORL1)
VDD: R7.1, R8.1, R9.1, R10.1, R11.1, R14.1, R17.1, R18.1, U10.7 (VCC)

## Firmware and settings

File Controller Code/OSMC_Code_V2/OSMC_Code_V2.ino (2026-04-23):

const int DEADZONE = 9;    // Set deadzone
const int polldelay = 20;  // Set 100Hz polling rate
const bool test = false;

// Set module identifiers for readability
#define MODULE_RECEIVER 0x01
#define MODULE_BUTTON 0x04
#define MODULE_MASTER 0x05
#define MODULE_JOYSTICK 0x09
// Set button module identifiers for readability
#define BUTTON_DPAD 0x30
#define BUTTON_ABXY 0x20
#define BUTTON_TRIGGER 0x10

#include "USB.h"
#include "USBHIDGamepad.h"
#include "Wire.h"
#include "Adafruit_ADS1X15.h"

#if CFG_TUD_HID
USBHIDGamepad gamepad;

// FIXING ARRAYS

uint8_t deviceAddresses[7] = { 0 };
uint8_t deviceLocation[7] = { 0 };

// Make arrays to store information abnout modules
bool moduleIn[7] = { false };
uint8_t moduleType[7];
uint8_t moduleEEPROMaddr[7] = { 0x50, 0x51, 0x52, 0x53, 0x54, 0x55, 0x56 };
uint8_t moduleADCaddr[7] = { 0x48, 0x49, 0x4A, 0x4B, 0x00, 0x00, 0x00 };
bool moduleUsesADC[7] = { false };
bool adsInit[7] = { false };
uint16_t adcvalue[32];
int adsSize = sizeof(adsInit) / sizeof(bool);

static uint8_t modulesInUse = 0;
// uint32_t i2cScanCount = 0;

uint8_t moduleIOEaddr[7] = { 0x20, 0x21, 0x22, 0x23, 0x24, 0x25, 0x2f };
uint8_t moduleButtonType[7] = { 0 };

// Create ISR flag and assign interrupt pin
volatile bool moduleChangePending = false;
int INT_PIN = 11;

// Create 4 objects for each potential adc
Adafruit_ADS1115 ads0;
Adafruit_ADS1115 ads1;
Adafruit_ADS1115 ads2;
Adafruit_ADS1115 ads3;
Adafruit_ADS1115 ads4;

// Declare function
// void ARDUINO_ISR_ATTR moduleSwap();
// void scanModules();

void setup() {
  Serial.begin(115200);
  // Initialize BUS1 I2C communication on pins 21 (SDA) and 22 (SCL)
  Wire.begin();
  Wire1.begin(7, 8);

  // Sets clock frequency to 100kHz
  Wire.setClock(100000);
  Wire1.setClock(100000);

  Wire.setTimeout(10);

  // Theres only one INT pin, scan every module for detection
  // Attach ISR to the pin which
  // pinMode(INT_PIN, INPUT_PULLUP);
  // attachInterrupt(digitalPinToInterrupt(INT_PIN), moduleSwap, CHANGE);

  // Set LED pins for output


  delay(10);
  gamepad.begin();
}

void loop() {
  fastScanModules();

  // I2C Addressing: Top left is default, top right is +1,
  // bottom left is +2, bottom right is +3. Addresses increment in Z shape

  // I2C IO Expanders have addresses 0x20-0x27
  // They store the data of the 8 pins in a single byte
  // Writing 1 to a bit enables the pin for input

  int LxVal = 0;
  int LyVal = 0;
  int RxVal = 0;
  int RyVal = 0;
  int L3Val = 0;
  int R3Val = 0;
  uint16_t Lx = 0;
  uint16_t Ly = 0;
  uint16_t Rx = 0;
  uint16_t Ry = 0;
  uint16_t L3 = 0;
  uint16_t R3 = 0;
  int RTrigger = 0;
  int LTrigger = 0;
  uint8_t hat = 0;
  uint32_t buttons = 0;
  bool leftJoystickPresent = false;
  bool rightJoystickPresent = false;

  // If ISR was tripped this will run
  // if (moduleChangePending) {
  //   moduleChangePending = false;
  //   scanModules();
  // }


  // Create inside loop for obtaining data from each module
  for (int i = 0; i < 7; i++) {
    uint8_t addr = moduleEEPROMaddr[i];
    // If module slot is empty go to next slot
    if (moduleIn[i] != true) {
      continue;
    }

    // If the module is a joystick
    if (moduleType[i] == MODULE_JOYSTICK) {

      // guard
      if (!moduleUsesADC[i]) {
        continue;
      }

      uint8_t addr = moduleADCaddr[i];

      // recheck device before reading
      Wire.beginTransmission(addr);
      if (Wire.endTransmission() != 0) {
        moduleIn[i] = false;
        moduleType[i] = 0;
        moduleUsesADC[i] = false;
        continue;
      }

      // Find the module index
      int index = addr - 0x48;

      switch (index) {
        case 0:
          break;
        case 1:
          // If the index is 0, then the joystick is on right side
          // read adc values into Rx and Ry for proper conversion
          // Subtract R values from 65535 to account for upside orientation
          leftJoystickPresent = true;
          Ly = (ads1.readADC_SingleEnded(0));
          Lx = (ads1.readADC_SingleEnded(1));
          L3 = (ads1.readADC_SingleEnded(2));
          break;
        case 2:
          // If the index is even, then joystick is on left side
          // read adc values into Lx and Ly for proper conversion
          rightJoystickPresent = true;
          Ry = ads2.readADC_SingleEnded(0);
          Rx = ads2.readADC_SingleEnded(1);
          R3 = ads2.readADC_SingleEnded(2);
          break;
        case 3:
          // If the index is 0, then the joystick is on right side
          // read adc values into Rx and Ry for proper conversion
          // Subtract R values from 65535 to account for upside orientation
          leftJoystickPresent = true;
          Ly = (ads3.readADC_SingleEnded(0));
          Lx = (ads3.readADC_SingleEnded(1));
          L3 = (ads3.readADC_SingleEnded(2));
          break;
        case 4:
          // If the index is even, then joystick is on left side
          // read adc values into Lx and Ly for proper conversion
          rightJoystickPresent = true;
          Ry = ads4.readADC_SingleEnded(0);
          Rx = ads4.readADC_SingleEnded(1);
          R3 = ads4.readADC_SingleEnded(2);
          break;
        default:
          continue;
      }

      // Map each read adc variable to appropriate controller variable
      // and value for proper function, create deadzone to avoid stick drift
      if (leftJoystickPresent) {
        // x-axis for left joystick
        LxVal = map(Lx, 0, 17000, 127, -127);
        if (abs(LxVal) < DEADZONE) {
          LxVal = 0;
        }
        if (LxVal < -127) LxVal = -127;
        // y-axis for left joystick
        LyVal = map(Ly, 0, 17000, -127, 127);
        if (abs(LyVal) < DEADZONE) {
          LyVal = 0;
        }
        if (LyVal > 127) LyVal = 127;

        // Add L3 to the bitmask, maybe not here?
        if ((L3 > 60000) || (L3 < 1000)) buttons |= (1 << 10);
      }

      if (rightJoystickPresent) {
        // x-axis for right joystick
        RxVal = map(Rx, 0, 17000, -127, 127);
        if (abs(RxVal) < DEADZONE) {
          RxVal = 0;
        }
        if (RxVal > 127) RxVal = 127;
        // y-axis for right joystick
        RyVal = map(Ry, 0, 17000, 127, -127);
        if (abs(RyVal) < DEADZONE) {
          RyVal = 0;
        }
        if (RyVal < -127) RyVal = -127;

        // Add R3 to the bitmask, maybe not here?
        if ((R3 > 60000) || (R3 < 1000)) buttons |= (1 << 11);
      }
      // Go to next module and read

      continue;
    }

    // If module is buttons
    if (moduleType[i] == MODULE_BUTTON) {
      // Request all byte data from buttons
      Wire.beginTransmission(moduleIOEaddr[i]);
      uint8_t retval = Wire.endTransmission();

      // Serial.printf("RETURN TEST FROM BUTTON: %d\n", retval);

      Wire.requestFrom(moduleIOEaddr[i], 1);
      uint8_t data = Wire.read();

      // Serial.printf("DATA TEST FROM BUTTON: %d\n", data);


      // for (int k = 0; k < 6; k++){
      //   Serial.printf("button type 0x%X\n", moduleButtonType[k]);
      // }

      switch (moduleButtonType[i]) {
        // In this case, the button module is the dpad
        case BUTTON_DPAD:
          {

            // All pins are high, LOW = button pressed
            // Following code assumes bit 0, 2, 4, 6 are up down left right respectively
            const uint8_t upByte = 0xFD;     // 11111101
            const uint8_t downByte = 0xF7;   // 11110111
            const uint8_t leftByte = 0xFB;   // 11111011
            const uint8_t rightByte = 0xFE;  // 11111110

            // Switch statement to determine direction
            switch (data) {
              // Up right diagonal
              case (upByte & rightByte):
                buttons |= (1 << 12);
                buttons |= (1 << 15);
                hat = 2;
                break;
              // Up left diagonal
              case (upByte & leftByte):
                buttons |= (1 << 12);
                buttons |= (1 << 14);
                hat = 8;
                break;
              // Down right diagonal
              case (downByte & rightByte):
                buttons |= (1 << 13);
                buttons |= (1 << 15);
                hat = 4;
                break;
              // Down left diagonal
              case (downByte & leftByte):
                buttons |= (1 << 13);
                buttons |= (1 << 14);
                hat = 6;
                break;
              // Only up
              case (upByte):
                buttons |= (1 << 12);
                hat = 1;
                break;
              // Only down
              case (downByte):
                buttons |= (1 << 13);
                hat = 5;
                break;
              // Only right
              case (rightByte):
                buttons |= (1 << 15);
                hat = 3;
                break;
              // Only left
              case (leftByte):
                buttons |= (1 << 14);
                hat = 7;
                break;
              // Nothing
              default: hat = 0;
            }
            break;
          }

          // In this case, button module is ABXY
        case BUTTON_ABXY:
          {
            // Serial.println("jew");
            // All pins are high, LOW = button pressed
            // Following code assumes bit 0, 2, 4, 6 are up (Y) down (A) left (X) right (B) respectively
            // A: 11111011 B: 10111111 X: 11101111 Y: 11111110

            // Use if statements to assign data to button bitmask for multi inputs
            // If the data byte has 0 at bit 2, A is pressed
            if (!(data & (1 << 1))) buttons |= (1 << 0);  // A
            if (!(data & (1 << 2))) buttons |= (1 << 1);  // B
            if (!(data & (1 << 3))) buttons |= (1 << 3);  // Y
            if (!(data & (1 << 0))) buttons |= (1 << 2);  // X

            break;
          }

          // In this case, button module is trigger/bumper
        case BUTTON_TRIGGER:
          {
            // 0x24 address means left side
            if (moduleIOEaddr[i] == 0x20) {
              // Pin 0 is bumper, Pin 7 is trigger
              // Bit 5 in bitmask is the Left bumper
              // Left trigger has its own variable value
              if (!(data & (1 << 1))) buttons |= (1 << 4);
              if (!(data & (1 << 0))) {
                LTrigger = 127;
                buttons |= (1 << 6);
              }

            } else {
              // If not on left, its on right, Pins swap because upside down
              if (!(data & (1 << 0))) buttons |= (1 << 5);
              if (!(data & (1 << 1))) {
                RTrigger = 127;
                buttons |= (1 << 7);
              }
            }
            break;
          }
      }
      continue;
    }

    if (moduleType[i] == MODULE_MASTER) {
      Wire.requestFrom(moduleIOEaddr[i], 1);
      uint8_t data = Wire.read();
      uint8_t version = 1;
      if (version == 1) {
        // Following code assumings start, select, home button are bits 0 3 7
        if (!(data & (1 << 0))) buttons |= (1 << 16);
        if (!(data & (1 << 1))) buttons |= (1 << 8);
        if (!(data & (1 << 2))) buttons |= (1 << 9);
      } else if (version == 2) {
        if (!(data & (1 << 1))) buttons |= (1 << 9);   // A
        if (!(data & (1 << 2))) buttons |= (1 << 17);  // B
        if (!(data & (1 << 3))) buttons |= (1 << 8);   // Y
        if (!(data & (1 << 0))) buttons |= (1 << 16);  // X
      }
    }
  }

  // conditional to see testing data or run program
  if (!test) {
    // -------------------
    // Send state to HID
    // -------------------
    gamepad.send(
      LxVal,     // LX
      LyVal,     // LY
      RxVal,     // RX
      LTrigger,  // L2 (treated as analog axis)
      RyVal,     // RY
      RTrigger,  // R2 (treated as analog axis)
      hat,       // D-pad hat
      buttons    // 32 buttons bitmask
    );

    static uint32_t testcount = 0;
    Serial.println("Joystick position");
    Serial.printf("Left y: %d x: %d trigger: %d \nRight y: %d x: %d trigger: %d \n", LyVal, LxVal, LTrigger, RyVal, RxVal, RTrigger);
    Serial.printf("Button State A B X Y R1 L1 R2 L2 R3 L3 \n");
    Serial.println(buttons, BIN);
    Serial.printf("Hat position: %d \n", hat);
    Serial.printf("Count: %d \n", testcount++);

  } else {

    for (int i = 0; i < 5; i++) {
      Serial.printf("Module %d slot %d: 0x%X\n", moduleIn[i], i, moduleType[i]);
    }

    Serial.println("Scanning Wire bus...");
    int found = 0;
    for (uint8_t addr = 1; addr < 127; addr++) {
      Wire.beginTransmission(addr);
      uint8_t err = Wire.endTransmission();
      if (err == 0) {
        Serial.printf("Found device at 0x%02X\n", addr);
        found++;
      }
    }
    if (found == 0) {
      Serial.println("No devices found - check pins or swap SDA/SCL");
    } else {
      Serial.printf("Scan done, %d device(s) found\n", found);
    }
    if (found > 5) {
      static uint32_t testcount = 0;
      Serial.println("Joystick position");
      Serial.printf("Left y: %d x: %d trigger: %d \nRight y: %d x: %d trigger: %d \n", LyVal, LxVal, LTrigger, RyVal, RxVal, RTrigger);
      Serial.printf("Button State A B X Y R1 L1 R2 L2 R3 L3 \n");
      Serial.println(buttons, BIN);
      Serial.printf("Hat position: %d \n", hat);
      Serial.printf("Count: %d \n", testcount++);
    }
    delay(1000);
  }

  delay(polldelay);  // Small poll delay
}
/**
void i2cScan() {
  modulesInUse = 0;

  memset(deviceLocation, 0, sizeof(deviceLocation));
  memset(deviceAddresses, 0, sizeof(deviceAddresses));

  uint8_t address, error;
  int devices = 0;
  int deviceArrayCount = 0;
  for(address = 1; address < 127; address++ ) {
    // The i2c_scanner uses the return value of
    // the Write.endTransmisstion to see if
    // a device did acknowledge to the address.
    Wire.beginTransmission(address);
    error = Wire.endTransmission();

    if (error == 0) {
      // Serial.print("I2C device found at address 0x");
      devices++;
      if (address<16) {
        // Serial.print("0");
        // Serial.print(address,HEX);
        // Serial.println("  !");
      } else {
        // Serial.print(address, HEX);
        // Serial.println("  !");
      }

      if ( (address > 0x57) || (address < 0x50) ) {
        deviceAddresses[deviceArrayCount++] = address;
        modulesInUse++;
        // Serial.println("Device added to array");
      }
    }

  }


  if (devices == 0) {
    // Serial.println("No I2C devices found\n");
  } else {
    // Serial.println("done\n");
    for (int l = 0; l < deviceArrayCount; l++) {
      uint8_t addr = deviceAddresses[l];
      if ( addr < 0x48) {
        // If lower than 0x48, IOExpander, -0x20 to get slot
        deviceLocation[addr - 0x20] = addr;
      } else {
        deviceLocation[addr - 0x48] = addr;
      }
    }

    for (int l = 0; l < 7; l++) {
      Serial.printf("Slot %d: 0x%X\n", l, deviceLocation[l]);
    }
  }

}

Define interrupt function for automatic module detection
void ARDUINO_ISR_ATTR moduleSwap() {
  // When interrupt is tripped, set flag
  moduleChangePending = true;
  Serial.println("Change detected!");
}

Function that scans modules, not using anymore
void scanModules() {
  // Scan devices on i2c bus
  i2cScan();

  for (int i = 0; i < 8; i++) {
    // If on the extra iteration of loop, do lights and then break
    if (i == 7) {
      // Check status of 4 face modules
      for (int j = 0; j < 4; j++) {
        if (moduleIn[j] == false) {
          // LED pins are 9-12, turn the lights on if module is missing
          digitalWrite(j+9, 1);
        } else {
          // Turn the lights off if module is there
          digitalWrite(j+9, 0);
        }
      }
      Serial.println("End of scan!");
      break;
    }


    if (deviceLocation[i] == 0) {
      // If 0 at that slot index, module doesnt exist
      moduleIn[i] = false;
      moduleType[i] = 0;
      moduleUsesADC[i] = false;
      continue;
    }

    // If this is reached, module exists. Read and store data
    moduleIn[i] = true;

    // Calculate possible joystick addresses
    uint8_t addr = deviceLocation[i];

    if ((addr >= 0x48) && (addr <= 0x4B)) {
      Serial.printf("Joystick scanned in slot %d\n", i);
      moduleType[i] = MODULE_JOYSTICK;
      moduleADCaddr[i] = addr;
      // Capped at 4 ADCs, calculate index so not to break data array
      // Index is 0, 1, 2, 3 based on address
      uint8_t index = addr - 0x48;

      // If ADC at this address is not initialized, initialize
      if (!adsInit[index]) {
        // Initialize the ads to read from
        switch (index) {
          case 0: ads0.begin(0x48);
          break;
          case 1: ads1.begin(0x49);
          break;
          case 2: ads2.begin(0x4A);
          break;
          case 3: ads3.begin(0x4B);
          break;
        }
        // Set ads at this index as initialized so we don't reinitialize later
        adsInit[index] = true;
      }
      // Set that an ADC has been initialized in this location so we can read from it
      moduleUsesADC[i] = true;
      continue;
    } else {
      // Module isn't a joystick so there is no ADC at this location, actually turning ADS
      // off is too much work so use this value to disable it's use
      moduleUsesADC[i] = false;
    }

    // If module is a set of buttons, setup to be read properly
    if ((addr >= 0x20) && (addr <= 0x25)  ) {
      Serial.printf("Button scanned in slot %d\n", i);
      uint8_t addrOffset = addr - 0x20;
      uint8_t eepromAddr = 0x50 + addrOffset;

      moduleType[i] = MODULE_BUTTON;
      moduleIOEaddr[i] = addr;
      uint8_t buttonClarifier = 0;

      if ((addrOffset == 0) || (addrOffset == 2) ) {
        // If module on right side of controller it is abxy
        buttonClarifier = BUTTON_ABXY;
      } else if ((addrOffset == 3) || (addrOffset == 4)) {
        // DPAD on the left side
        buttonClarifier = BUTTON_DPAD;
      } else {
        // Triggers on the back
        buttonClarifier = BUTTON_TRIGGER;
      }

      // Wire.beginTransmission(eepromAddr);
      // Wire.write(0x00);
      // uint8_t errorT = Wire.endTransmission();

      // Serial.printf("endTransmission return: %d\n", errorT);

      // Wire.requestFrom(eepromAddr, 2);
      // uint8_t moduleIndicator = Wire.read();
      // uint8_t buttonClarifier = Wire.read();
      // Serial.printf("Module Type 0x%X\n", buttonClarifier);


      // Wire.read() another line from the eeprom to determine the type
      // of button module that it is, write 1s to all pins on IOE to make them readable

      switch (buttonClarifier) {
        // Trigger identifer is 0x10
        case BUTTON_TRIGGER:
          moduleButtonType[i] = BUTTON_TRIGGER;
          Wire.beginTransmission(addr);
          Wire.write(0xFF);
          Wire.endTransmission();
          break;

        // ABXY identifier is 0x20
        case BUTTON_ABXY:
          moduleButtonType[i] = BUTTON_ABXY;
          Wire.beginTransmission(addr);
          Wire.write(0xFF);
          Wire.endTransmission();
          break;

        // DPAD identifier is 0x30
        case BUTTON_DPAD:
          moduleButtonType[i] = BUTTON_DPAD;
          Wire.beginTransmission(addr);
          Wire.write(0xFF);
          Wire.endTransmission();
          break;
      }
      continue;
    }

    // This is for the center module which has LEDs and home/start/select
    if (deviceLocation[i] == 0x26) {
      uint8_t buttonAddr = deviceLocation[i];

      // Write 1s to all IOExpander bits for reading
      Wire.beginTransmission(buttonAddr);
      Wire.write(0xFF);
      Wire.endTransmission();

    }
  }
}
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

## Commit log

2025-09-19 kicad model
    [Controller base.kicad_pcb, Controller base.kicad_sch, Input Modules.kicad_sch]
2025-09-20 update pcb
    [Controller base.kicad_pcb, Controller base.kicad_sch]
2025-09-20 made new version
    [Controller base V0.5.kicad_pcb, Controller base V0.5.kicad_sch, Input Modules.kicad_sch]
2025-09-25 .6 done
    [Controller base V0.5.kicad_pcb, Controller base V0.6.kicad_pcb, Controller base V0.6.kicad_sch]
2025-09-26 updated carrier board
    [Controller base V0.6.kicad_pcb, Controller base V0.6.kicad_sch, Input Modules.kicad_sch]
2025-09-26 updated liby used
    [Controller base V0.6.kicad_pcb, Controller base V0.6.kicad_sch, Input Modules.kicad_sch]
2025-09-26 generated bom
    [Controller base V0.6.csv, Controller base V0.6.kicad_sch]
2025-09-26 added logo and date
    [Controller base V0.6.kicad_pcb]
2025-09-26 centered components
    [Controller base V0.6.kicad_pcb]
2025-10-03 slimed down files
    [Controller base V0.6.kicad_pcb, Controller base V0.6.kicad_sch, Input Modules.kicad_sch]
2025-10-03 current PCBs
    [Controller base V0.5.kicad_pcb, Controller base V0.5.kicad_sch, Controller base.kicad_pcb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]
2025-10-09 Initial Module PCBs
    [COM-09032.step, OSMC_Module_Buttons.kicad_pcb, OSMC_Module_Buttons.kicad_sch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]
2025-10-11 added test points
    [Controller base V1.kicad_pcb, Controller base V1.kicad_sch, MCU Carrier Board.kicad_pcb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]
2025-10-11 trace update
    [Controller base V1.kicad_pcb]
2025-10-11 updated traces and labels
    [Controller base V1.kicad_pcb]
2025-10-11 updated footprints
    [MCU Carrier Board.kicad_pcb, MCU Carrier Board.kicad_sch]
2025-10-11 track update
    [Controller base V1.kicad_pcb]
2025-10-11 update tracks
    [Controller base V1.kicad_pcb]
2025-10-14 updated power trace for expansion
    made where there is 5v to carrier board for future batter expansion
    [Controller base V1.kicad_pcb, Controller base V1.kicad_sch]
2025-10-14 change pin headers
    [MCU Carrier Board V1.1.kicad_pcb, MCU Carrier Board V1.1.kicad_sch]
2025-10-14 update traces
    [MCU Carrier Board V1.1.kicad_pcb]
2025-10-15 added mounting holes
    [OSMC_Module_Receiver.kicad_pcb, OSMC_Module_Receiver.kicad_sch]
2025-10-15 refile zones
    [OSMC_Module_Receiver.kicad_pcb]
2025-10-15 refill zones
    [OSMC_Module_Receiver.kicad_pcb]
2025-11-05 update boards for prodution
    [MCU Carrier Board V1.1.kicad_pcb]
2025-12-02 Merged files for Semester 1
    All notable files from past branches merged to this one branch with the latest codes.
    For use next Semester and organization
    [MCU Carrier Board V1.2.kicad_pcb, MCU Carrier Board V1.2.kicad_sch, OSMC Assembly.step]
2025-12-04 gerber files generated
    [bom.csv, designators.csv, positions.csv]
2025-12-05 slim down
    [COM-09032.step, Controller base V0.6.csv, Controller base V0.6.kicad_pcb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]
2025-12-05 more files
    [MC dev board carrier.kicad_pcb, MC dev board carrier.kicad_sch, MCU Carrier Board V1.1.kicad_pcb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]
2025-12-06 Squashed commit of the following:
    commit bee188ac67190d8f69e02bf0fbf3a9b0818b590d
    Author: Koalaven <102919896+Koalaven@users.noreply.github.com>
    Date: Thu Dec 4 21:13:27 2025 -0500
    commit 6b35f9c097d493935acfd4adb1660864742cfc16
    Author: Koalaven <102919896+Koalaven@users.noreply.github.com>
    Date: Thu Dec 4 21:11:45 2025 -0500
    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
    [COM-09032.step, Controller base V0.6.csv, Controller base V0.6.kicad_pcb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]
2026-01-16 module design
    [Modules.kicad_pcb, Modules.kicad_sch]
2026-01-21 module spec update
    [Modules.kicad_pcb, Modules.kicad_sch]
2026-01-23 updated templet and renamed lib files
    [Joystick.kicad_pcb, Modules.kicad_pcb, Modules.kicad_sch]
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2026-01-28 started routing
    [Modules.kicad_sch, attachment.kicad_sch, reciver board.kicad_pcb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]
2026-02-09 added module boards
    [Joystick.kicad_pcb, Joystick.kicad_sch, OSMC_Module_Bumpers.kicad_pcb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]
2026-02-09 completed receiver board w/ translators
    [Modules.kicad_sch, OSMC_Receiver.kicad_pcb, OSMC_Receiver.kicad_sch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]
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2026-02-11 cleared via and traces
    [OSMC_Module_Buttons.kicad_pcb, OSMC_Module_Buttons.kicad_sch]
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2026-02-18 update to modules gerbers produced
    [OSMC_Module_Bumpers.kicad_pcb, OSMC_Module_Buttons.kicad_pcb, OSMC_Module_Buttons.kicad_sch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]
2026-02-23 Create OSMC_Shell2.stl
    First version of the shell - still needs room for the bottom module, hole for wired connection, and holes for leds
    [OSMC_Shell2.stl]
2026-02-26 fixed diode direction
    [OSMC_Module_Buttons.kicad_sch, OSMC_Module_Master.kicad_sch, OSMC_Receiver.kicad_pcb]
2026-02-27 created all gerber zips
    [OSMC_Module_Bumpers.kicad_pcb, OSMC_Module_Buttons.kicad_pcb, OSMC_Module_Buttons_Click.kicad_pcb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]
2026-03-09 consolidated button and nav boards into one
    [OSMC_Module_Buttons-Nav.kicad_pcb, OSMC_Module_Buttons-Nav.kicad_sch]
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2026-03-12 more hand solderable joystick
    [OSMC_Module_Joystick_V2.kicad_pcb, OSMC_Module_Joystick_V2.kicad_sch]
2026-03-30 update to pcb, fixed i2c lines for bus 0 and 1
    [I2CConfig.kicad_sch, Modules.kicad_sch, OSMC_Module_Joystick_V2.kicad_pcb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]
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2026-04-01 Add files via upload
    Adding the case STLs for the modules and the alternate controller case.
    [Button Cap SMD.stl, Button Cap Taller.stl, OSMC_Body.stl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]
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2026-04-22 Update Assembly guide.md
    Fixed my broken links
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
